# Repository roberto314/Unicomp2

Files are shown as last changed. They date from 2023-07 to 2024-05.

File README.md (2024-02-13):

# UNICOMP #

A modular 8-bit Computer able to recreate (nearly) every microcomputer of the mid 70s to early 80s 
in Hardware without FPGAs (although an FPGA can be added). Can also be used as a teaching tool for:

* VHDL or Verilog
* C
* RTOS (STM32F401 runs ChibiOS Link: https://www.chibios.org)
* Python
* bash and linux in general (Olimex board runs linux with fbterm and tmux)
* Harwaredesign
* Timing of CPUs
* maybe Assembler
* SPI and I2C Interfaces
* CPLDs and FPGAs

It is different from other designs because of these points:

* it uses a 3.3V only Bus,
* it uses fast RAM for chipselect with two byte resolution over the whole 1MB range,
* it uses one SRAM for RAM and ROM replacement (can be write writeprotected) with 512kB (1MB possible),
* it uses a clock generator chip (DS1085) - no more crystals to change,
* it is configureable via STM32 (RAM and ROM content, Clock frequency, chip select lines),
* it can program the CPLDs (only XC9572 and XC9536 tested) from the olimex board - no external programmer and no cables to connect,
* Board size is 100mm x 100mm - no backplane (like the PC/104 standard. Link: https://en.wikipedia.org/wiki/PC/104).
* and maybe most convenient: it can change RAM and ROM content on the fly without crashing the CPU. 
  For example starting the Apple I, going into Basic and uploading the program in about half a second is really nice.

Version 2.00

Unicomp plus Logic Analyzer:
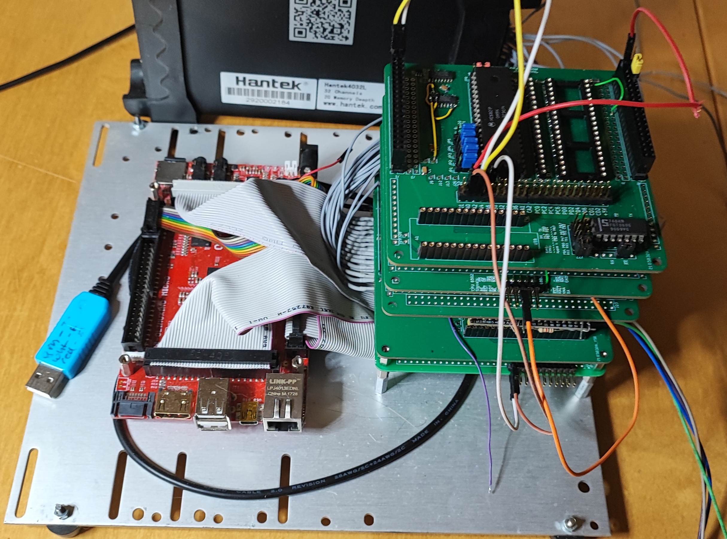
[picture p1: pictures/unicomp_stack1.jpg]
Unicomp plus Logic analyzer


### Unicomp modules ###

* Input board:
	- a simple board to connect the signals to a linux SBC like a Raspberry Pi or an Olimex A20
	- also generates the main clock with a DS1085 chip (in v2 this will be moved to the RAMROM board).
	- no CPLD

* CPU board:
	- can be any 8-bit CPU (6502, 6802, 6809, 68008, 6803, 8051,...)
	- a CPLD (XC9572) for clock generation and glue logic

6502 Board:
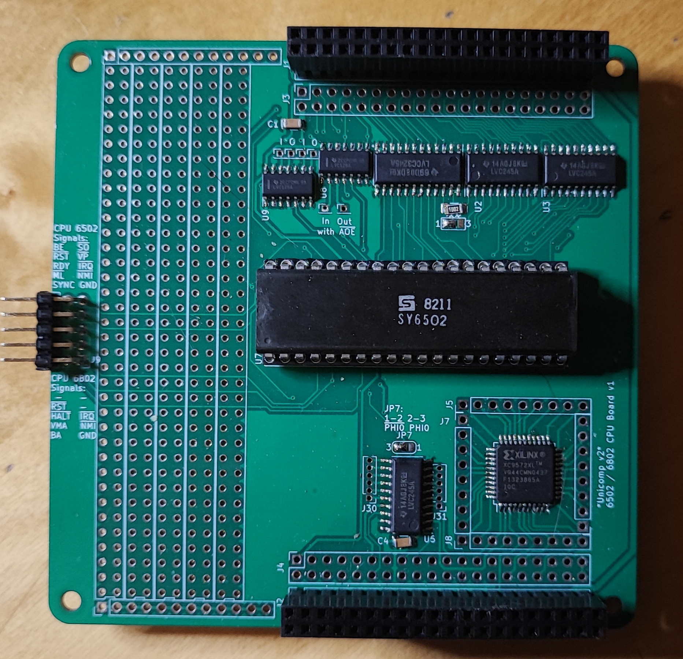
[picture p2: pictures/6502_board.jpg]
6502 Board


* Multi Serial boaŕd:
	- suggested chip select #0
	- two chip selects on board (second one not connected, but broken out)
	- can be used with the following serial interface chips: MC6850, MOS6551, MOS6552 or pin compatible
	- SRAM for address decoding

Multi Serial Board:
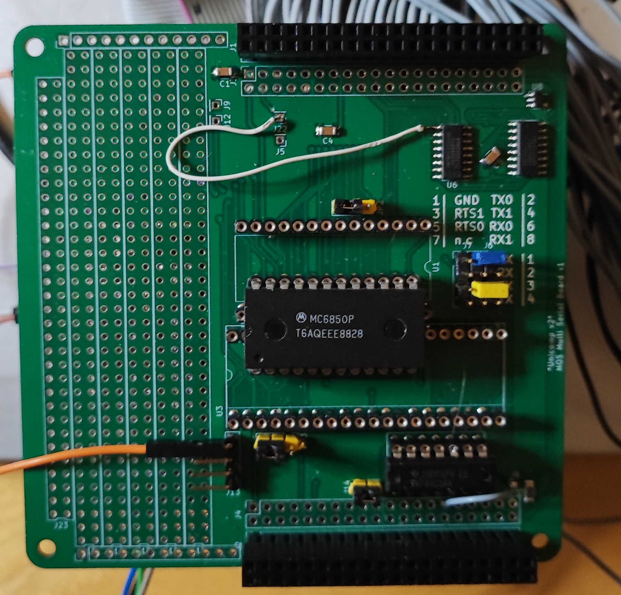
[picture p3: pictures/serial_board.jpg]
Multi Serial Board


* Multi Parallel boaŕd:
	- suggested chip select #1
	- two chip selects on board
	- can be used with the following parallel interface chips: MC6820, MC6821, MOS6520, MOS6521, MOS6522, MOS6526, MOS8520, MOS6532 in the first slot
    - the first slot can additionally mimic a MOS6530
	- the second slot can accommodate a MOS6522 or pin compatible
    - SRAM for address decoding

* RAMROM board:
	- chip select fixed at #14 (for chipselect RAM) and #15 (rom content)
	- 512k of SRAM plus an extra RAM for address decoding
	- a STM32F401 'blackpill' board to fill the SRAMs with data over USB port from the SBC
	- USB shell on the STM32 to change ROM content on the fly
	- also configures the Address Range of all peripheral modules

* Prototype board:
	- empty board for prototyping
	- no CPLD
    - SRAM for address decoding

* MAX-II (EPM240) board:
	- CPLD plus Buffers

* self made module:
	- chip select can be any non-used line in the Range from 0 to 13.
	- size is 100mm x 100mm
	- there is the prototype board in the repository for the position of the connectors and also the labels (pinout)

### Configuration RAM ###

The configuration is done with 128kx8 fast ram on the peripheral boards. These will be configured from the STM32F401.
One bit is for one Output (of which there are two) and for two addresses (resolution for chipselect is 2 bytes).
The cs = 15 is for writing the main RAM, cs = 14 is the chip select for the RAMROM board.
The rest is free. With two chip select lines per board these are 28 lines.
One byte in the mapping ram has the following format:

| 7 | 6 | 5 | 4 | 3 | 2 | 1 | 0 | Bits |
|---|---|---|---|---|---|---|---|---|
| 7,6  | 5,4  | 3,2  | 1,0  | 7,6  | 5,4  | 3,2  | 1,0  | Address |
| /CS0 | /CS0 | /CS0 | /CS0 | /CS1 | /CS1 | /CS1 | /CS1 | Peripheral |
| /CS  | /CS  | /CS  | /CS  | WP | WP | WP | WP | RAMROM |

So 128k are good for 128kx8 Bytes of Addressspace (=1MByte)
The data gets transferred to the STM32 in compact form. Only the Start address, the chipselect and the bitmask (which is Low-active) for every addresses where someting changes are transferred.
A 0xFE for a bitmask means Peripheral chipselect /CS1 is active for two addresses. If the board is the RAMROM board the low nibble is Writeprotect (Hi-active).

A simple configuration block looks líke this:

    (RAM: 0-9FFF, ACIA0: A000-A001, ACIA1: A010-A011, ROM: C000-FFFF)

    00 00 00 0E 00  :  RAM
    00 A0 00 00 EF  :  ACIA0
    00 A0 02 FF FF  :  HOLE
    00 A0 10 00 FE  :  ACIA1
    00 A0 12 FF FF  :  HOLE
    00 C0 00 0E 0F  :  ROM
    01 00 00 FF FF  :  END
    00 00 00        :  noting further

### Working Recreations of old computers ###

| Name | prim. IO | chips used | os | weblink |
|---|---|---|---|---|
| Grant Searle 6502 board  | serial | MOS6502, MC6850 | OSI Basic |Link: http://searle.x10host.com/6502/Simple6502.html |
| Daryl Rictor 6502 board  | serial | MOS6502, R6551 | SBC-2 (monitor only) |Link: https://sbc.rictor.org/info2.html |
| Daryl Rictor 6502 board  | serial | MOS6502, MC6850 | SBC-2 (monitor only) |Link: https://sbc.rictor.org/info2.html |
| SYM1 | serial | MOS6502, UM6532 | SYM1 ( +BASIC +RAE) |Link: http://retro.hansotten.nl/6502-sbc/synertek-sym-ktm/sym-1/ |
| KIM1 | serial | MOS6502, UM6532 | KIM1 |Link: http://retro.hansotten.nl/6502-sbc/kim-1-manuals-and-software/ |
| Apple I | serial | MOS6502, MĆ6821 (plus Arduino)| Wozmon + BASIC |Link: http://retro.hansotten.nl/6502-sbc/apple-1/ |
| Motorola MEK D2 | serial | MC6802, MĆ6850 | newbug, xswtbug, mondeb |Link: https://www.retrotechnology.com/restore/smithbug.html |
| Motorola MEK D1 | serial | MC6802, MĆ6821 (plus Arduino) | Mikbug |Link: https://www.retrotechnology.com/restore/smithbug.html |
| Heathkit ET3400 | serial | MC6802, MĆ6850 | MITS BASIC, TSC MicroBASIC,... |Link: https://github.com/jefftranter |
| SWTPC 6800 | serial | MC6802, MĆ6821 (plus Arduino) | Mikbug |Link: https://deramp.com/swtpc.com/ |
| SWTPC 6800 | serial | MC6802, MĆ6850 | SWTBUG, SWTBUGA, Mondeb, xSWTBUG |Link: https://deramp.com/swtpc.com/ |
| DREAM 6800 | BAS (Video) | MC6802, MAX-II | DREAM operating System (Chip8) |Link: http://www.mjbauer.biz/DREAM6800.htm |
| HD6303 Board (Eric Klaus)| serial | HD6303 | Monitor +BASIC |Link: https://sites.google.com/site/ericmklaus/projects-1/hd6303cpuboard |
| MC3 Computer | serial | HD6303 | Monitor |Link: https://www.waveguide.se/?article=mc3-a-diy-8-bit-computer |
| Psion Organizer I | LCD | HD6303 | Psion OS |Link: https://www.jaapsch.net/psion/index.htm |

### linux single board computer (SBC) ###

I uses an olimex A20 SBC (olinuxino A20) which has a lot of peripherals (4x UART, 2x SPI, 2x I2C, a lot of GPIOs, SATA, 2x SDCARD, VGA, HDMI, LAN,...)
and it is open hardware. The board is connected with three 40 pin cables (like old IDE cables) plus two 10 pin cables to the input board.

To access all the peripherals i use python with the pyA20 library here: https://pypi.org/project/pyA20/   
The debian image (bullseye minimal) can be found at: http://images.olimex.com/release/a20/   
To configure the image after downloading there are helper scripts in the unicomp folder under: olimex Board/config 
I use fbterm and tmux for a nice terminal output. Here are some pictures:   
tmux main window:
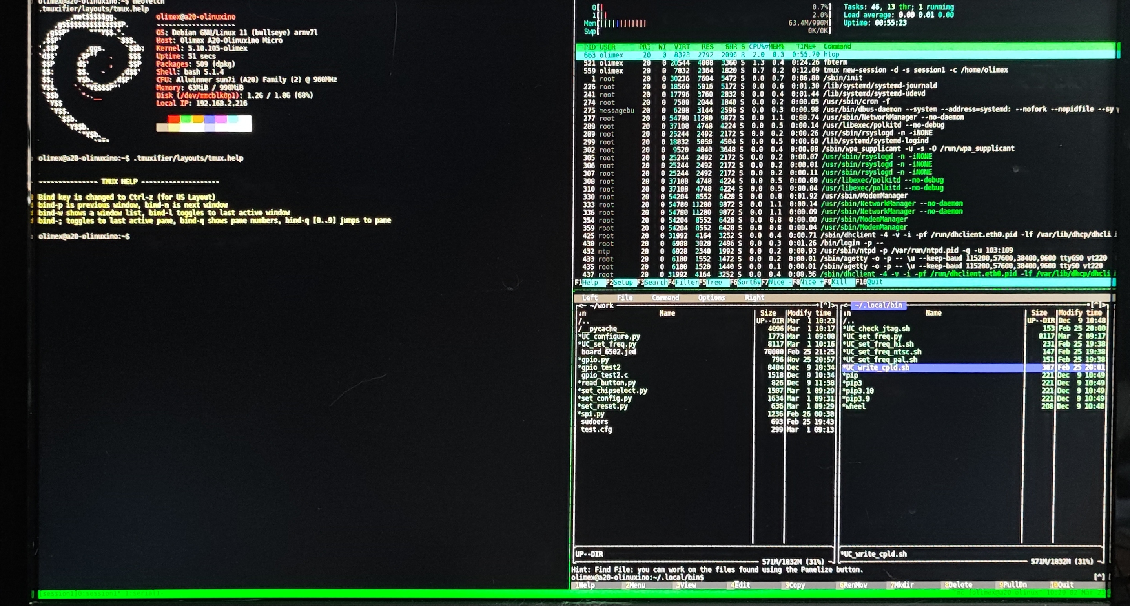
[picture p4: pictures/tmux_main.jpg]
tmux main window


tmux serial window:
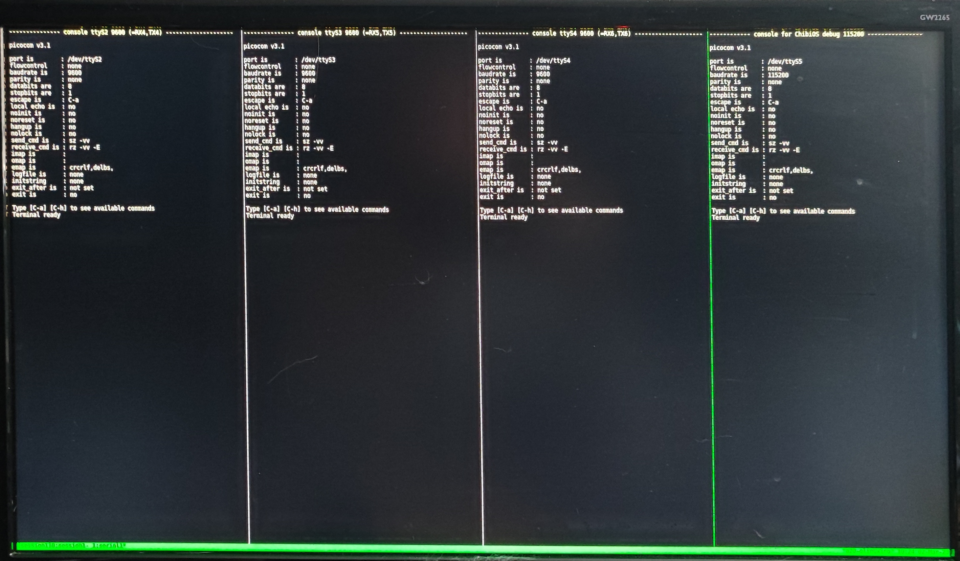
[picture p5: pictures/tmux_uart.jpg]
tmux uart window


### python helper scripts ###

-- all scripts have to be executed with sudo bacause of direct hardware access!

* set_reset.py [0,1,xx]
	- sets the reset line high or low (low = active)
	- if value is anything other than 0 or 1 then a reset of approx. 10mS will be performed.

* UC_check_jtag.sh
	- looks for devices (CPLDs) in the JTAG chain.

* UC_write_cpld.sh [0..?] [.jed file]
	- writes the .jed file to the selected devices
	- Example: sudo UC_write_cpld 0 filename.jed - writes .jed file to cpld zero

* Prepare new SD-Card:
    - copy image to sd-card:
    sudo dd if=A20-OLinuXino-bullseye-minimal-20230515-130040.img of=/dev/sdb bs=1k status=progress
    - start olimex and login with 'olimex/olimex'
    - change password with: 'sudo passwd olimex' to something shorter like 'olim'
    - alternatively: delete passwird: 'sudo passwd -d olimex'
    - make update: 'sudo apt update && sudo apt upgrade'
    - install minimal components: 'sudo apt install git mc'
    - clone github repository: 'git clone https://github.com/roberto314/Unicomp2.git'
    - open midnight commander: 'mc'
    - navigate into Unicomp2/olimex_board/config
    - Run script: 'install_software.sh'
    - Run script: 'copy_files.sh'
    - restart

### CPLD programming ###

* compiling the vhdl (or verilog) code must be done on a computer with the Xilinx ISE 14.7 toolchain installed.
 Link: https://www.xilinx.com/support/download/index.html/content/xilinx/en/downloadNav/vivado-design-tools/archive-ise.html

* compiling itself can be done inside ISE or with the supplied makefile (look inside the bord directory in cpld firmware)

* a simple **make** will compile the firmware and a **make transfer** will transfer the file to the sbc (if you changed the ip address to your address inside the makefile and the path inside project.cfg)

* on the sbc in the work folder one can find the .jed file. For programming type: **UC_write_cpld [JTAG-position] [filename.jed]**

### Used Software and OS ###

* Linux Mint (20.3 cinnamon) (Link: https://linuxmint.com/)
* Sublime Text 3 (Link: https://www.sublimetext.com/)
* 010 Editor (Hex Editor) (Link: https://www.sweetscape.com/010editor/)
* Chibi Studio 20 (IDE for ChibiOS) (Link: https://www.chibios.org/dokuwiki/doku.php?id=chibios:products:chibistudio:start)
* Wavedrom (2.9.1) (Link: https://wavedrom.com/)
* Pulseview (0.5.0-nightly Appimaage) (Part of sigrok) (Link: https://sigrok.org/wiki/PulseView)
* Logisim-Evolution (3.8.0) (Link: https://github.com/logisim-evolution/logisim-evolution)
* Quartus (13.0.1 Build232 Web Edition - 64 Bit) for MAX-II
* Xilinx ISE (14.7 - 64 Bit) for XC9572

### Used Hardware ###

* Oscilloscope: Rigol DS1054Z (4 channel)
* Logic Analyzer: Hantek 4032L (32 channel)

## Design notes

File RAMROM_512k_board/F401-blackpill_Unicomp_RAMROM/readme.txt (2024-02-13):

*****************************************************************************
** ChibiOS/RT port for ARM-Cortex-M4 STM32F407.                            **
*****************************************************************************

** TARGET **

The demo runs on an STM32F411 or STM32F401 blackpill board.
(25MHz Crystal)
Serial Port over USB (also Debug Interface).
Serial 115200 Bd

Build:
Build with eclipse or simply type "make" in the code folder.

-----------------   WORK in Progress

Functions:

Pinout:
PA0  - OFF/ON (write enable strobe)
PA1  - SEL4 (which chip gets the write enable)
PA2  - TX2 (Console + Debug)
PA3  - RX2 (Console + Debug)
PA4  - /CS_FLASH - free (/DATOE in prev. Version)
PA5  - SCK1
PA6  - MISO1
PA7  - MOSI1
PA8  - CNT (count up)
PA9  - /MWR (not used)
PA10 - /RAMCSOR (RAM CS override) - not used
PA11 - USD DM (Ostrich)
PA12 - USB DP (Ostrich)
PA13 - SWDIO
PA14 - SWCLK
PA15 - /MRD (not used)

PB0  - free
PB1  - free
PB2  - /DATOE
PB3  - free
PB4  - PWM Output (TIM3/1)
PB5  - free
PB6  - SCL
PB7  - SDA
PB8  - CTRL1 (CTRL1 for clock chip)
PB9  - /BUSFREE (signal if bus is free)
PB10 - TRST (Target Reset)

PB12 - /PLD (Parallel Load into shift register)
PB13 - /CNTOE (Counter Output on)
PB14 - CPR (Counter Latch)
PB15 - /MRC (Counter Reset)

PC13 - SEL0 (which chip gets the write enable)
PC14 - SEL1 (which chip gets the write enable)
PC15 - SEL2 (which chip gets the write enable)

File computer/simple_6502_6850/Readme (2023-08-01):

Source: https://sbc.rictor.org/sbcos.html
Daryl's Computer Hobby Page
Here is a list of my operating system's commands:

This is a cut-down version from this thread:
http://forum.6502.org/viewtopic.php?f=2&t=2566

65C02 Monitor V5.1 Ready
with Enhanced Basic Interpreter (c) Lee Davison
(Press ? for help)

Syntax = {} required, [] optional, HHHH hex address, DD hex data

[HHHH]{.HHHH}{Return} - Hex dump range of addresses (16 per line)
[HHHH]{:DD}[ DD]{Return} - Change data bytes
[HHHH]{G}{Return} - Execute a program (use RTS to return to monitor)
{HHHH.HHHH>HHHH{I}{Return} - move range at 2nd HHHH down to 1st to 3rd HHHH
{HHHH.HHHH>HHHH{M}{Return} - Move range at 1st HHHH thru 2nd to 3rd HHHH
[HHHH][ HHHH]{Q}{Return} - Text dump address(s)
[HHHH]{.HHHH}{Q}{Return} - Text dump range of addresses (16 per line)
{R}{Return} - Print register contents from memory locations
{V}{Return} - Monitor Version

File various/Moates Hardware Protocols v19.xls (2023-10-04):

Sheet: Overview
Control Commands for Moates.Net Hardware
Note: Commands should be sent via standard serial port communication 8-N-1. Don't use wait states, delays, or anything like that. Spew bytes/strings to the port, and poll the port mercilessly for responses. You shouldn't see lag any more than 10-20 mS at the most except when commands take time to execute (programming/erasing chips). Checksums (CS) are just 8-bit additive of the rest of the request, no carry. Values such as 'O' are alphanumeric. Lowercase letters are hex numeric. Other values are mostly hex. A response of '?' or other when expecting 'O' or other valid response indicates either a failed checksum, failed command execution, or other failure. Also, when uploading content for emulation, if you're uploading a 16k or 32k file, please keep in mind that it needs to go to the 'end' of the 64k emulation space. For instance, if you upload a 32k file, upload it from 8000-FFFF.

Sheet: Unicomp
Unicomp v2 Command Set | This is based on the Ostrich (v1) Protocol!
Description | Send | Receive | Notes
Request version. | 'V'+'V' | x+y+A (ex. 10+07+'O') | x is typically 15 for Unicomp or Nucleo NVRAM Prog., 10 for Ostrich, 5 for BURN1, and 2 for AutoProm. Y will vary with firmware revision. A will be an alphanumeric, and will be A for APU1, O for Ostrich, N for Nucleo NVRAM Programmer, U for Unicomp and B for BURN1 typically. | implemented in Python script | implemented in C code
Write to a memory area, non-disruptive to target device operation. | 'W'+n+MSB+LSB+B1+..+Bn+CS or 'W'+n+RB1+RB2+MSBc+LSBc+B1c+..+Bn+CS when crypted. | 'O' | In the case of the Ostrich, this writes to the bank area that is selected for R/W (think of as the MMSB). In all cases, it sends 'n' bytes B1…Bn starting at emulation address MSB:LSB. For 256 bytes, use n=0. | implemented in Python script | implemented in C code
Reads from an emulation memory area. Is usually disruptive to the emulation. | 'R'+n+MSB+LSB+CS or 'R'+n+RB1+RB2+MSBc+LSBc+CS with B1e+..+Bne+CS as response when crypted. | B1+..+Bn+CS | In the case of the Ostrich, this reads from the bank area that is selected for R/W (think of as the MMSB). In all cases, it returns 'n' bytes B1…Bn starting at emulation address MSB:LSB. For 256 bytes, use n=0. |  | implemented in C code
Bulk Write to memory, very fast. | 'Z'+'W'+n+MMSB+MSB+B1+..+B(n*256)+CS or 'Z'+'W'+n+RB1+RB2+MMSBc+MSBc+B1c+..+B(n*256)c+CS when crypted. | 'O' | Rapid write, sends n blocks of 256 bytes to memory starting at MSB:LSB. Great for initial uploads, typically 4k at a time (n=16). Theoretically can do a full 64k (n=256) all in one block, but speedups are only seen up to about 4k in terms of USB bus overhead elimination. The MMSB value will only be taken into account when the bank response of a 'B'+'R'+'R'+ CS = 8. |  | implemented in C code
Bulk Read from memory, very fast. | 'Z'+'R'+n+MMSB+MSB+CS or 'Z'+'R'+n+RB1+RB2+MMSBc+MSBc+CS with B1c+..+B(n*256)c+CS as response when crypted. | B1+..+B(n*256)+CS | Rapid read, retrieves n blocks of 256 bytes from memory starting at MSB:LSB. Great for reading back full binary. Same guidelines apply as for the 'Z' bulk write command. The MMSB value will only be taken into account when the bank response of a 'B'+'R'+'R'+ CS = 8. | implemented in Python script | implemented in C code
Write Configuration Data | 'C’+n+B1+..+Bn+CS | 'O’ | Send Configuration Data (max. 256 Bytes) | implemented in Python script | implemented in C code
Write Clock Data | 'DW’+11+B1+..+Bn+CS | 'O’ | Receive Clock Data (11 Bytes) | implemented in Python script | implemented in C code
Read Clock Data | 'DR’+CS | 'O’ | Send Clock Data (11 Bytes) | implemented in Python script | implemented in C code
Write digital Pins | 'P’+1+B1+CS | 'O’ | Send Pin Data (one Byte) | implemented in Python script | implemented in C code
Select which emulation bank to read/write to/from. | 'B'+'R'+n+CS | 'O' | Valid values for n are 0-8. This setting will be persistent until power cycle, at which time it will reset to default of n=0.And you can send an '8' which will enable/present the entire 4 mbit of memory to the target device. And make the MMSB effective during bulk read/write cycles. | implemented in Python script | implemented in C code
Select which bank to emulate from and make it persistent upon power cycle. | 'B'+'S'+n+CS | 'O' | Valid values are from 0-8, and you can send an '8' which will enable/present the entire 4 mbit of memory to the target device. This is useful for multi-bank Ford applications in particular (EEC-V). Don't over-use this, since other applications might not use multibank and you want to return the emulator to a known state. Also, overuse will wear out the internal EEPROM where this info is stored. | implemented in Python script | implemented in C code
Read back which emulation bank is selected for read/write operations. | 'B'+'R'+'R'+CS | n | Values for n are 0-7. This is to check to see where your read 'R' and write 'W' commands will take effect. | implemented in Python script | implemented in C code
Select which bank to emulate from, ie. which one to present to car's computer (volatile selection, lost on power cycle). | 'B'+'E'+n+CS | 'O' | Valid values are from 0-7, and you can send an '8' which will enable/present the entire 4 mbit of memory to the target device. This is useful for multi-bank Ford applications in particular (EEC-V). | implemented in Python script | implemented in C code
Read back which bank is selected for emulation in the volatile sense. | 'B'+'E'+'R'+CS or 'B'+'E'+'E'+CS | n | Valid n values from 0-8. This is good for 'seeing where you're at' in terms of bank selection. This is the volatile value that is lost on startup. | implemented in Python script | implemented in C code
Read back which bank is selected for emulation in the persistent non-volatile sense. | 'B'+'E'+'S'+CS | n | Valid n values from 0-8. This is good for 'seeing where you're at' in terms of bank selection. This is the stored/startup value. | implemented in Python script | implemented in C code
Query serial number | ‘N’+’S’+CS | B0+B1+..+B8+CS | B0 is vendor ID byte, B1..B8 is serial number | implemented in Python script | implemented in C code
Change vendor ID byte | ‘N’+x+B1+..+B8+CS | 'O' | x is new vendor ID byte, B1..B8 is current serial number (must match)
Change serial number | ‘N’+’n’+C1+..+C8+CS | 'O' | C1..C8 is new serial number
Legacy Commands
Change baud rate. | 'S'+n+CS | 'O' | Valid values for n are 0 (920k) and 7 (115k=default, resets on powercycle). Initial response will be at the 'old' baud rate, and subsequent communication will be expected and occur at the 'new' baud rate. It is good practice to scan (using 'V'+'V') at both baud rates when looking for the device. For revision 10.12.O firmware, value is locked at 0, 921.6k. Return from attempt will be 'O', but divisor of 0 will stick. To use default of 115.2k and allow changes, use firmware 10.10.O or older. | implemented in Python script | implemented in C code
Write to a memory area, non-disruptive to target device operation. | 'w'+n+MSB+LSB+B1+..+Bn+CS | 'O' | Sends 'n' bytes B1…Bn starting at emulation address MSB:LSB. For 256 bytes, use n=0.
Write to a memory area, non-disruptive to target device operation. Use legacy 'block' mode. | 'X'+n+MSB+LSB+B1+..+Bn+CS | CSmsb+CSlsb | Sends 'n' bytes B1…Bn starting at emulation address MSB:LSB. For 256 bytes, use n=0. Return is the two-byte carry checksum of the actual B1..Bn data packet (not including header etc).
Reads from an emulation memory area. Is usually disruptive to the emulation. | 'r'+n+MSB+LSB+CS | B1+..+Bn+CS | Returns 'n' bytes B1…Bn starting at emulation address MSB:LSB. For 256 bytes, use n=0.

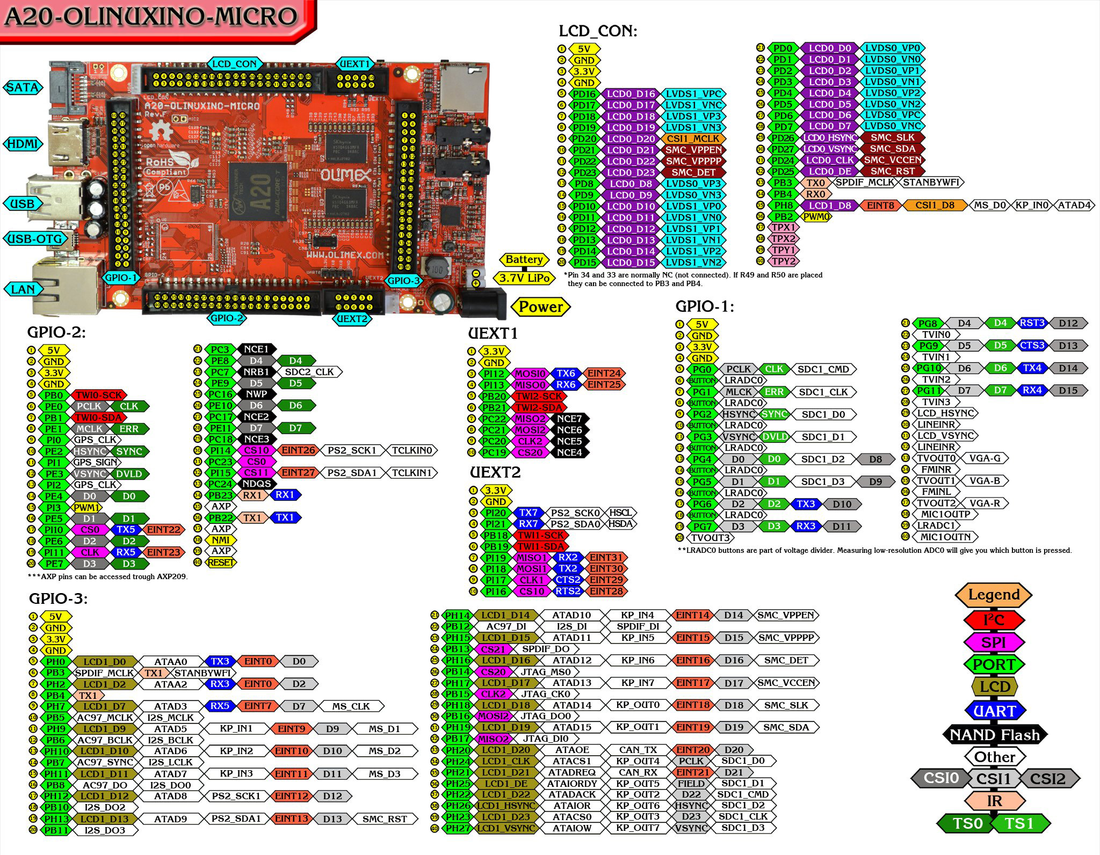
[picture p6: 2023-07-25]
olimex_board/schematic/pinout.jpg

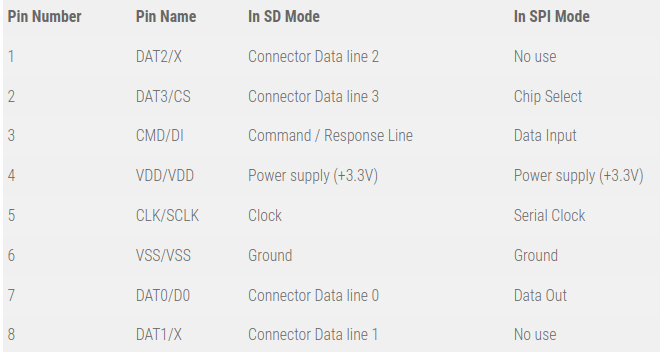
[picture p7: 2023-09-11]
CPLD_board/SD_Pinout.png

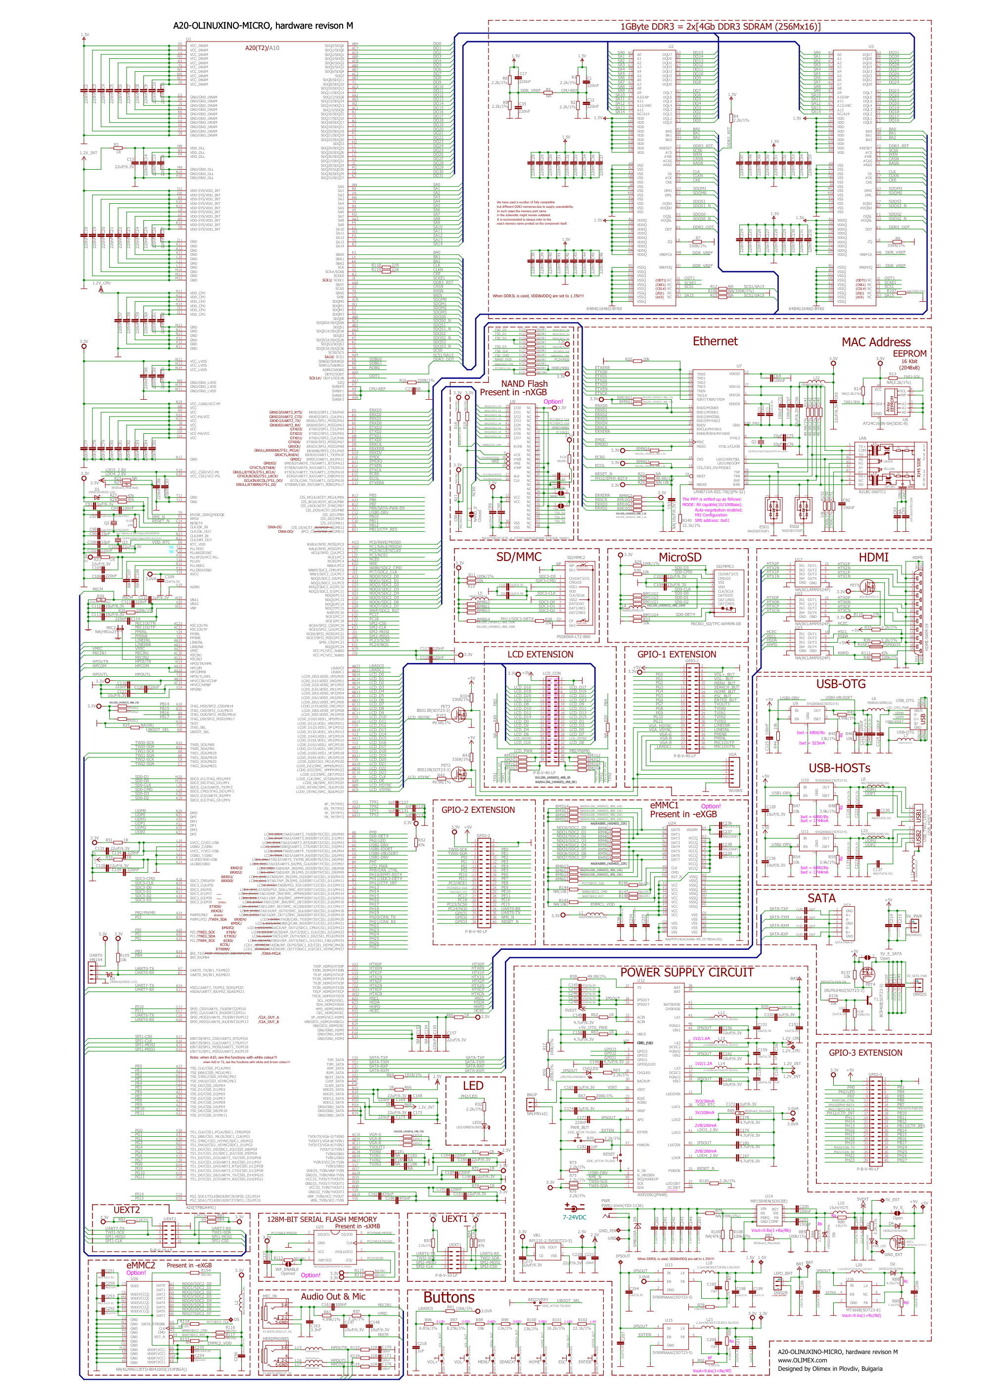
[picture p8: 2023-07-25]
olimex_board/schematic/canvas.png

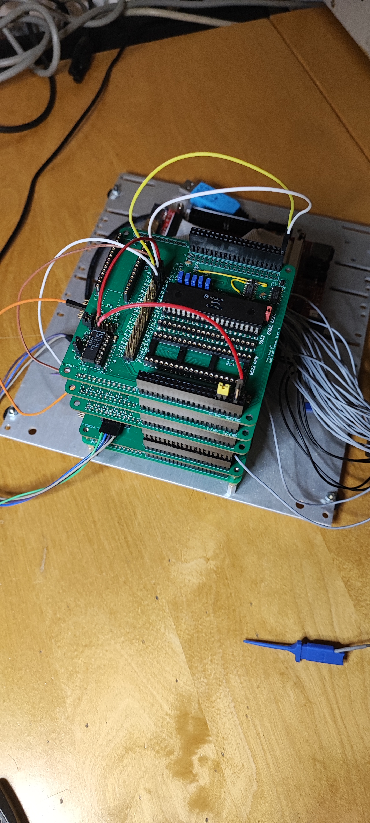
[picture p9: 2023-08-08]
pictures/unicomp_stack_side.jpg

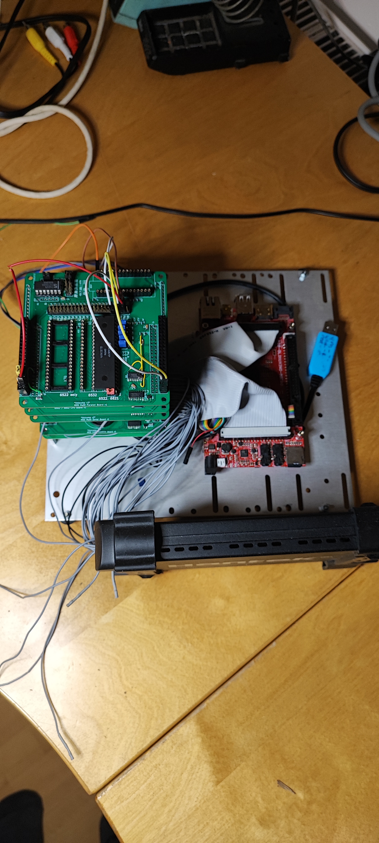
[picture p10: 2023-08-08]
pictures/unicomp_stack_top.jpg

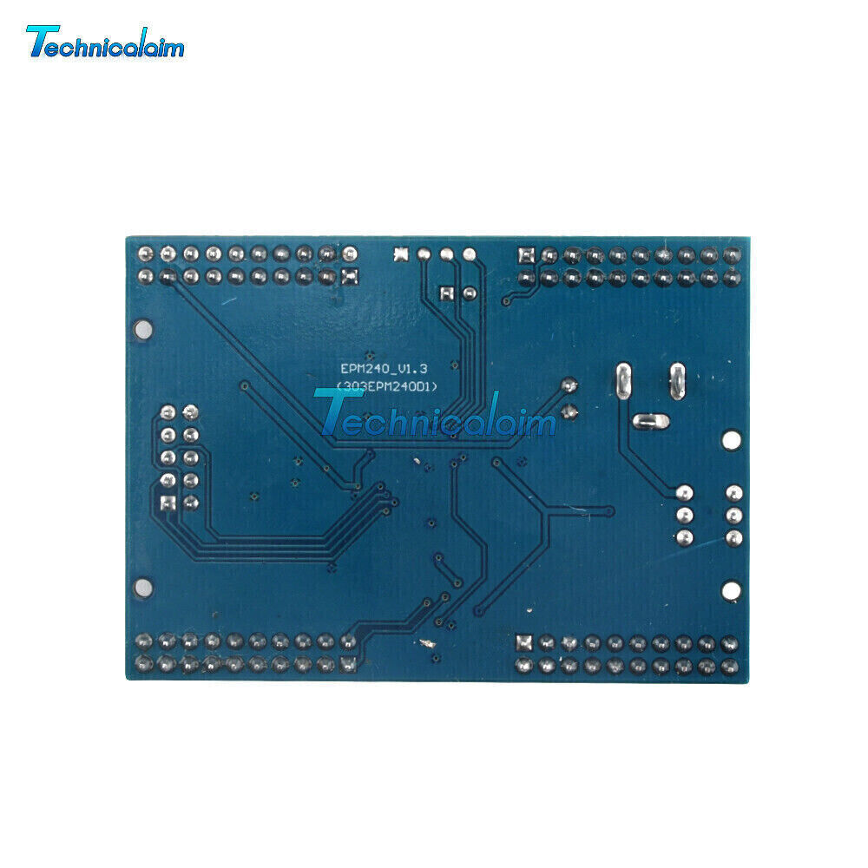
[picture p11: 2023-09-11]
CPLD_board/ebay-board-EPM240_back.jpg

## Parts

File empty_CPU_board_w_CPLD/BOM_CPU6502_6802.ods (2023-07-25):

Id | Designator | Footprint | Quantity | Designation | Supplier and ref
 |  | ICs
3 | U2,U3,U6,U4 | SO-20_5.3x12.6mm_P1.27mm | 4 | SN74ABT245BNSR
16 | U9,U8 | SOIC-14_3.9x8.7mm_P1.27mm | 2 | SN74ACT125DG
19 | U1 | TQFP-44_10x10mm_P0.8mm | 1 | XC9572VQ44
 |  | Sockets and Headers
2 | J8,J5 | PinHeader_1x09_P2.54mm_Vertical | 2 | Conn_01x09
6 | J1,J4,J2,J3 | PinSocket_2x20_P2.54mm_Vertical | 4 | BUS
7 | J31,J30 | PinHeader_1x06_P1.27mm_Vertical | 2 | Conn_01x06
10 | JP9 | PinHeader_1x02_P2.54mm_Vertical | 1 | DOE_En
11 | U7 | DIP-40_W15.24mm_Socket_LongPads | 1 | W65C02SxP
13 | J20,J21 | PinHeader_1x12_P2.54mm_Vertical | 2 | Conn_01x12
14 | J9 | PinHeader_2x05_P2.54mm_Horizontal | 1 | Conn_02x05_Odd_Even
15 | J6,J7 | PinHeader_1x08_P2.54mm_Vertical | 2 | Conn_01x08
17 | JP8 | PinHeader_1x02_P2.54mm_Vertical | 1 | AOE_En
 |  | R and C
1 | C5,C4,C1,C2,C7,C8,C3,C6 | C_1206_3216Metric | 8 | 100n
8 | R3 | R_1206_3216Metric_Pad1.30x1.75mm_HandSolder | 1 | 1k
9 | R4,R7,R5,R6,R2,R8,R1 | R_1206_3216Metric_Pad1.30x1.75mm_HandSolder | 7 | 10k

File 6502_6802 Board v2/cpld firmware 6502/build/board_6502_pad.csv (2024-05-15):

Release 8.1i - Fit P.20131013
Copyright(c) 1995-2003 Xilinx Inc. All rights reserved
5-15-2024 9:11PM
NOTE: This file is designed to be imported into a spreadsheet program
such as Microsoft Excel for viewing | printing and sorting. The comma ' | '
character is used as the data field separator.
This file is also designed to support parsing.
Input file: board_6502.ngd
output file: board_6502_pad.csv
Part type: xc9572xl
Speed grade: -10
Package: vq44
Pinout by Pin Number:
----- | ----- | ----- | ----- | ----- | ----- | ----- | ----- | ----- | -----
Pin Number | Signal Name | Pin Usage | Pin Name | Direction | IO Standard | IO Bank Number | {blank} | Slew Rate | Termination | {blank} | Voltage | Constraint
P1 | PH0 | O | I/O/GCK3 | OUTPUT
P2 | nPH0 | O | I/O | OUTPUT
P3 | CLKF | I | I/O | INPUT
P4 | GND |  | GND
P5 | TIE |  | I/O
P6 | TIE |  | I/O
P7 | TIE |  | I/O
P8 | TIE |  | I/O
P9 | TDI |  | TDI
P10 | TMS |  | TMS
P11 | TCK |  | TCK
P12 | TIE |  | I/O
P13 | TIE |  | I/O
P14 | TIE |  | I/O
P15 | VCC |  | VCCINT
P16 | TIE |  | I/O
P17 | GND |  | GND
P18 | TIE |  | I/O
P19 | TIE |  | I/O
P20 | TIE |  | I/O
P21 | TIE |  | I/O
P22 | TIE |  | I/O
P23 | TIE |  | I/O
P24 | TDO |  | TDO
P25 | GND |  | GND
P26 | VCC |  | VCCIO
P27 | TIE |  | I/O
P28 | TIE |  | I/O
P29 | TIE |  | I/O
P30 | TIE |  | I/O
P31 | nDOE | O | I/O | OUTPUT
P32 | nAOE | O | I/O | OUTPUT
P33 | nMWR | O | I/O/GSR | OUTPUT
P34 | nMRD | O | I/O/GTS2 | OUTPUT
P35 | VCC |  | VCCINT
P36 | RnW | I | I/O/GTS1 | INPUT
P37 | PHI2CPU | I | I/O | INPUT
P38 | TIE |  | I/O
P39 | TIE |  | I/O
P40 | TIE |  | I/O
P41 | TIE |  | I/O
P42 | TIE |  | I/O
P43 | nBUSFREE | O | I/O/GCK1 | OUTPUT
P44 | nRST | I | I/O/GCK2 | INPUT
To preserve the pinout above for future design iterations in
Project Navigator simply execute the (Lock Pins) process
located under the (Implement Design) process in a toolbox named
(Optional Implementation Tools) or invoke PIN2UCF from the
command line. The location constraints will be written into your
specified UCF file

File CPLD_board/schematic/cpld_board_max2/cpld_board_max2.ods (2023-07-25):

Id | Designator | Footprint | Quantity | Designation | Supplier and ref
5 | U1,U2,U4 | DIP-20_W7.62mm_Socket_LongPads | 3 | 74HCT245
 |  | Sockets and Headers
1 | J3,J1 | PinSocket_2x20_P2.54mm_Vertical | 2 | BUS-Master
2 | J6,J4 | PinHeader_2x20_P2.54mm_Horizontal | 2 | BUS-Angled
3 | J9,J2 | PinHeader_1x21_P2.54mm_Vertical | 2 | Conn_01x21
6 | J7,J8 | PinSocket_2x20_P2.54mm_Vertical | 2 | BUS-Master-BO
7 | J11,J12 | PinHeader_1x03_P2.54mm_Vertical | 2 | Conn_01x03
8 | J10 | PinHeader_2x03_P2.54mm_Vertical | 1 | GND
9 | J5 | PinHeader_2x03_P2.54mm_Vertical | 1 | VCC
 |  | R and C
10 | C3,C2,C1 | C_1206_3216Metric_Pad1.33x1.80mm_HandSolder | 3 | 100n

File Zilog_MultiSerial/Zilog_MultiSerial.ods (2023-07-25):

Id | Designator | Footprint | Quantity | Designation | Supplier and ref
21 | U1 | TQFP-44_10x10mm_P0.8mm | 1 | XC9572VQ44
23 | U2 | DIP-14_W7.62mm_Socket | 1 | 74HC14
 |  | Sockets and Headers
1 | J14,J13,J16,J28,J30,J29,J15 | PinHeader_1x01_P2.00mm_Vertical | 7 | .
2 | U4 | DIP-40_W15.24mm_Socket_LongPads | 1 | W65C22NxP
3 | J8,J5 | PinHeader_1x09_P2.54mm_Vertical | 2 | Conn_01x09
4 | J18,J19 | PinHeader_1x32_P2.54mm_Vertical | 2 | Conn_01x32
5 | J1,J4,J2,J3 | PinSocket_2x20_P2.54mm_Vertical | 4 | BUS
6 | J27 | PinHeader_2x05_P2.54mm_Vertical | 1 | .
8 | J12,J9 | PinHeader_1x01_P2.00mm_Vertical | 2 | Conn_01x01
9 | J26 | PinHeader_1x01_P2.00mm_Vertical | 1 | .Conn_01x01
10 | JP3,JP4,JP5,JP6,JP2,JP1 | PinHeader_1x03_P2.54mm_Vertical | 6 | .
13 | J17 | PinHeader_2x11_P2.54mm_Vertical | 1 | Conn_02x11_Odd_Even
14 | J10,J11 | PinHeader_1x06_P2.54mm_Vertical | 2 | .
15 | J20,J21 | PinHeader_1x12_P2.54mm_Vertical | 2 | Conn_01x12
16 | J6,J7 | PinHeader_1x08_P2.54mm_Vertical | 2 | Conn_01x08
20 | U3 | DIP-40_W15.24mm_Socket_LongPads | 1 | 6532
22 | A1 | Arduino_Nano | 1 | Arduino_Nano_v3.x
 |  | R and C
17 | C3,C1,C2,C7,C8,C6 | C_1206_3216Metric | 6 | 100n
19 | C4 | C_1206_3216Metric | 1 | 10n
7 | R1 | R_1206_3216Metric_Pad1.30x1.75mm_HandSolder | 1 | 1k

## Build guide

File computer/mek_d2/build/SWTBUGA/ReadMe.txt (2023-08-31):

SWTBUGA - Augmented SWTBUG

SWTBUGA adds the following enhancements to SWTBUG 1.0
    
  - Similar to the "O"ptional port prefix for the L, P,
    and E commands, a digit prefix (0-7) can be used to
    specify any port for an MP-S board to use for the L,
    P, and E commands (e.g., "2L" to load from port 2).

  - Following a load command, the I/O port address used
    is saved at $A046 which will load into register X if
    a "G" command is used to enter the loaded program.
    This is useful for a two-stage loader.

  - The "D"isk boot command has been fixed by adding a 
    delay for the motor to spin up and a check to see if
    the boot sector was read without errors. The boot
    operation is tried up to ten times. If a DC-x cont-
    roller is not detected, or boot from the DC-x fails,
    the a boot from a Percom controller is attempted
    if it's presence is detected at $C000. If that boot
    option is not present or fails, then control returns
    to SWTBUG.

  - The new "T"est memory command (SUMTEST) is followed
    by the low address and max address+1 of the memory
    range to be tested. The test runs until reset is
    pressed.

SWTBUGA maintains all of the entry points of the 
original SWTBUG. Since SWTBUGA is larger than 1K,
it must be located in an EPROM board on the bus and
the CPU board modified to allow off-board access to
$E000 through at least $E500 or so.

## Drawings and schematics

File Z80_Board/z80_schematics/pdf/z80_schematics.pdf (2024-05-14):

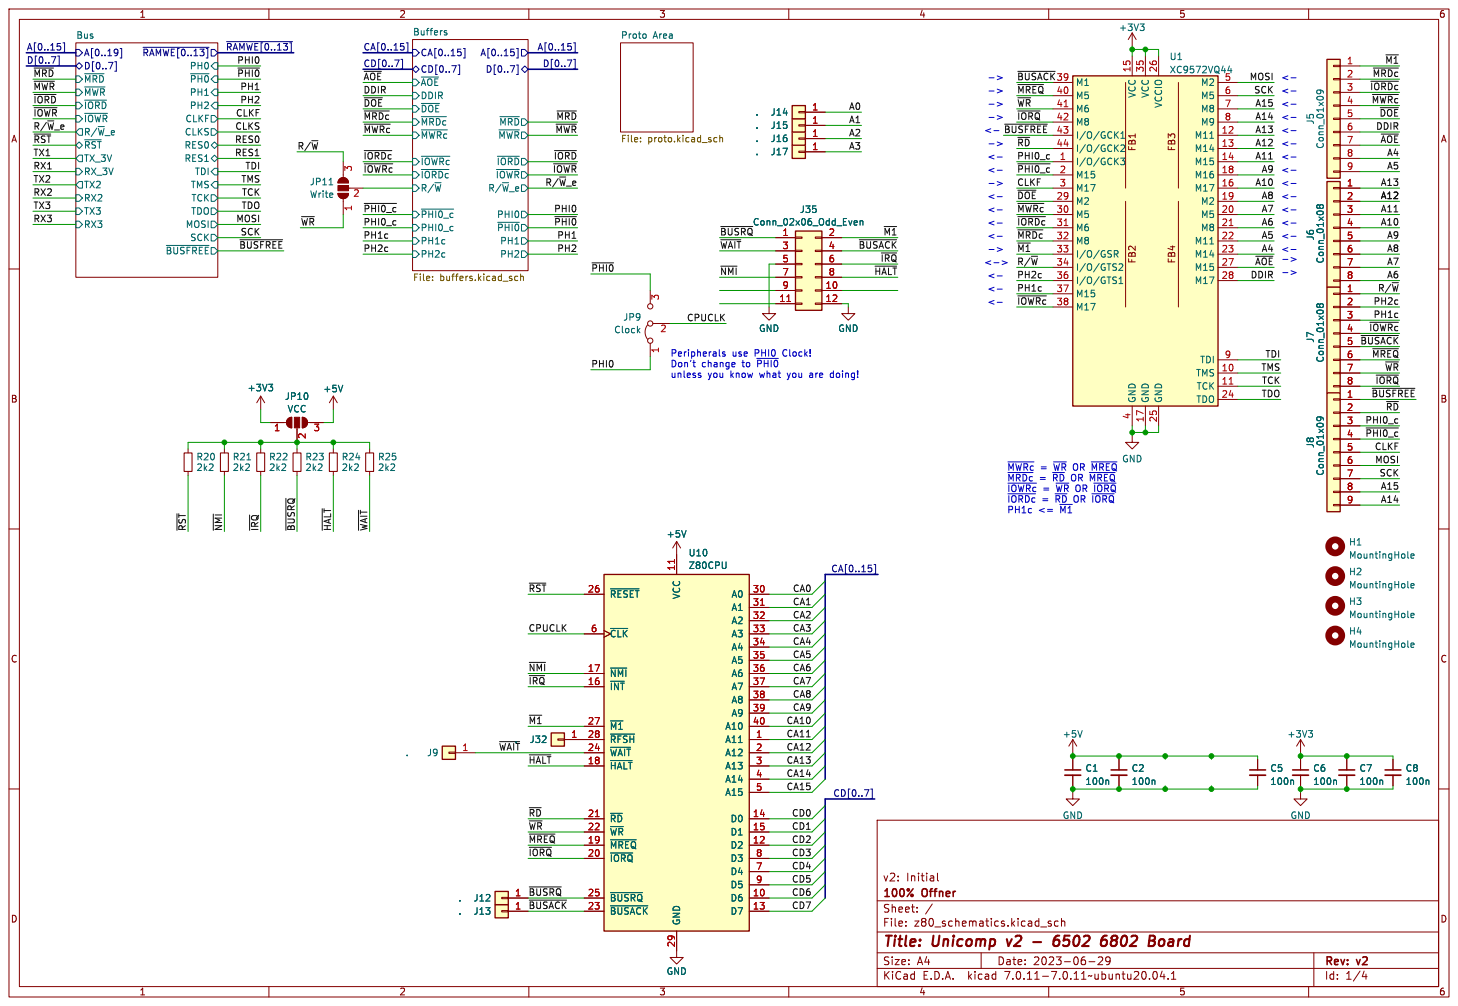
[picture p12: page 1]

~{MRDc}= ~{RD}OR ~{MREQ}
~{IOWRc}= ~{WR}OR ~{IORQ}

~{IORDc}= ~{RD}OR ~{IORQ} PH1c <= ~{M1} GND

Id: 1/4 Title: Unicomp v2 - 6502 6802 Board

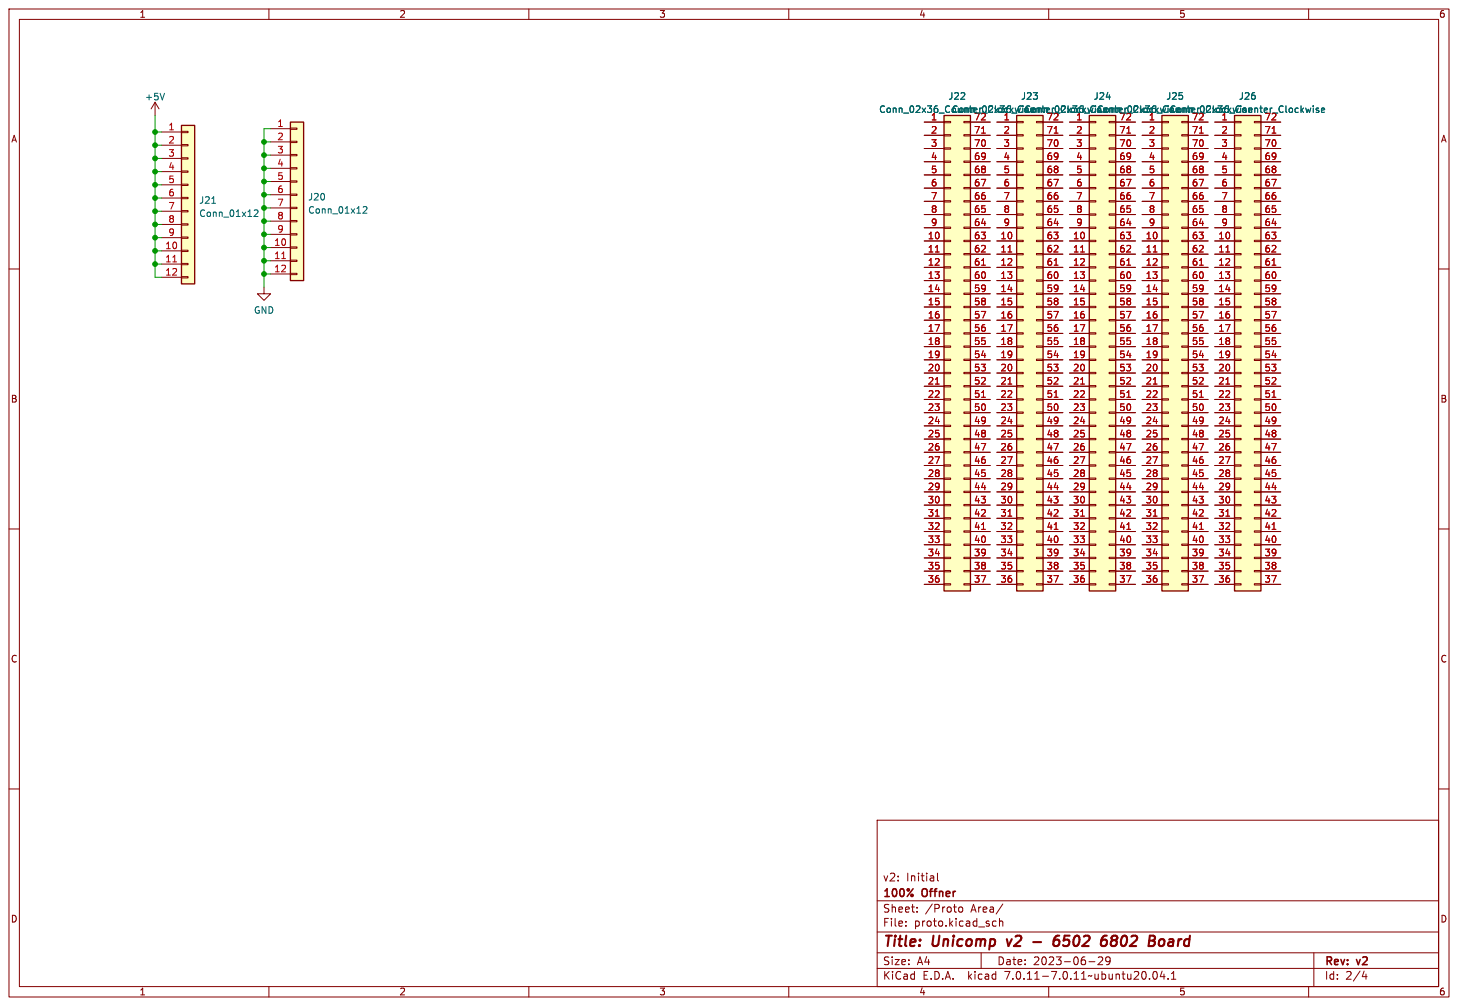
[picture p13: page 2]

Id: 2/4 Title: Unicomp v2 - 6502 6802 Board

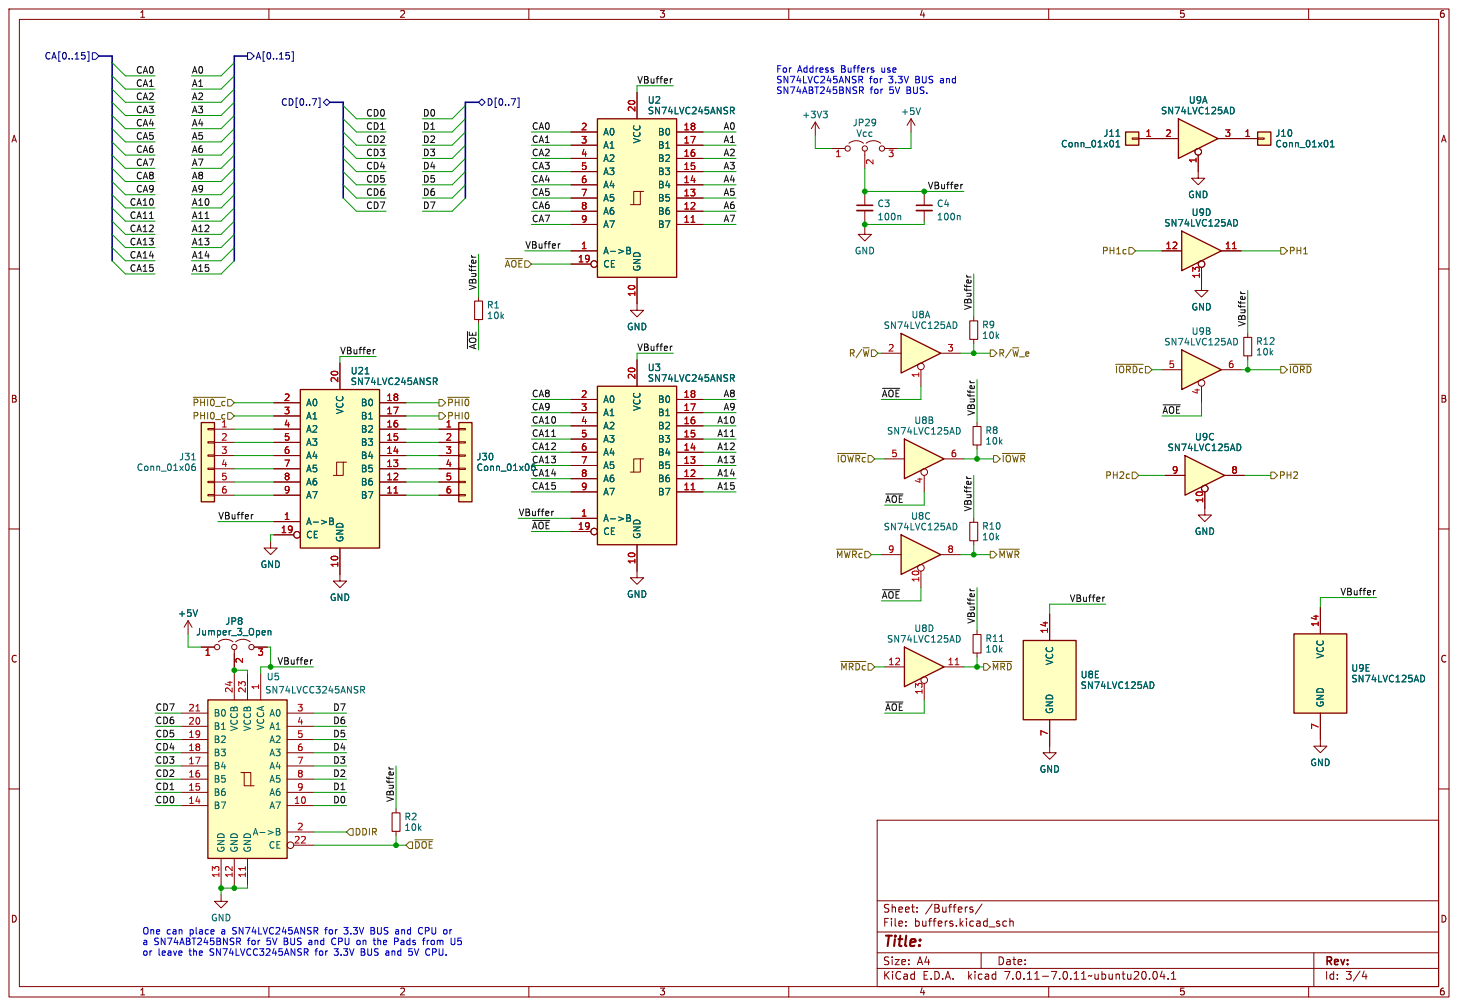
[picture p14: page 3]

For Address Buffers use SN74LVC245ANSR for 3.3V BUS and SN74ABT245BNSR for 5V BUS.
JP29 Vcc ~{MWRc}

7 GND GND GND GND

1 A7 10 GND 11 GND 12 GND 13 B7 14 B6 15 B5 16 B4 17 B3 18 B2 19 A->B 2 B1 20 B0 21 CE 22 VCCB 23 VCCB 24 A0 3 A1 4 A2 5 A3 6 A4 7 A5 8 A6 9 U5 SN74LVCC3245ANSR GND

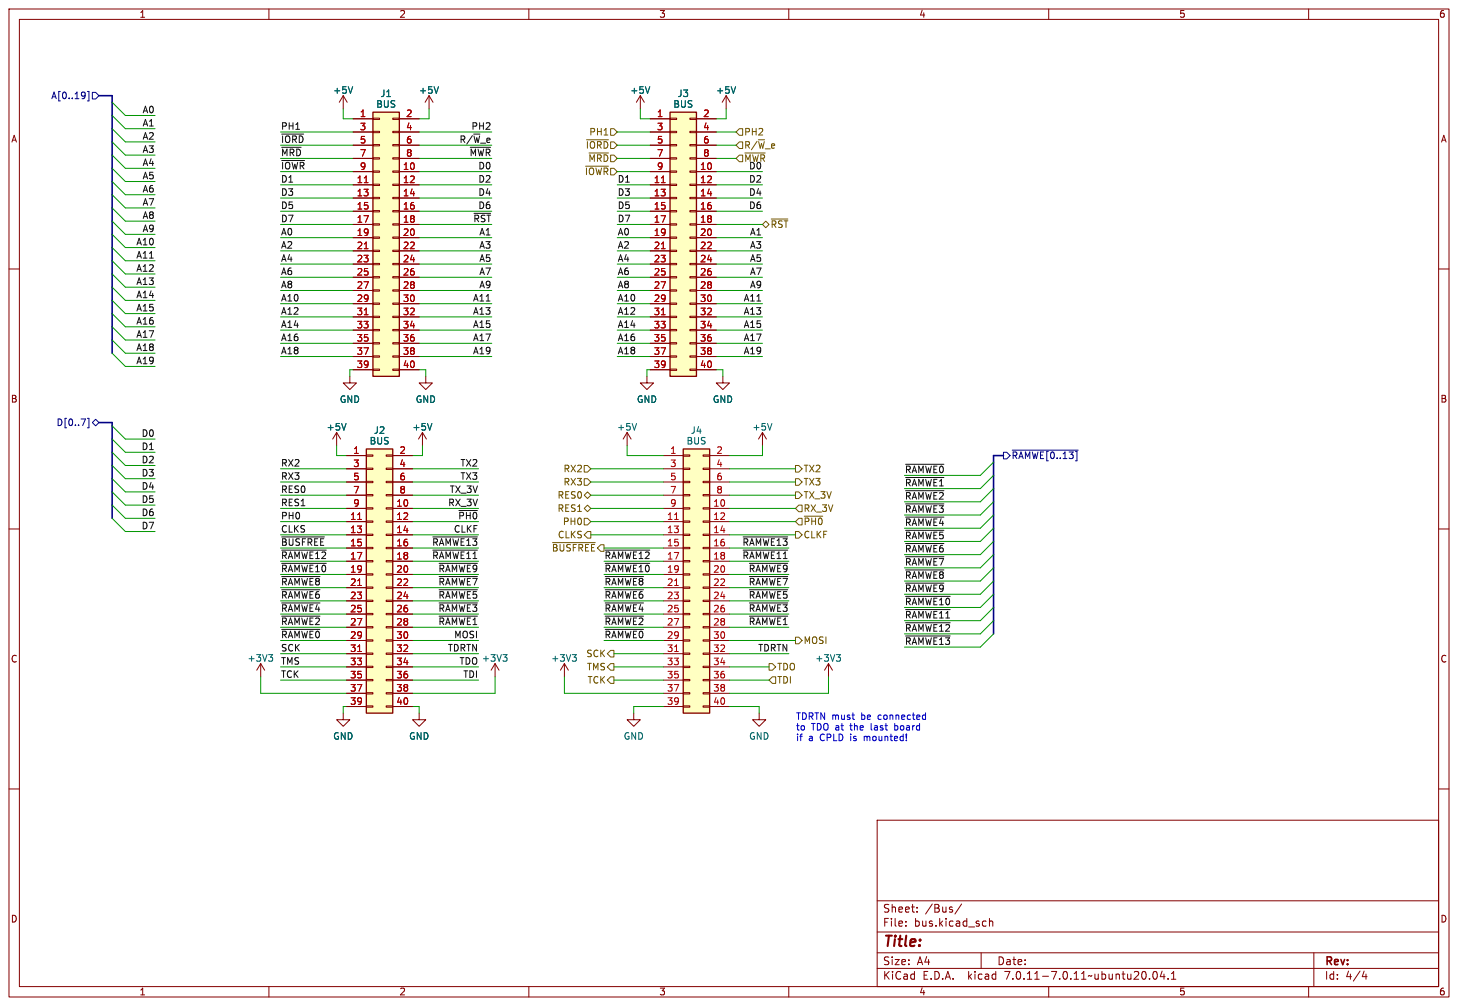
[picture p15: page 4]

to TDO at the last board
if a CPLD is mounted!

Id: 4/4 Title: File: bus.kicad_sch Sheet: /Bus/

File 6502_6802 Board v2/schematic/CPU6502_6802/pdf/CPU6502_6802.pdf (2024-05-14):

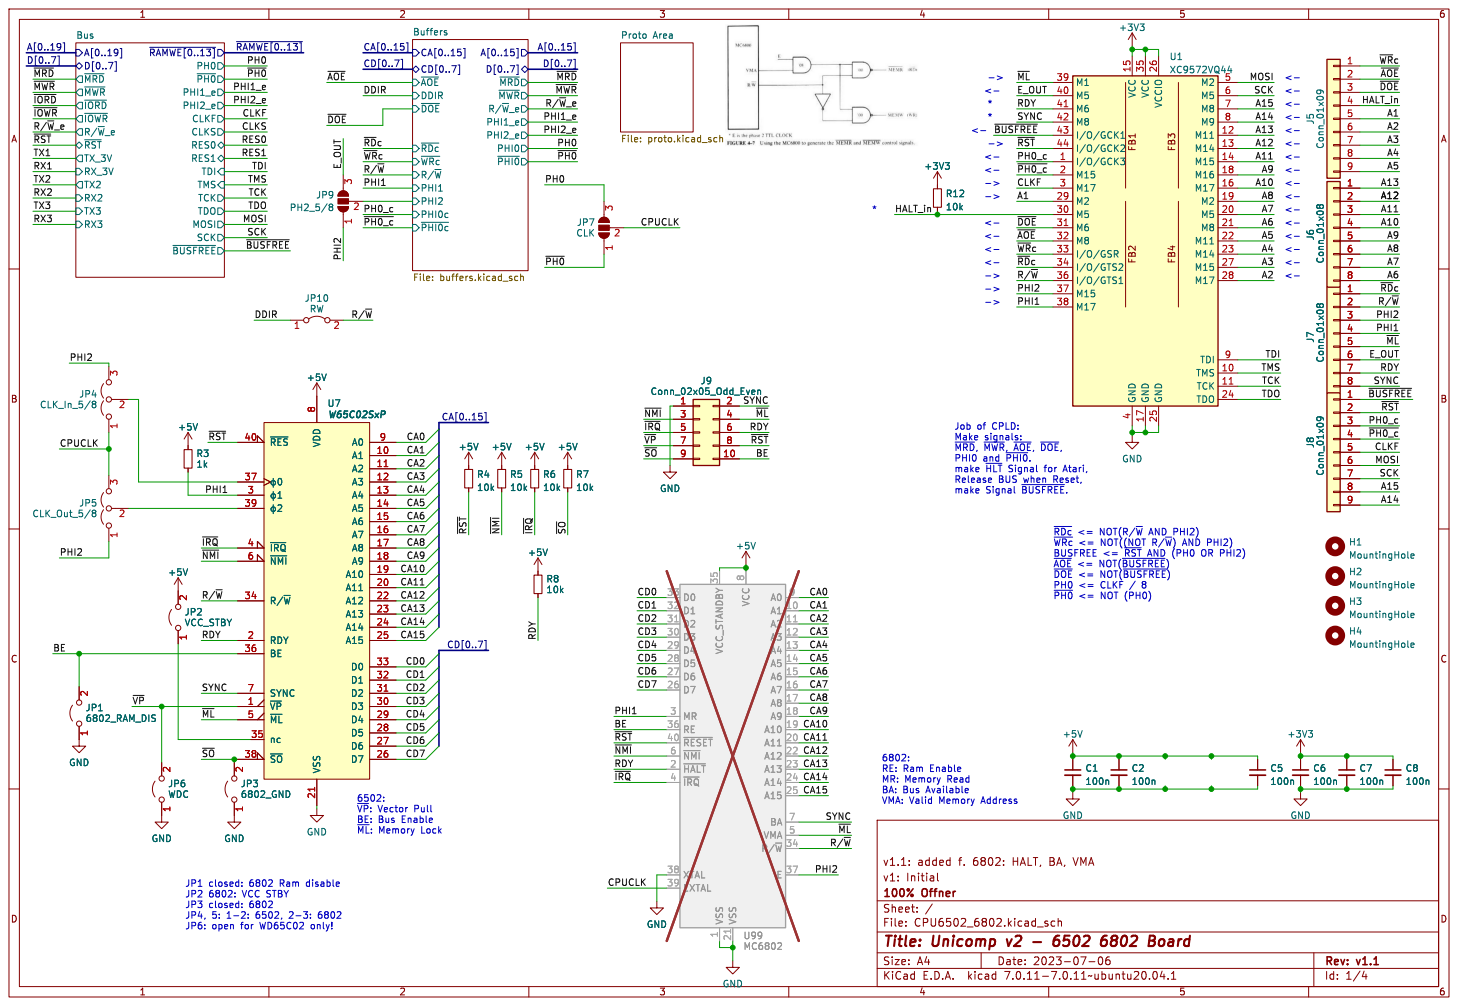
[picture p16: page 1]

I/O/GCK1 43
<- Job of CPLD: Make signals:

~{MRD},~{MWR},~{AOE},~{DOE}, PHI0 and ~{PHI0}. make ~{HLT}Signal for Atari, Release BUS when Reset, make Signal ~{BUSFREE}. ->

~{WRc}<= NOT((NOT R/~{W})AND PHI2) BUSFREE <= ~{RST}AND (PH0 OR PHI2)

~{AOE}<= NOT(~{BUSFREE})
~{DOE}<= NOT(~{BUSFREE}) PH0 <= CLKF / 8 ~{PH0}<= NOT (PH0)

1 A1 10 A2 11 A3 12 A4 13 A5 14 A6 15 A7 16 A8 17 A9 18 A10 19 ~{HALT} 2 A11 20 VSS 21 A12 22 A13 23 A14 24 A15 25 D7 26 D6 27 D5 28 D4 29 MR 3 D3 30 D2 31 D1 32 D0 33 R/~{W}34 VCC_STANDBY 35 RE 36 E

6502: ~{VP}:Vector Pull BE: Bus Enable ~{ML}:Memory Lock

Id: 1/4 Title: Unicomp v2 - 6502 6802 Board

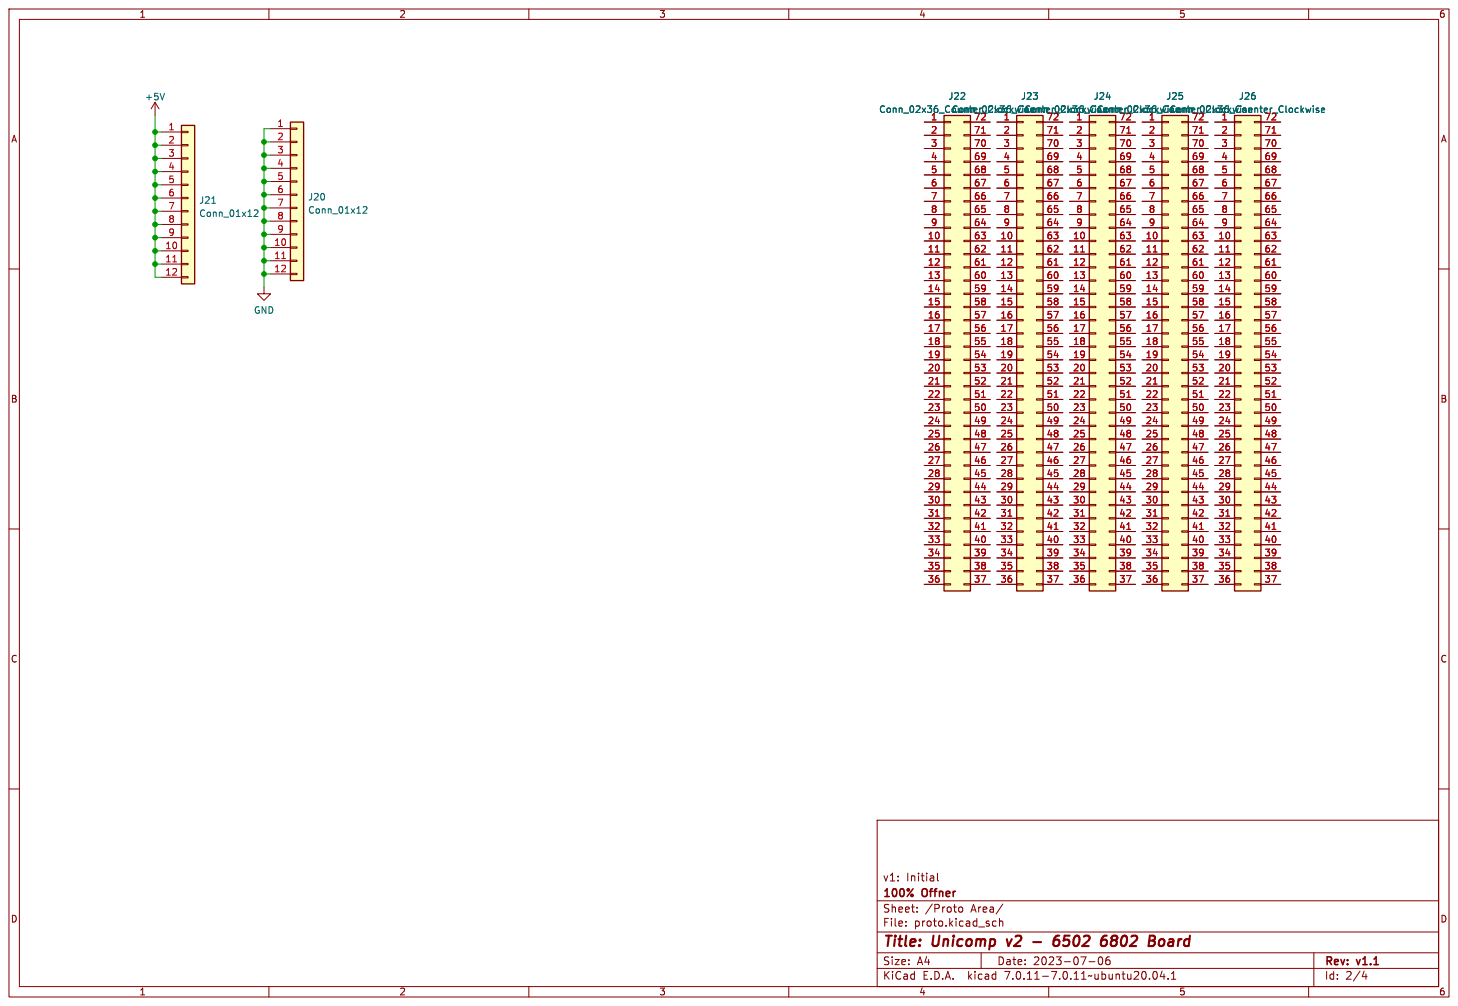
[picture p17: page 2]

Id: 2/4 Title: Unicomp v2 - 6502 6802 Board

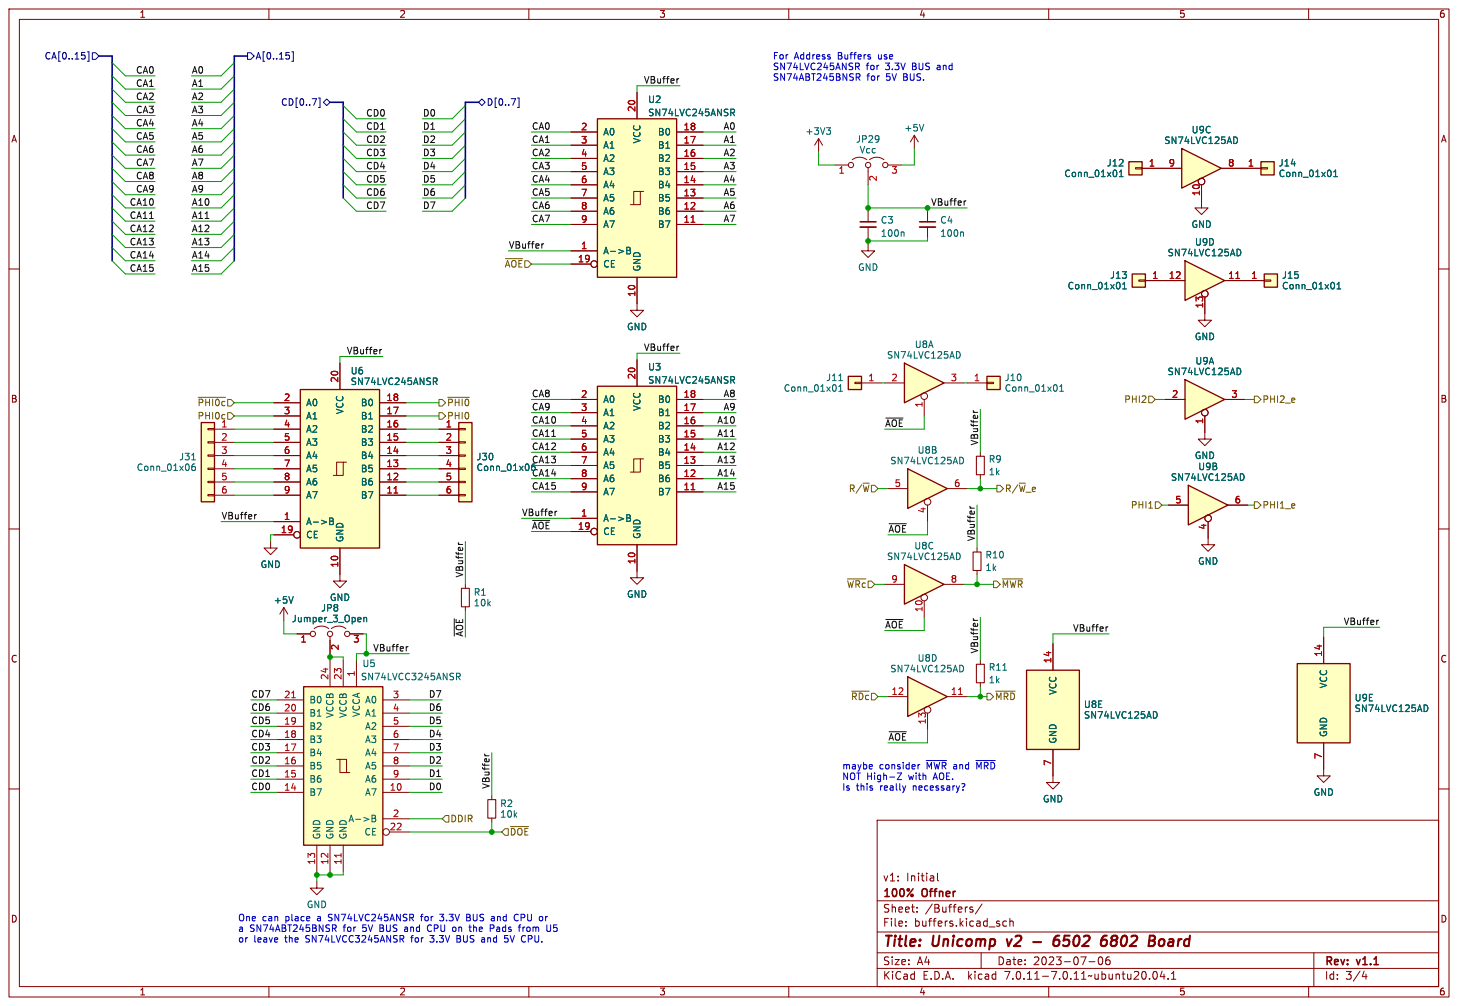
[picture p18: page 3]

1 A7 10 GND 11 GND 12 GND 13 B7 14 B6 15 B5 16 B4 17 B3 18 B2 19 A->B 2 B1 20 B0 21 CE 22 VCCB 23 VCCB 24 A0 3 A1 4 A2 5 A3 6 A4 7 A5 8 A6 9 U5 SN74LVCC3245ANSR GND

Is this really necessary?

One can place a SN74LVC245ANSR for 3.3V BUS and CPU or a SN74ABT245BNSR for 5V BUS and CPU on the Pads from U5

Id: 3/4 Title: Unicomp v2 - 6502 6802 Board

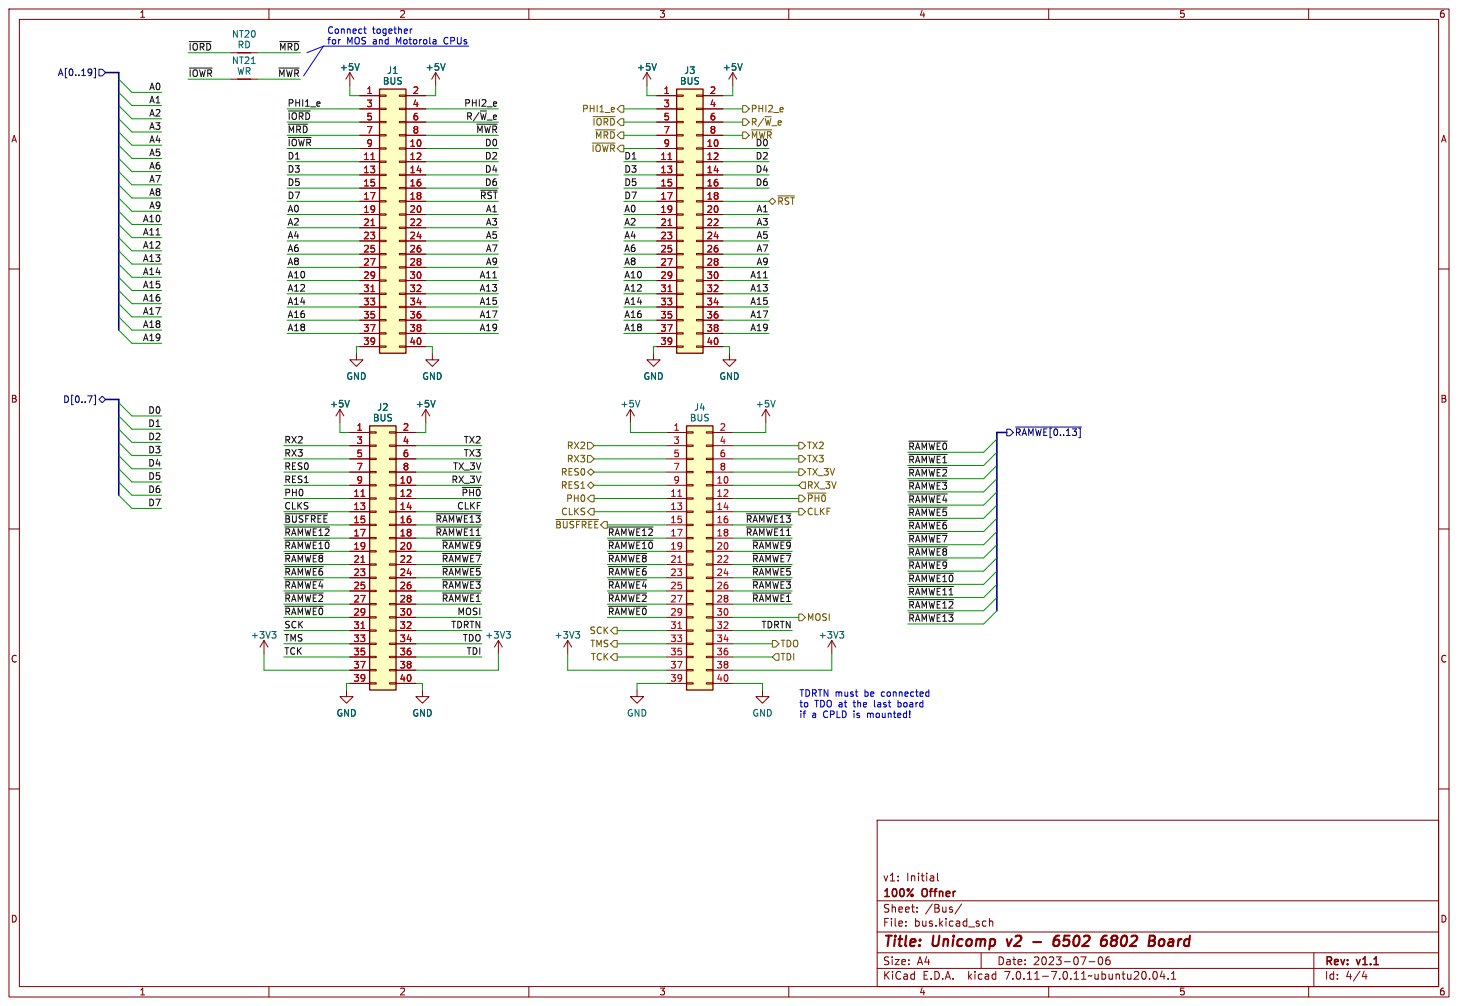
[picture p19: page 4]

to TDO at the last board
if a CPLD is mounted!

Id: 4/4 Title: Unicomp v2 - 6502 6802 Board

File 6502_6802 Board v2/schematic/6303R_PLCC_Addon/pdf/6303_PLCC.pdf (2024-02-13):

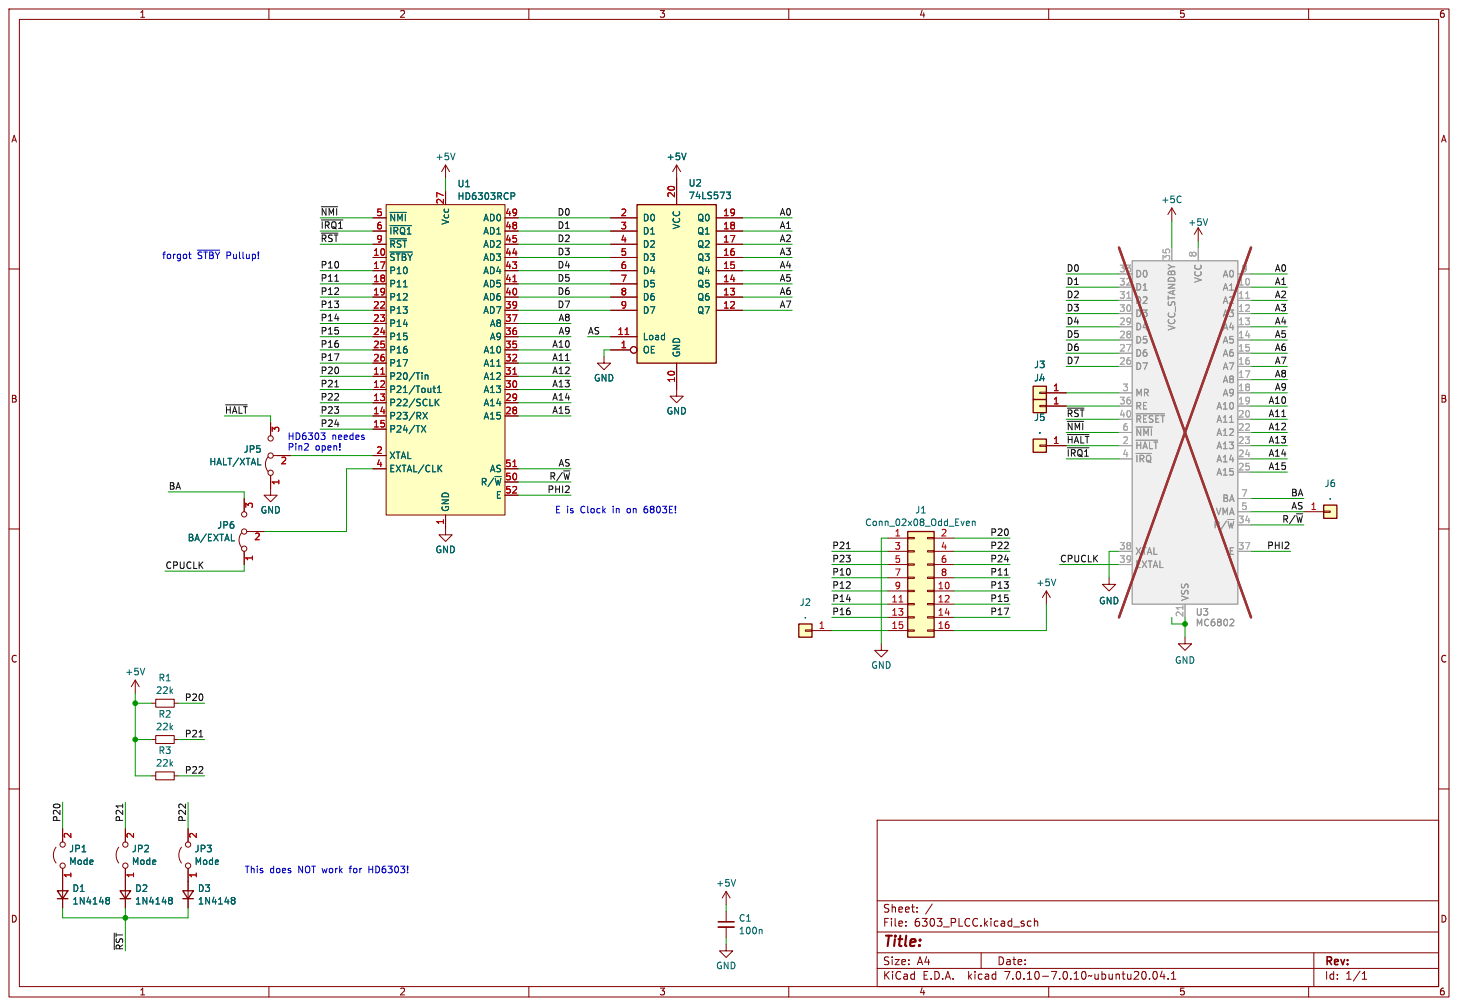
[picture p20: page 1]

1 ~{STBY} 10 P20/Tin 11 P21/Tout1 12 P22/SCLK 13 P23/RX 14 P24/TX 15 P10 17 P11 18 P12 19 XTAL 2 P13 22 P14 23 P15 24 P16 25 P17 26 Vcc 27 A15 28 A14 29 A13 30 A12 31 A11 32 A10 35 A9 36 A8 37 AD7 39 EXTAL/CLK 4 AD6 40 AD5 41 AD4 43 AD3 44 AD2 45 AD1 48 AD0 49 ~{NMI} 5 R/~{W}50 AS 51 E

8 A0 9 U3 MC6802 GND GND OE 1 GND 10

Id: 1/1 Title: File: 6303_PLCC.kicad_sch Sheet: /

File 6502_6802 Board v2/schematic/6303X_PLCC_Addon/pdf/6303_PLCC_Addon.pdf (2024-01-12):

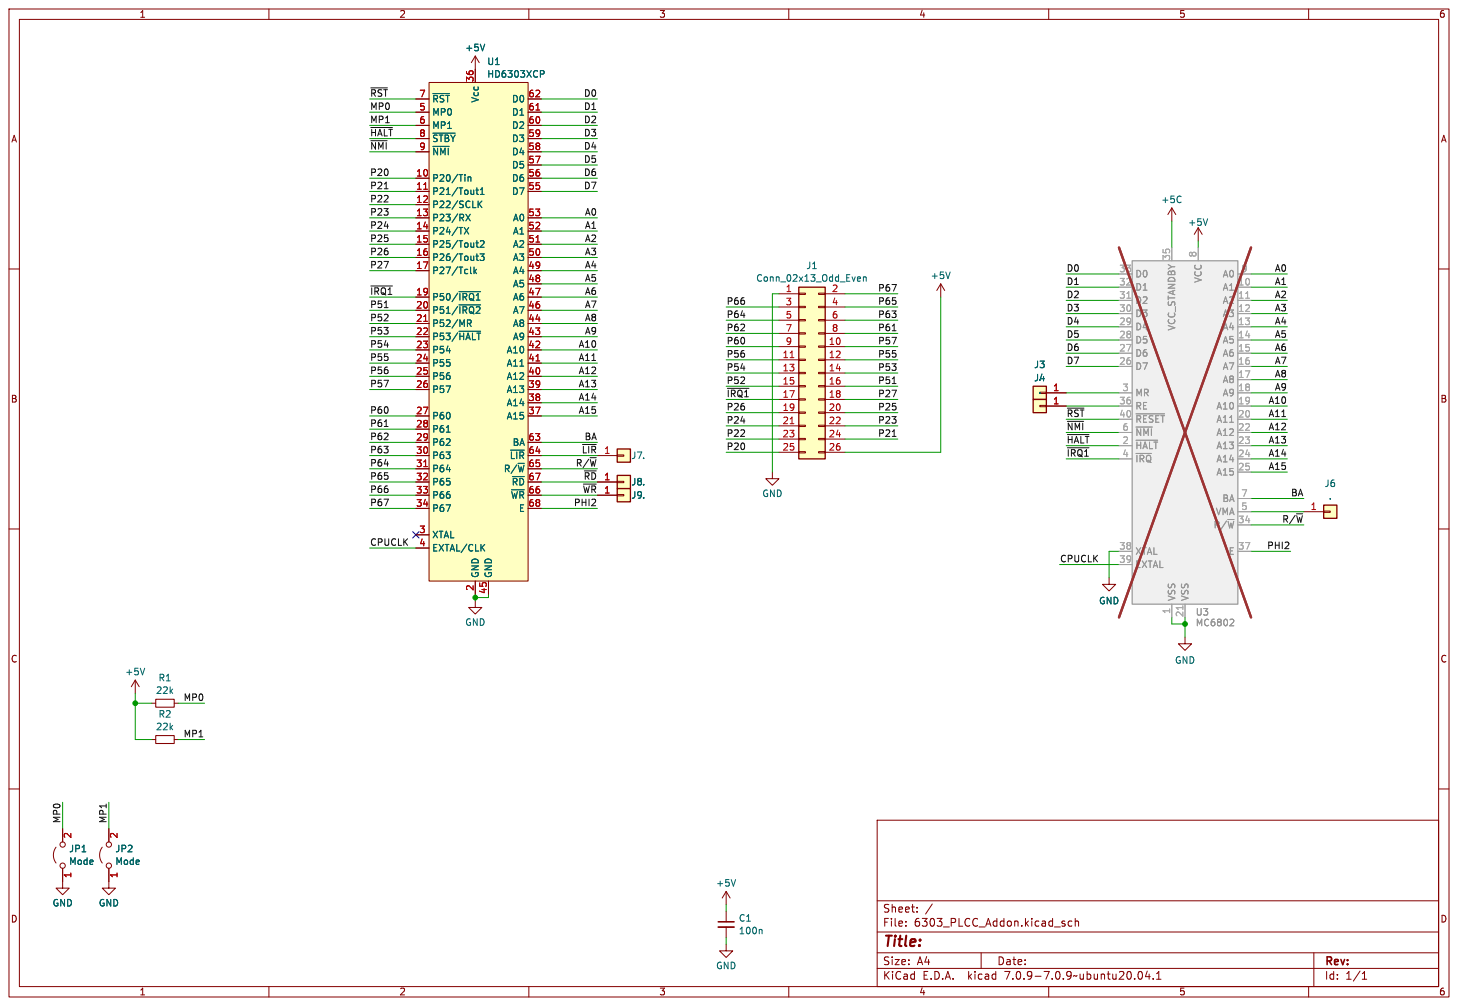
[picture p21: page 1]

Id: 1/1 Title: File: 6303_PLCC_Addon.kicad_sch Sheet: /

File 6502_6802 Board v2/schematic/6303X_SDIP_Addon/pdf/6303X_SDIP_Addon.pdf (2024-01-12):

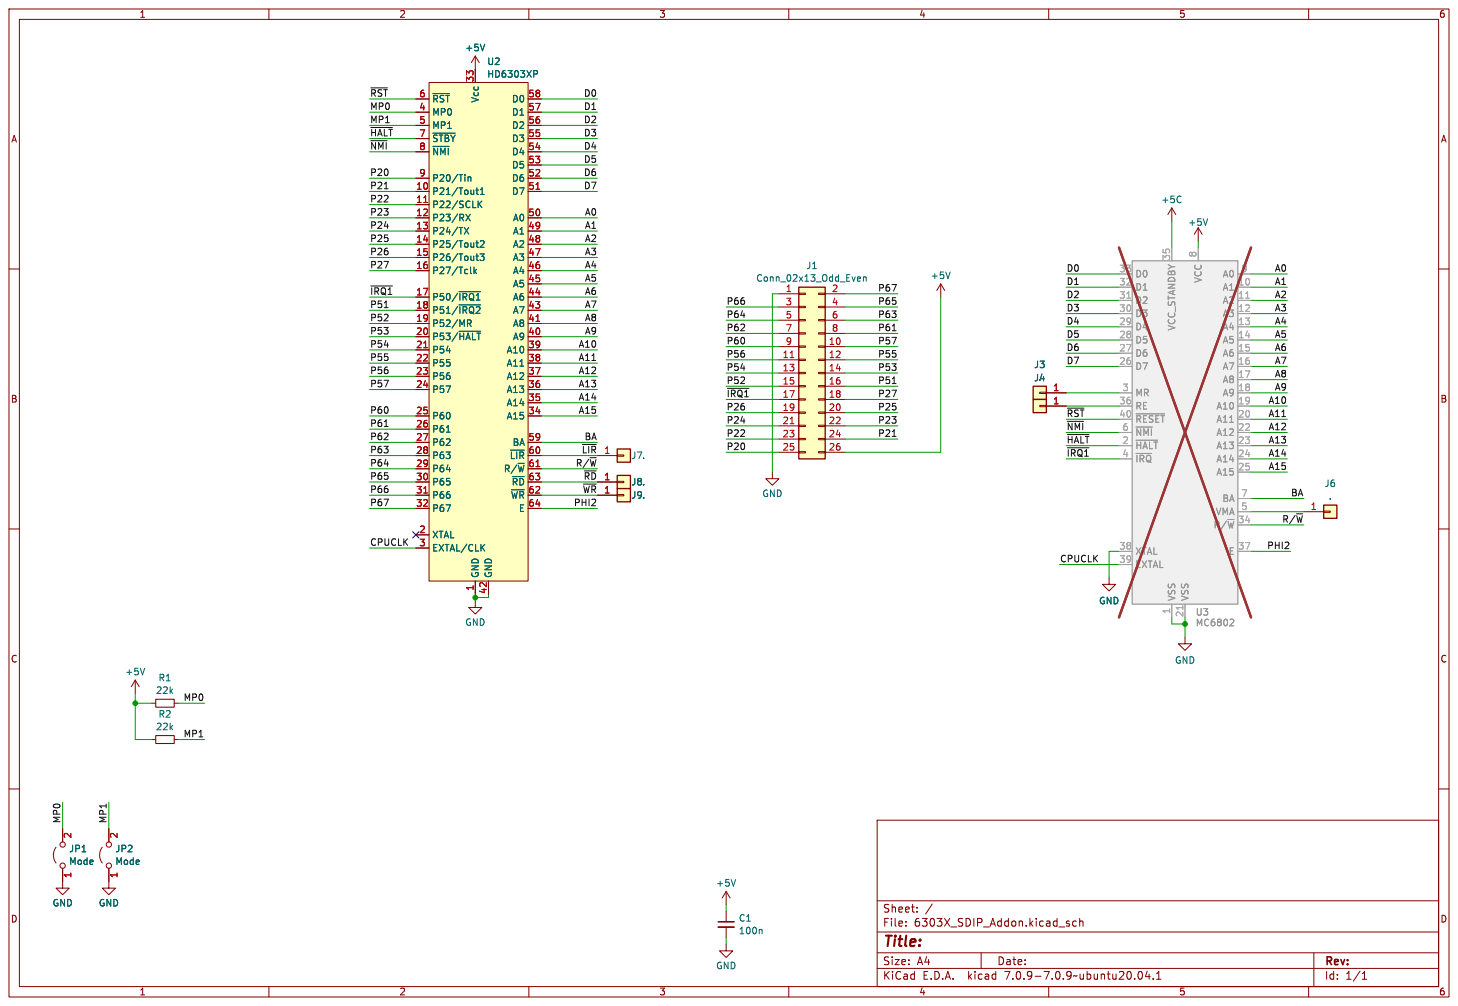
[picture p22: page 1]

Id: 1/1 Title: File: 6303X_SDIP_Addon.kicad_sch Sheet: /

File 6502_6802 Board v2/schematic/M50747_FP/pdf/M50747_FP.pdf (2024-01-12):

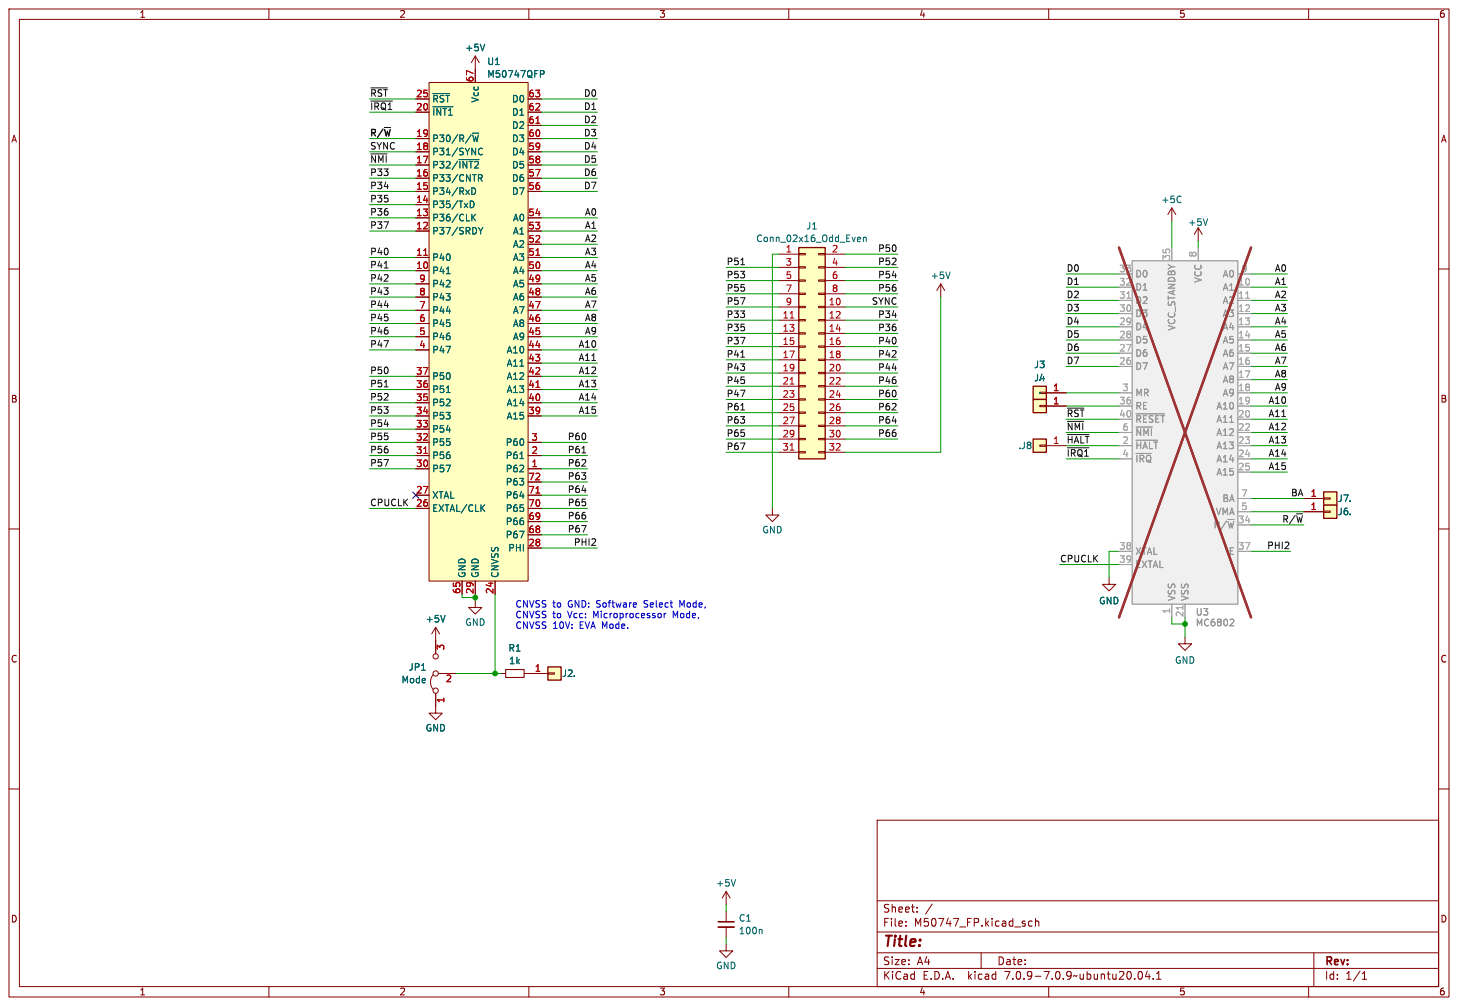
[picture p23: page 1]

Id: 1/1 Title: File: M50747_FP.kicad_sch Sheet: / C1

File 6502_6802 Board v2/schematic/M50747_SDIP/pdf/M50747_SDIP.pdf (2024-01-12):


Id: 1/1 Title: File: M50747_SDIP.kicad_sch Sheet: / C1

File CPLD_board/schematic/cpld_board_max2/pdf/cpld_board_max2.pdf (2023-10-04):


ebay MAX II board

. J23 H7 MountinSREDole H8 MountinSREDole H5 MountinSREDole H6 MountinSREDole H4 MountinSREDole H3 MountinSREDole

Id: 1/1 Title: Unicomp v2 - CPLD Board

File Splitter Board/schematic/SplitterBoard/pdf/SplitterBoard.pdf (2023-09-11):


Id: 1/1 Title: Unicomp v2 - Splitter Board


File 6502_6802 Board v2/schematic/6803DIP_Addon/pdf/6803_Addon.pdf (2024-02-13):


1 P22/SCLK 10 P23/RX 11 P24/TX 12 P10/TIN2 13 P11/TOUT2 14 P12/TOUT3 15 P13 16 P14 17 P15 18 P16 19 XTAL 2 P17 20 VCC_STBY 21 P47/A15 22 P46/A14 23 P45/A13 24 P44/A12 25 P43/A11 26 P42/A10 27 P41/A9 28 P40/A8 29 EXTAL 3 P37/AD7 30 P36/AD6 31 P35/AD5 32 P34/AD4 33 P33/AD3 34 P32/AD2 35 P31/AD1 36 P30/AD0 37 SC2/R/~{W}38 SC1/AS 39 ~{NMI} 4 E

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

Id: 1/1 Title: File: 6803_Addon.kicad_sch Sheet: /


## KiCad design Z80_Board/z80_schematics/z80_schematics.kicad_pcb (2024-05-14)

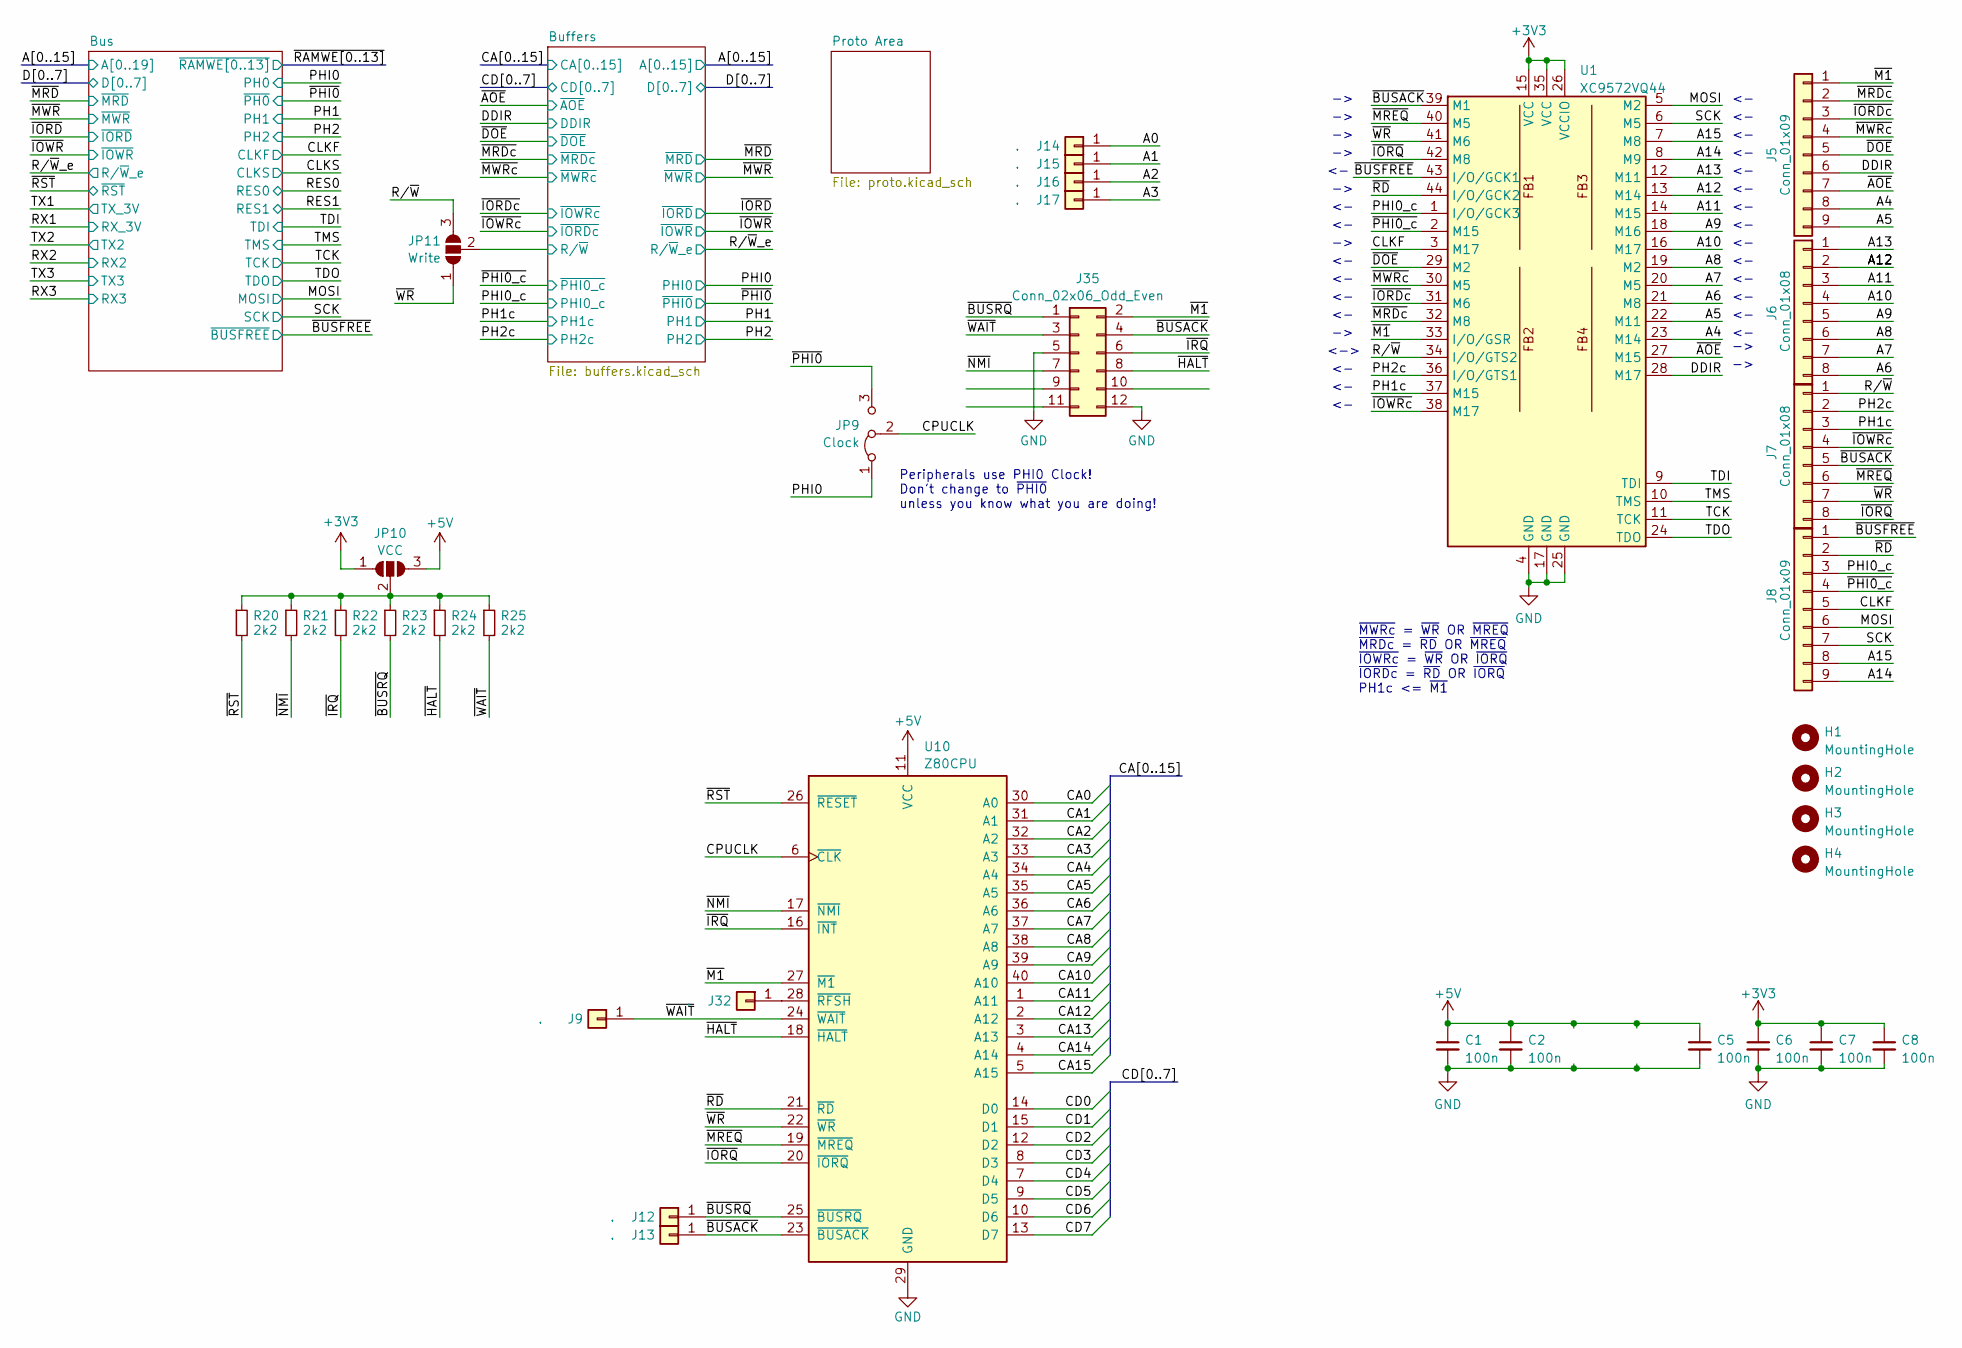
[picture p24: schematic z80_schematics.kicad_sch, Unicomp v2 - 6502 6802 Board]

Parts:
C1, C2, C5, C6, C7, C8: 100n; C_1206_3216Metric
H1, H2, H3, H4: MountingHole; MountingHole_3.2mm_M3
J5, J8: Conn_01x09; PinHeader_1x09_P2.54mm_Vertical
J6, J7: Conn_01x08; PinHeader_1x08_P2.54mm_Vertical
J9, J12, J13, J14, J15, J16, J17, J32: .; PinHeader_1x01_P2.00mm_Vertical
J35: Conn_02x06_Odd_Even; PinHeader_2x06_P2.54mm_Horizontal
JP9: Clock; SolderJumper-3_P1.3mm_Bridged12_RoundedPad1.0x1.5mm
JP10: VCC; SolderJumper-3_P1.3mm_Open_RoundedPad1.0x1.5mm_NumberLabels
JP11: Write; SolderJumper-3_P1.3mm_Open_RoundedPad1.0x1.5mm_NumberLabels
R20, R21, R22, R23, R24, R25: 2k2; R_1206_3216Metric_Pad1.30x1.75mm_HandSolder
U1: XC9572VQ44; TQFP-44_10x10mm_P0.8mm
U10: Z80CPU; DIP-40_W15.24mm_Socket_LongPads

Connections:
+3V3: C6.1, C7.1, C8.1, JP10.1 (A), U1.15 (VCC), U1.26 (VCCIO), U1.35 (VCC); also elsewhere on the board
+5V: C1.1, C2.1, C5.1, JP10.3 (B), U10.11 (VCC); also elsewhere on the board
/A0: J14.1; also elsewhere on the board
/A1: J15.1; also elsewhere on the board
/A2: J16.1; also elsewhere on the board
/A3: J17.1; also elsewhere on the board
/A4: J5.8, U1.23 (M14); also elsewhere on the board
/A5: J5.9, U1.22 (M11); also elsewhere on the board
/A6: J6.8, U1.21 (M8); also elsewhere on the board
/A7: J6.7, U1.20 (M5); also elsewhere on the board
/A8: J6.6, U1.19 (M2); also elsewhere on the board
/A9: J6.5, U1.18 (M16); also elsewhere on the board
/A10: J6.4, U1.16 (M17); also elsewhere on the board
/A11: J6.3, U1.14 (M15); also elsewhere on the board
/A12: J6.2, U1.13 (M14); also elsewhere on the board
/A13: J6.1, U1.12 (M11); also elsewhere on the board
/A14: J8.9, U1.8 (M9); also elsewhere on the board
/A15: J8.8, U1.7 (M8); also elsewhere on the board
/Buffers/R/~W: JP11.2 (C); also elsewhere on the board
/CA0: U10.30 (A0); also elsewhere on the board
/CA1: U10.31 (A1); also elsewhere on the board
/CA2: U10.32 (A2); also elsewhere on the board
/CA3: U10.33 (A3); also elsewhere on the board
/CA4: U10.34 (A4); also elsewhere on the board
/CA5: U10.35 (A5); also elsewhere on the board
/CA6: U10.36 (A6); also elsewhere on the board
/CA7: U10.37 (A7); also elsewhere on the board
/CA8: U10.38 (A8); also elsewhere on the board
/CA9: U10.39 (A9); also elsewhere on the board
/CA10: U10.40 (A10); also elsewhere on the board
/CA11: U10.1 (A11); also elsewhere on the board
/CA12: U10.2 (A12); also elsewhere on the board
/CA13: U10.3 (A13); also elsewhere on the board
/CA14: U10.4 (A14); also elsewhere on the board
/CA15: U10.5 (A15); also elsewhere on the board
/CD0: U10.14 (D0); also elsewhere on the board
/CD1: U10.15 (D1); also elsewhere on the board
/CD2: U10.12 (D2); also elsewhere on the board
/CD3: U10.8 (D3); also elsewhere on the board
/CD4: U10.7 (D4); also elsewhere on the board
/CD5: U10.9 (D5); also elsewhere on the board
/CD6: U10.10 (D6); also elsewhere on the board
/CD7: U10.13 (D7); also elsewhere on the board
/CLKF: J8.5, U1.3 (M17); also elsewhere on the board
/CPUCLK: JP9.2 (C), U10.6 (~CLK)
/DDIR: J5.6, U1.28 (M17); also elsewhere on the board
/MOSI: J8.6, U1.5 (M2); also elsewhere on the board
/PH1c: J7.3, U1.37 (M15); also elsewhere on the board
/PH2c: J7.2, U1.36 (I/O/GTS1); also elsewhere on the board
/PHI0: JP9.1 (A); also elsewhere on the board
/PHI0_c: J8.3, U1.1 (I/O/GCK3); also elsewhere on the board
/R/~W: J7.1, JP11.3 (B), U1.34 (I/O/GTS2)
/SCK: J8.7, U1.6 (M5); also elsewhere on the board
/TCK: U1.11 (TCK); also elsewhere on the board
/TDI: U1.9 (TDI); also elsewhere on the board
/TDO: U1.24 (TDO); also elsewhere on the board
/TMS: U1.10 (TMS); also elsewhere on the board
/~AOE: J5.7, U1.27 (M15); also elsewhere on the board
/~BUSACK: J7.5, J13.1, J35.4, U1.39 (M1), U10.23 (~BUSACK)
/~BUSFREE: J8.1, U1.43 (I/O/GCK1); also elsewhere on the board
/~BUSRQ: J12.1, J35.1, R23.2, U10.25 (~BUSRQ)
/~DOE: J5.5, U1.29 (M2); also elsewhere on the board
/~HALT: J35.8, R24.2, U10.18 (~HALT)
/~IORDc: J5.3, U1.31 (M6); also elsewhere on the board
/~IORQ: J7.8, U1.42 (M8), U10.20 (~IORQ)
/~IOWRc: J7.4, U1.38 (M17); also elsewhere on the board
/~IRQ: J35.6, R22.2, U10.16 (~INT)
/~M1: J5.1, J35.2, U1.33 (I/O/GSR), U10.27 (~M1)
/~MRDc: J5.2, U1.32 (M8); also elsewhere on the board
/~MREQ: J7.6, U1.40 (M5), U10.19 (~MREQ)
/~MWRc: J5.4, U1.30 (M5); also elsewhere on the board
/~NMI: J35.7, R21.2, U10.17 (~NMI)
/~PHI0_c: J8.4, U1.2 (M15); also elsewhere on the board
/~PHI0: JP9.3 (B); also elsewhere on the board
/~RD: J8.2, U1.44 (I/O/GCK2), U10.21 (~RD)
/~RST: R20.2, U10.26 (~RESET); also elsewhere on the board
/~WAIT: J9.1, J35.3, R25.2, U10.24 (~WAIT)
/~WR: J7.7, JP11.1 (A), U1.41 (M6), U10.22 (~WR)
GND: C1.2, C2.2, C5.2, C6.2, C7.2, C8.2, J35.5, J35.12, U1.4 (GND), U1.17 (GND), U1.25 (GND), U10.29 (GND); also elsewhere on the board
unnamed: J32.1, U10.28 (~RFSH)
unnamed: JP10.2 (C), R20.1, R21.1, R22.1, R23.1, R24.1, R25.1

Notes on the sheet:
<->
~{MWRc} = ~{WR} OR ~{MREQ} ~{MRDc} = ~{RD} OR ~{MREQ} ~{IOWRc} = ~{WR} OR ~{IORQ} ~{IORDc} = ~{RD} OR ~{IORQ} PH1c <= ~{M1}
Peripherals use PHI0 Clock! Don't change to ~{PHI0} unless you know what you are doing!

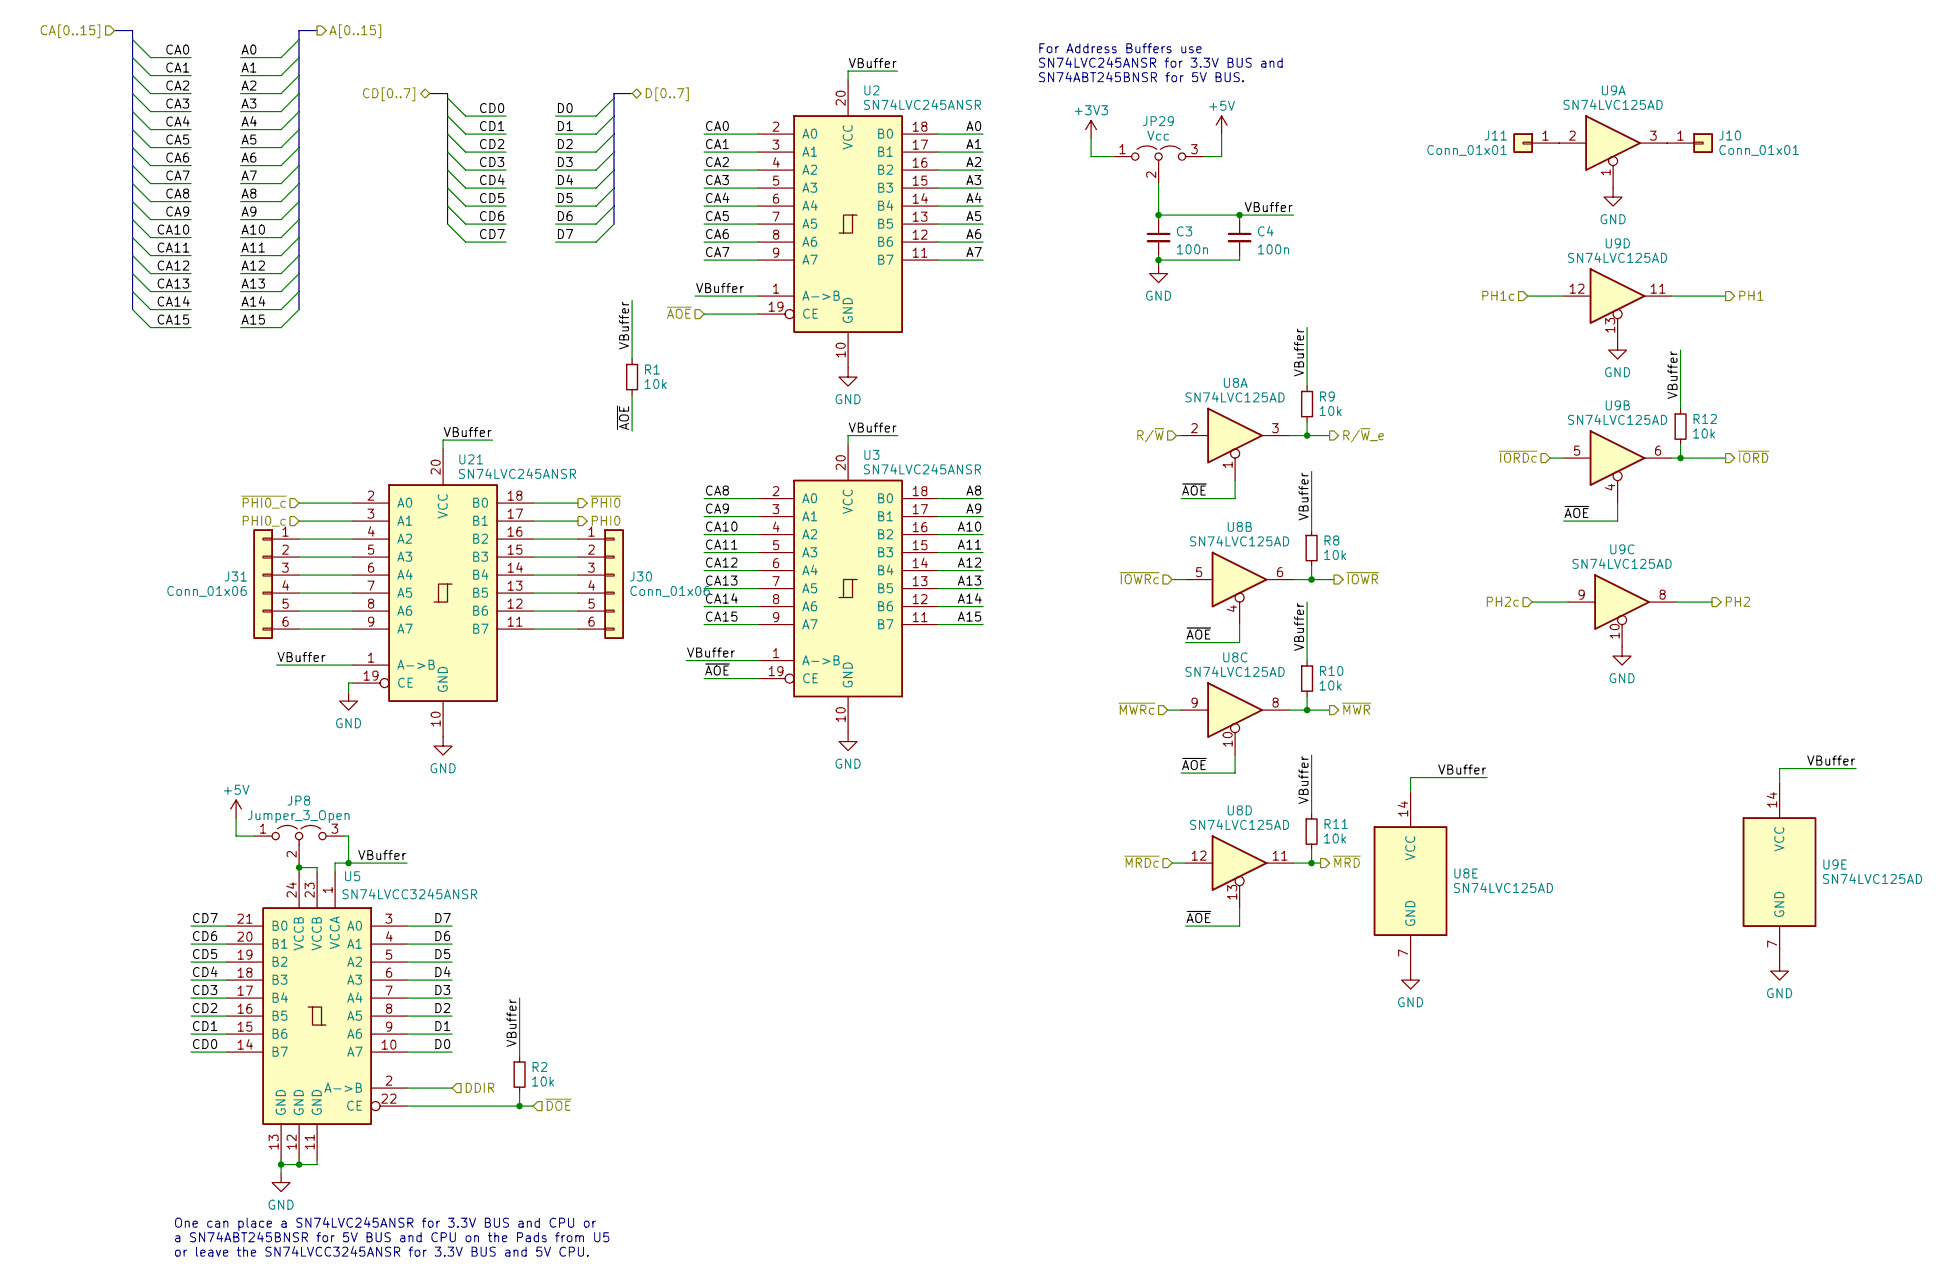
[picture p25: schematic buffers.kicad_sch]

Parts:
C3, C4: 100n; C_1206_3216Metric
J10, J11: Conn_01x01; PinHeader_1x01_P1.27mm_Vertical
J30, J31: Conn_01x06; PinHeader_1x06_P1.27mm_Vertical
JP8: Jumper_3_Open; SolderJumper-3_P1.3mm_Open_Pad1.0x1.5mm_NumberLabels
JP29: Vcc; SolderJumper-3_P1.3mm_Open_RoundedPad1.0x1.5mm_NumberLabels
R1, R2, R8, R9, R10, R11, R12: 10k; R_1206_3216Metric_Pad1.30x1.75mm_HandSolder
U2, U3, U21: SN74LVC245ANSR; SO-20_5.3x12.6mm_P1.27mm
U5: SN74LVCC3245ANSR; SO-24_5.3x15mm_P1.27mm
U8, U9: SN74LVC125AD; SOIC-14_3.9x8.7mm_P1.27mm

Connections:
+3V3: JP29.1 (A); also elsewhere on the board
+5V: JP8.1 (A), JP29.3 (B); also elsewhere on the board
/A0: U2.18 (B0); also elsewhere on the board
/A1: U2.17 (B1); also elsewhere on the board
/A2: U2.16 (B2); also elsewhere on the board
/A3: U2.15 (B3); also elsewhere on the board
/A4: U2.14 (B4); also elsewhere on the board
/A5: U2.13 (B5); also elsewhere on the board
/A6: U2.12 (B6); also elsewhere on the board
/A7: U2.11 (B7); also elsewhere on the board
/A8: U3.18 (B0); also elsewhere on the board
/A9: U3.17 (B1); also elsewhere on the board
/A10: U3.16 (B2); also elsewhere on the board
/A11: U3.15 (B3); also elsewhere on the board
/A12: U3.14 (B4); also elsewhere on the board
/A13: U3.13 (B5); also elsewhere on the board
/A14: U3.12 (B6); also elsewhere on the board
/A15: U3.11 (B7); also elsewhere on the board
/Buffers/R/~W: U8.2; also elsewhere on the board
/Buffers/VBuffer: C3.1, C4.1, JP8.3 (B), JP29.2 (C), R1.1, R2.1, R8.1, R9.1, R10.1, R11.1, R12.1, U2.1 (A->B), U2.20 (VCC), U3.1 (A->B), U3.20 (VCC), U5.1 (VCCA), U8.14 (VCC), U9.14 (VCC), U21.1 (A->B), U21.20 (VCC)
/CA0: U2.2 (A0); also elsewhere on the board
/CA1: U2.3 (A1); also elsewhere on the board
/CA2: U2.4 (A2); also elsewhere on the board
/CA3: U2.5 (A3); also elsewhere on the board
/CA4: U2.6 (A4); also elsewhere on the board
/CA5: U2.7 (A5); also elsewhere on the board
/CA6: U2.8 (A6); also elsewhere on the board
/CA7: U2.9 (A7); also elsewhere on the board
/CA8: U3.2 (A0); also elsewhere on the board
/CA9: U3.3 (A1); also elsewhere on the board
/CA10: U3.4 (A2); also elsewhere on the board
/CA11: U3.5 (A3); also elsewhere on the board
/CA12: U3.6 (A4); also elsewhere on the board
/CA13: U3.7 (A5); also elsewhere on the board
/CA14: U3.8 (A6); also elsewhere on the board
/CA15: U3.9 (A7); also elsewhere on the board
/CD0: U5.14 (B7); also elsewhere on the board
/CD1: U5.15 (B6); also elsewhere on the board
/CD2: U5.16 (B5); also elsewhere on the board
/CD3: U5.17 (B4); also elsewhere on the board
/CD4: U5.18 (B3); also elsewhere on the board
/CD5: U5.19 (B2); also elsewhere on the board
/CD6: U5.20 (B1); also elsewhere on the board
/CD7: U5.21 (B0); also elsewhere on the board
/D0: U5.10 (A7); also elsewhere on the board
/D1: U5.9 (A6); also elsewhere on the board
/D2: U5.8 (A5); also elsewhere on the board
/D3: U5.7 (A4); also elsewhere on the board
/D4: U5.6 (A3); also elsewhere on the board
/D5: U5.5 (A2); also elsewhere on the board
/D6: U5.4 (A1); also elsewhere on the board
/D7: U5.3 (A0); also elsewhere on the board
/DDIR: U5.2 (A->B); also elsewhere on the board
/PH1: U9.11; also elsewhere on the board
/PH1c: U9.12; also elsewhere on the board
/PH2: U9.8; also elsewhere on the board
/PH2c: U9.9; also elsewhere on the board
/PHI0: U21.17 (B1); also elsewhere on the board
/PHI0_c: U21.3 (A1); also elsewhere on the board
/R/~W_e: R9.2, U8.3; also elsewhere on the board
/~AOE: R1.2, U2.19 (CE), U3.19 (CE), U8.1, U8.4, U8.10, U8.13, U9.4; also elsewhere on the board
/~DOE: R2.2, U5.22 (CE); also elsewhere on the board
/~IORDc: U8.5; also elsewhere on the board
/~IORD: R12.2, U9.6; also elsewhere on the board
/~IOWRc: U9.5; also elsewhere on the board
/~IOWR: R8.2, U8.6; also elsewhere on the board
/~MRDc: U8.12; also elsewhere on the board
/~MRD: R11.2, U8.11; also elsewhere on the board
/~MWRc: U8.9; also elsewhere on the board
/~MWR: R10.2, U8.8; also elsewhere on the board
/~PHI0_c: U21.2 (A0); also elsewhere on the board
/~PHI0: U21.18 (B0); also elsewhere on the board
GND: C3.2, C4.2, U2.10 (GND), U3.10 (GND), U5.11 (GND), U5.12 (GND), U5.13 (GND), U8.7 (GND), U9.1, U9.7 (GND), U9.10, U9.13, U21.10 (GND), U21.19 (CE); also elsewhere on the board
unnamed: J10.1, U9.3
unnamed: J11.1, U9.2
unnamed: J30.1, U21.16 (B2)
unnamed: J30.2, U21.15 (B3)
unnamed: J30.3, U21.14 (B4)
unnamed: J30.4, U21.13 (B5)
unnamed: J30.5, U21.12 (B6)
unnamed: J30.6, U21.11 (B7)
unnamed: J31.1, U21.4 (A2)
unnamed: J31.2, U21.5 (A3)
unnamed: J31.3, U21.6 (A4)
unnamed: J31.4, U21.7 (A5)
unnamed: J31.5, U21.8 (A6)
unnamed: J31.6, U21.9 (A7)
unnamed: JP8.2 (C), U5.23 (VCCB), U5.24 (VCCB)

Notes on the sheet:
One can place a SN74LVC245ANSR for 3.3V BUS and CPU or a SN74ABT245BNSR for 5V BUS and CPU on the Pads from U5 or leave the SN74LVCC3245ANSR for 3.3V BUS and 5V CPU.
For Address Buffers use SN74LVC245ANSR for 3.3V BUS and SN74ABT245BNSR for 5V BUS.

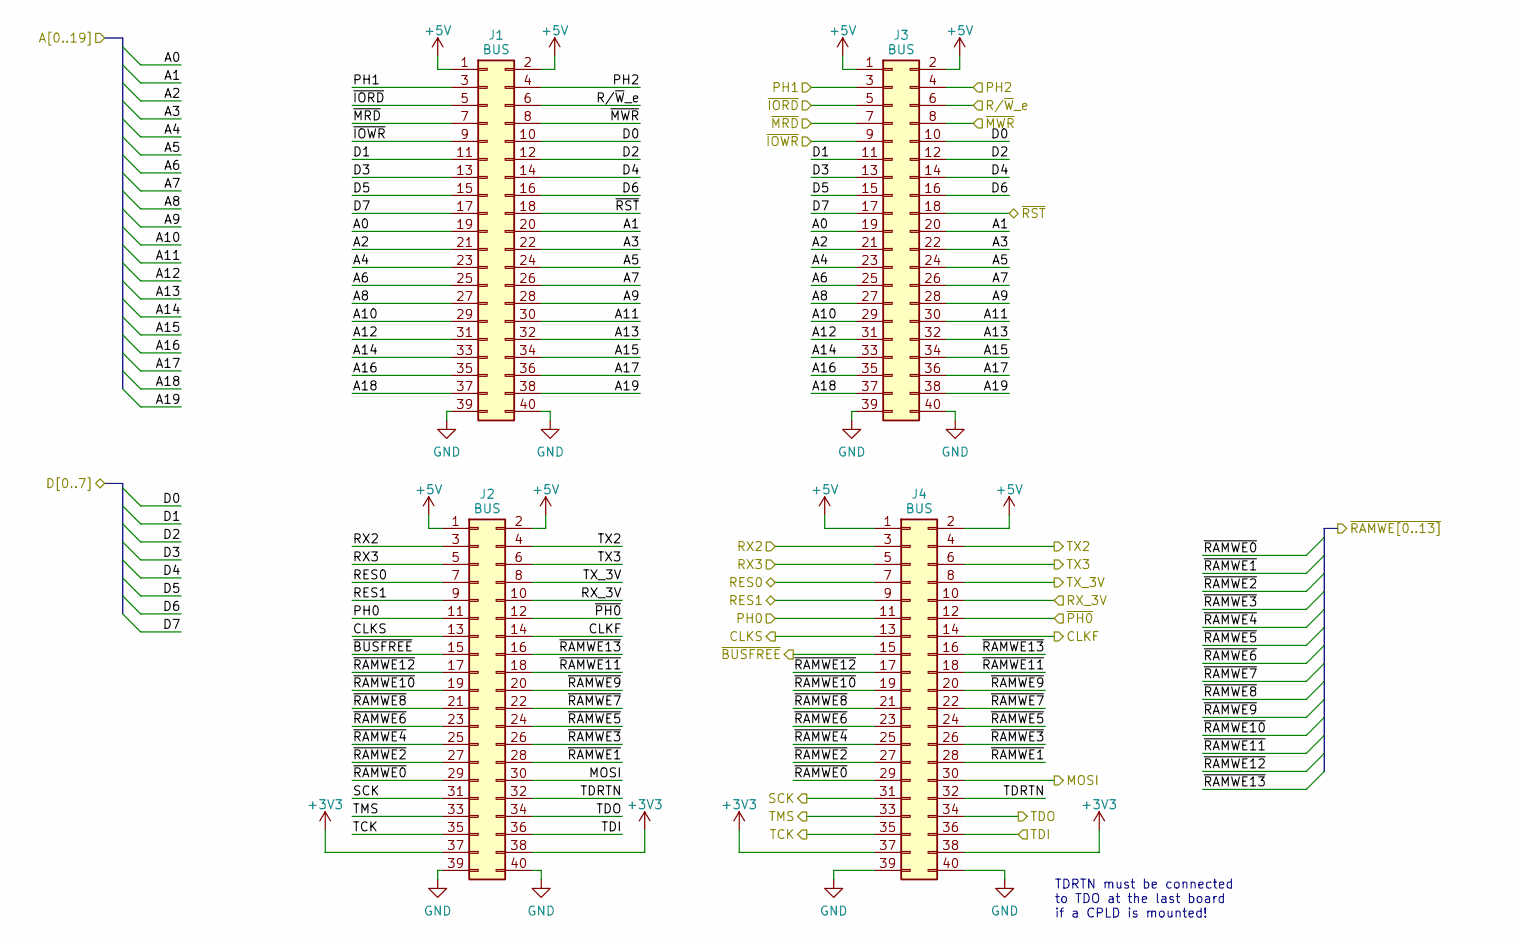
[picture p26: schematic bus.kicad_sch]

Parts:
J1, J2, J3, J4: BUS; PinSocket_2x20_P2.54mm_Vertical

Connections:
+3V3: J2.37, J2.38, J4.37, J4.38; also elsewhere on the board
+5V: J1.1, J1.2, J2.1, J2.2, J3.1, J3.2, J4.1, J4.2; also elsewhere on the board
/A0: J1.19, J3.19; also elsewhere on the board
/A1: J1.20, J3.20; also elsewhere on the board
/A2: J1.21, J3.21; also elsewhere on the board
/A3: J1.22, J3.22; also elsewhere on the board
/A4: J1.23, J3.23; also elsewhere on the board
/A5: J1.24, J3.24; also elsewhere on the board
/A6: J1.25, J3.25; also elsewhere on the board
/A7: J1.26, J3.26; also elsewhere on the board
/A8: J1.27, J3.27; also elsewhere on the board
/A9: J1.28, J3.28; also elsewhere on the board
/A10: J1.29, J3.29; also elsewhere on the board
/A11: J1.30, J3.30; also elsewhere on the board
/A12: J1.31, J3.31; also elsewhere on the board
/A13: J1.32, J3.32; also elsewhere on the board
/A14: J1.33, J3.33; also elsewhere on the board
/A15: J1.34, J3.34; also elsewhere on the board
/Bus/A16: J1.35, J3.35
/Bus/A17: J1.36, J3.36
/Bus/A18: J1.37, J3.37
/Bus/A19: J1.38, J3.38
/Bus/TDRTN: J2.32, J4.32
/CLKF: J2.14, J4.14; also elsewhere on the board
/CLKS: J2.13, J4.13
/D0: J1.10, J3.10; also elsewhere on the board
/D1: J1.11, J3.11; also elsewhere on the board
/D2: J1.12, J3.12; also elsewhere on the board
/D3: J1.13, J3.13; also elsewhere on the board
/D4: J1.14, J3.14; also elsewhere on the board
/D5: J1.15, J3.15; also elsewhere on the board
/D6: J1.16, J3.16; also elsewhere on the board
/D7: J1.17, J3.17; also elsewhere on the board
/MOSI: J2.30, J4.30; also elsewhere on the board
/PH1: J1.3, J3.3; also elsewhere on the board
/PH2: J1.4, J3.4; also elsewhere on the board
/PHI0: J2.11, J4.11; also elsewhere on the board
/RES0: J2.7, J4.7
/RES1: J2.9, J4.9
/RX1: J2.10, J4.10
/RX2: J2.3, J4.3
/RX3: J2.5, J4.5
/R/~W_e: J1.6, J3.6; also elsewhere on the board
/SCK: J2.31, J4.31; also elsewhere on the board
/TCK: J2.35, J4.35; also elsewhere on the board
/TDI: J2.36, J4.36; also elsewhere on the board
/TDO: J2.34, J4.34; also elsewhere on the board
/TMS: J2.33, J4.33; also elsewhere on the board
/TX1: J2.8, J4.8
/TX2: J2.4, J4.4
/TX3: J2.6, J4.6
/~BUSFREE: J2.15, J4.15; also elsewhere on the board
/~IORD: J1.5, J3.5; also elsewhere on the board
/~IOWR: J1.9, J3.9; also elsewhere on the board
/~MRD: J1.7, J3.7; also elsewhere on the board
/~MWR: J1.8, J3.8; also elsewhere on the board
/~PHI0: J2.12, J4.12; also elsewhere on the board
/~RAMWE0: J2.29, J4.29
/~RAMWE1: J2.28, J4.28
/~RAMWE2: J2.27, J4.27
/~RAMWE3: J2.26, J4.26
/~RAMWE4: J2.25, J4.25
/~RAMWE5: J2.24, J4.24
/~RAMWE6: J2.23, J4.23
/~RAMWE7: J2.22, J4.22
/~RAMWE8: J2.21, J4.21
/~RAMWE9: J2.20, J4.20
/~RAMWE10: J2.19, J4.19
/~RAMWE11: J2.18, J4.18
/~RAMWE12: J2.17, J4.17
/~RAMWE13: J2.16, J4.16
/~RST: J1.18, J3.18; also elsewhere on the board
GND: J1.39, J1.40, J2.39, J2.40, J3.39, J3.40, J4.39, J4.40; also elsewhere on the board

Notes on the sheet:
TDRTN must be connected to TDO at the last board if a CPLD is mounted!

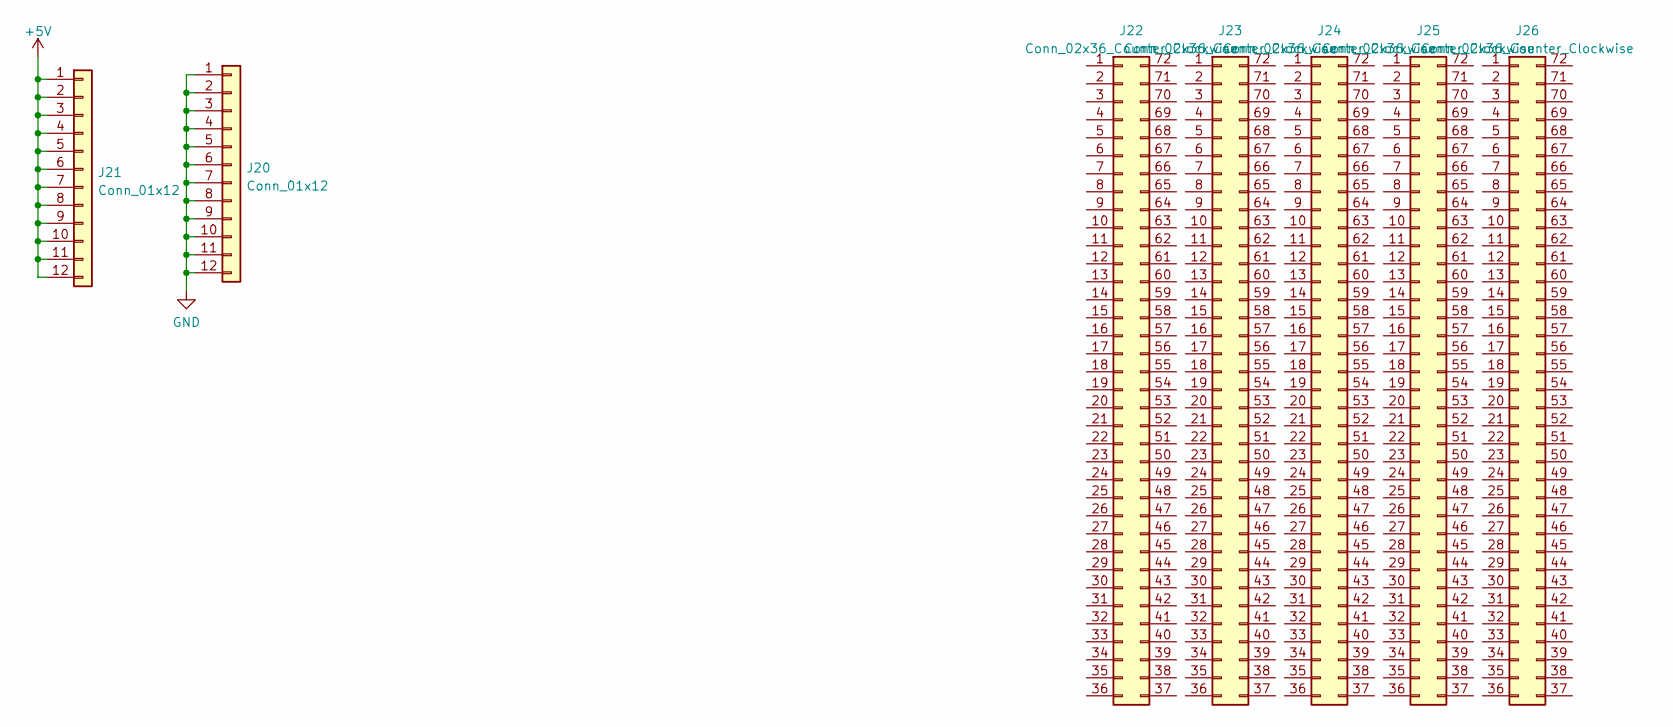
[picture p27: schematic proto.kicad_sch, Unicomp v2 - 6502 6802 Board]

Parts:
J20, J21: Conn_01x12; PinHeader_1x12_P2.54mm_Vertical
J22, J23, J24, J25, J26: Conn_02x36_Counter_Clockwise; Proto_2x36

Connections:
+5V: J21.1, J21.2, J21.3, J21.4, J21.5, J21.6, J21.7, J21.8, J21.9, J21.10, J21.11, J21.12; also elsewhere on the board
GND: J20.1, J20.2, J20.3, J20.4, J20.5, J20.6, J20.7, J20.8, J20.9, J20.10, J20.11, J20.12; also elsewhere on the board

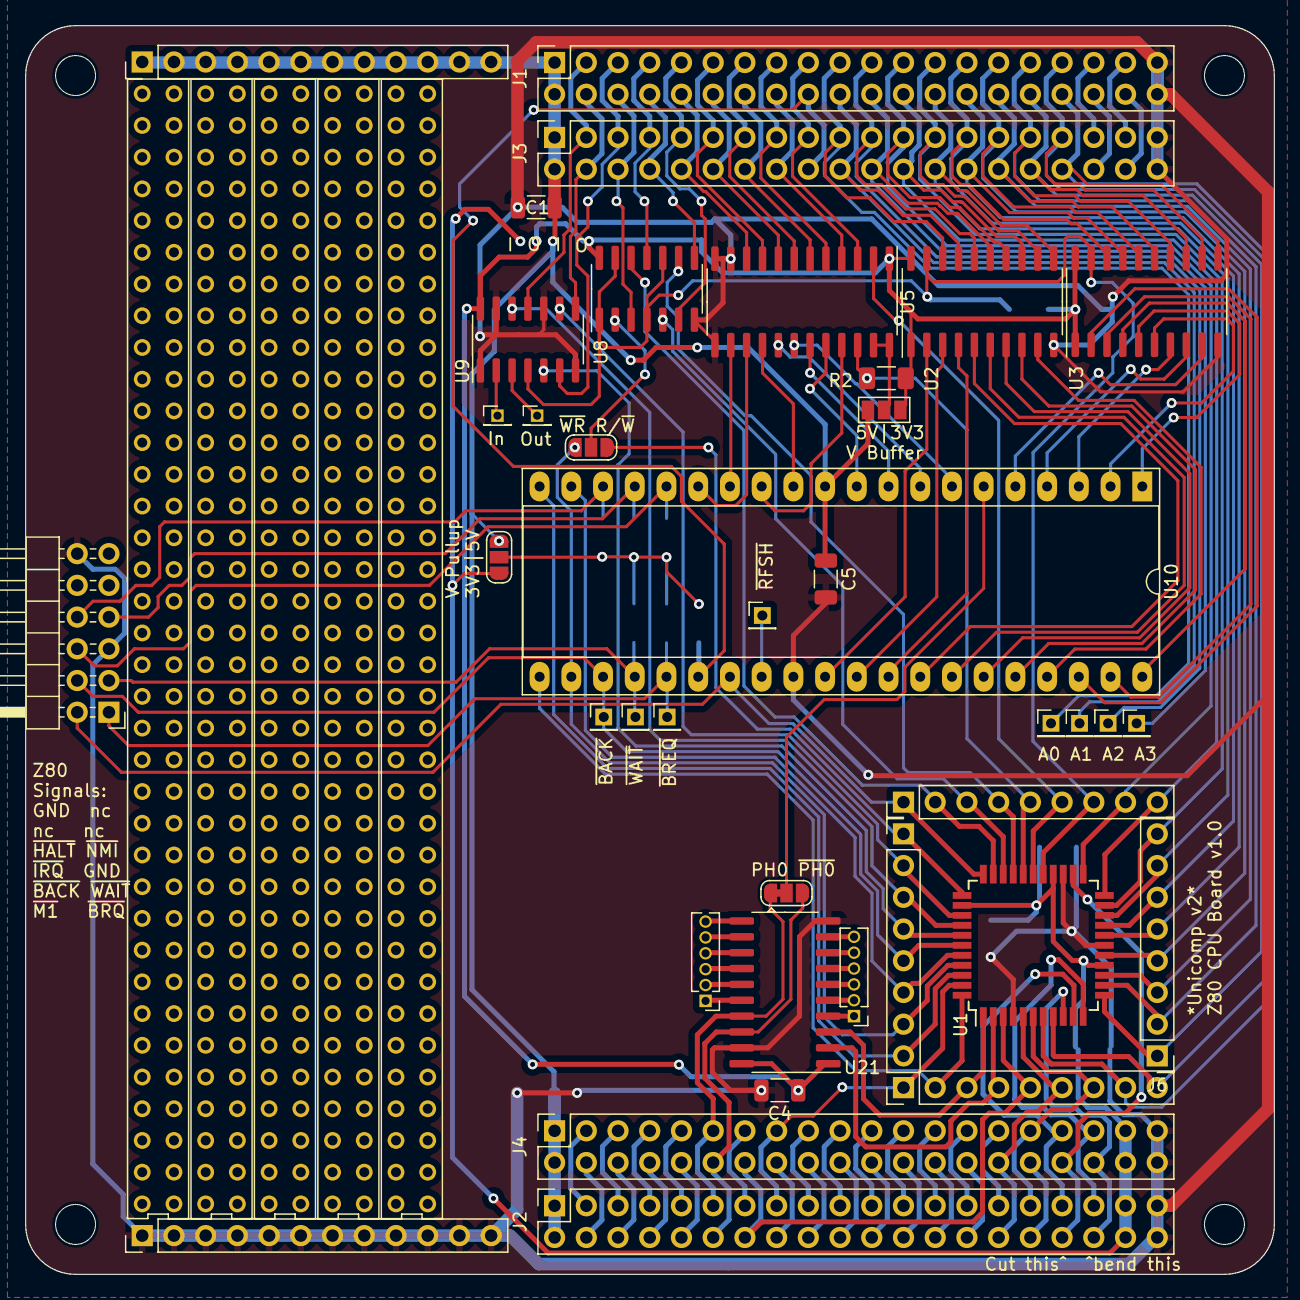
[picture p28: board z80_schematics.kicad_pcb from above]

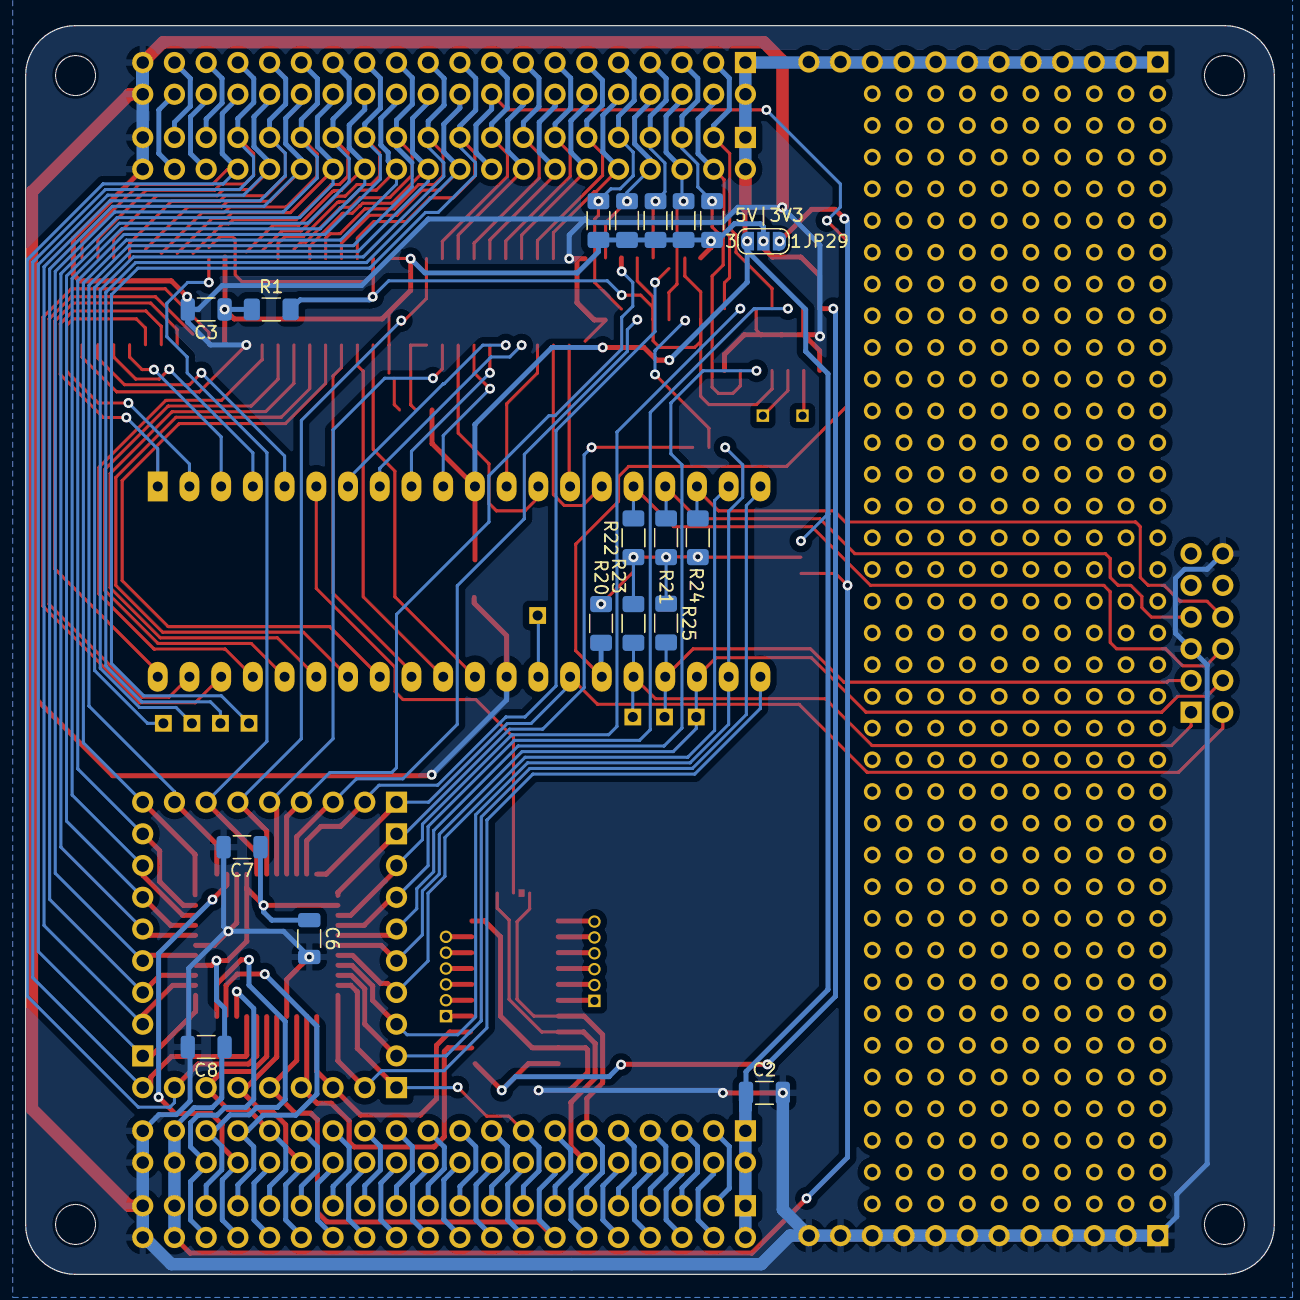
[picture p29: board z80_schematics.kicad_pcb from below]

Board: 2 copper layers, 100.0 x 100.0 mm, 66 parts (18 on the bottom side), 140 nets.

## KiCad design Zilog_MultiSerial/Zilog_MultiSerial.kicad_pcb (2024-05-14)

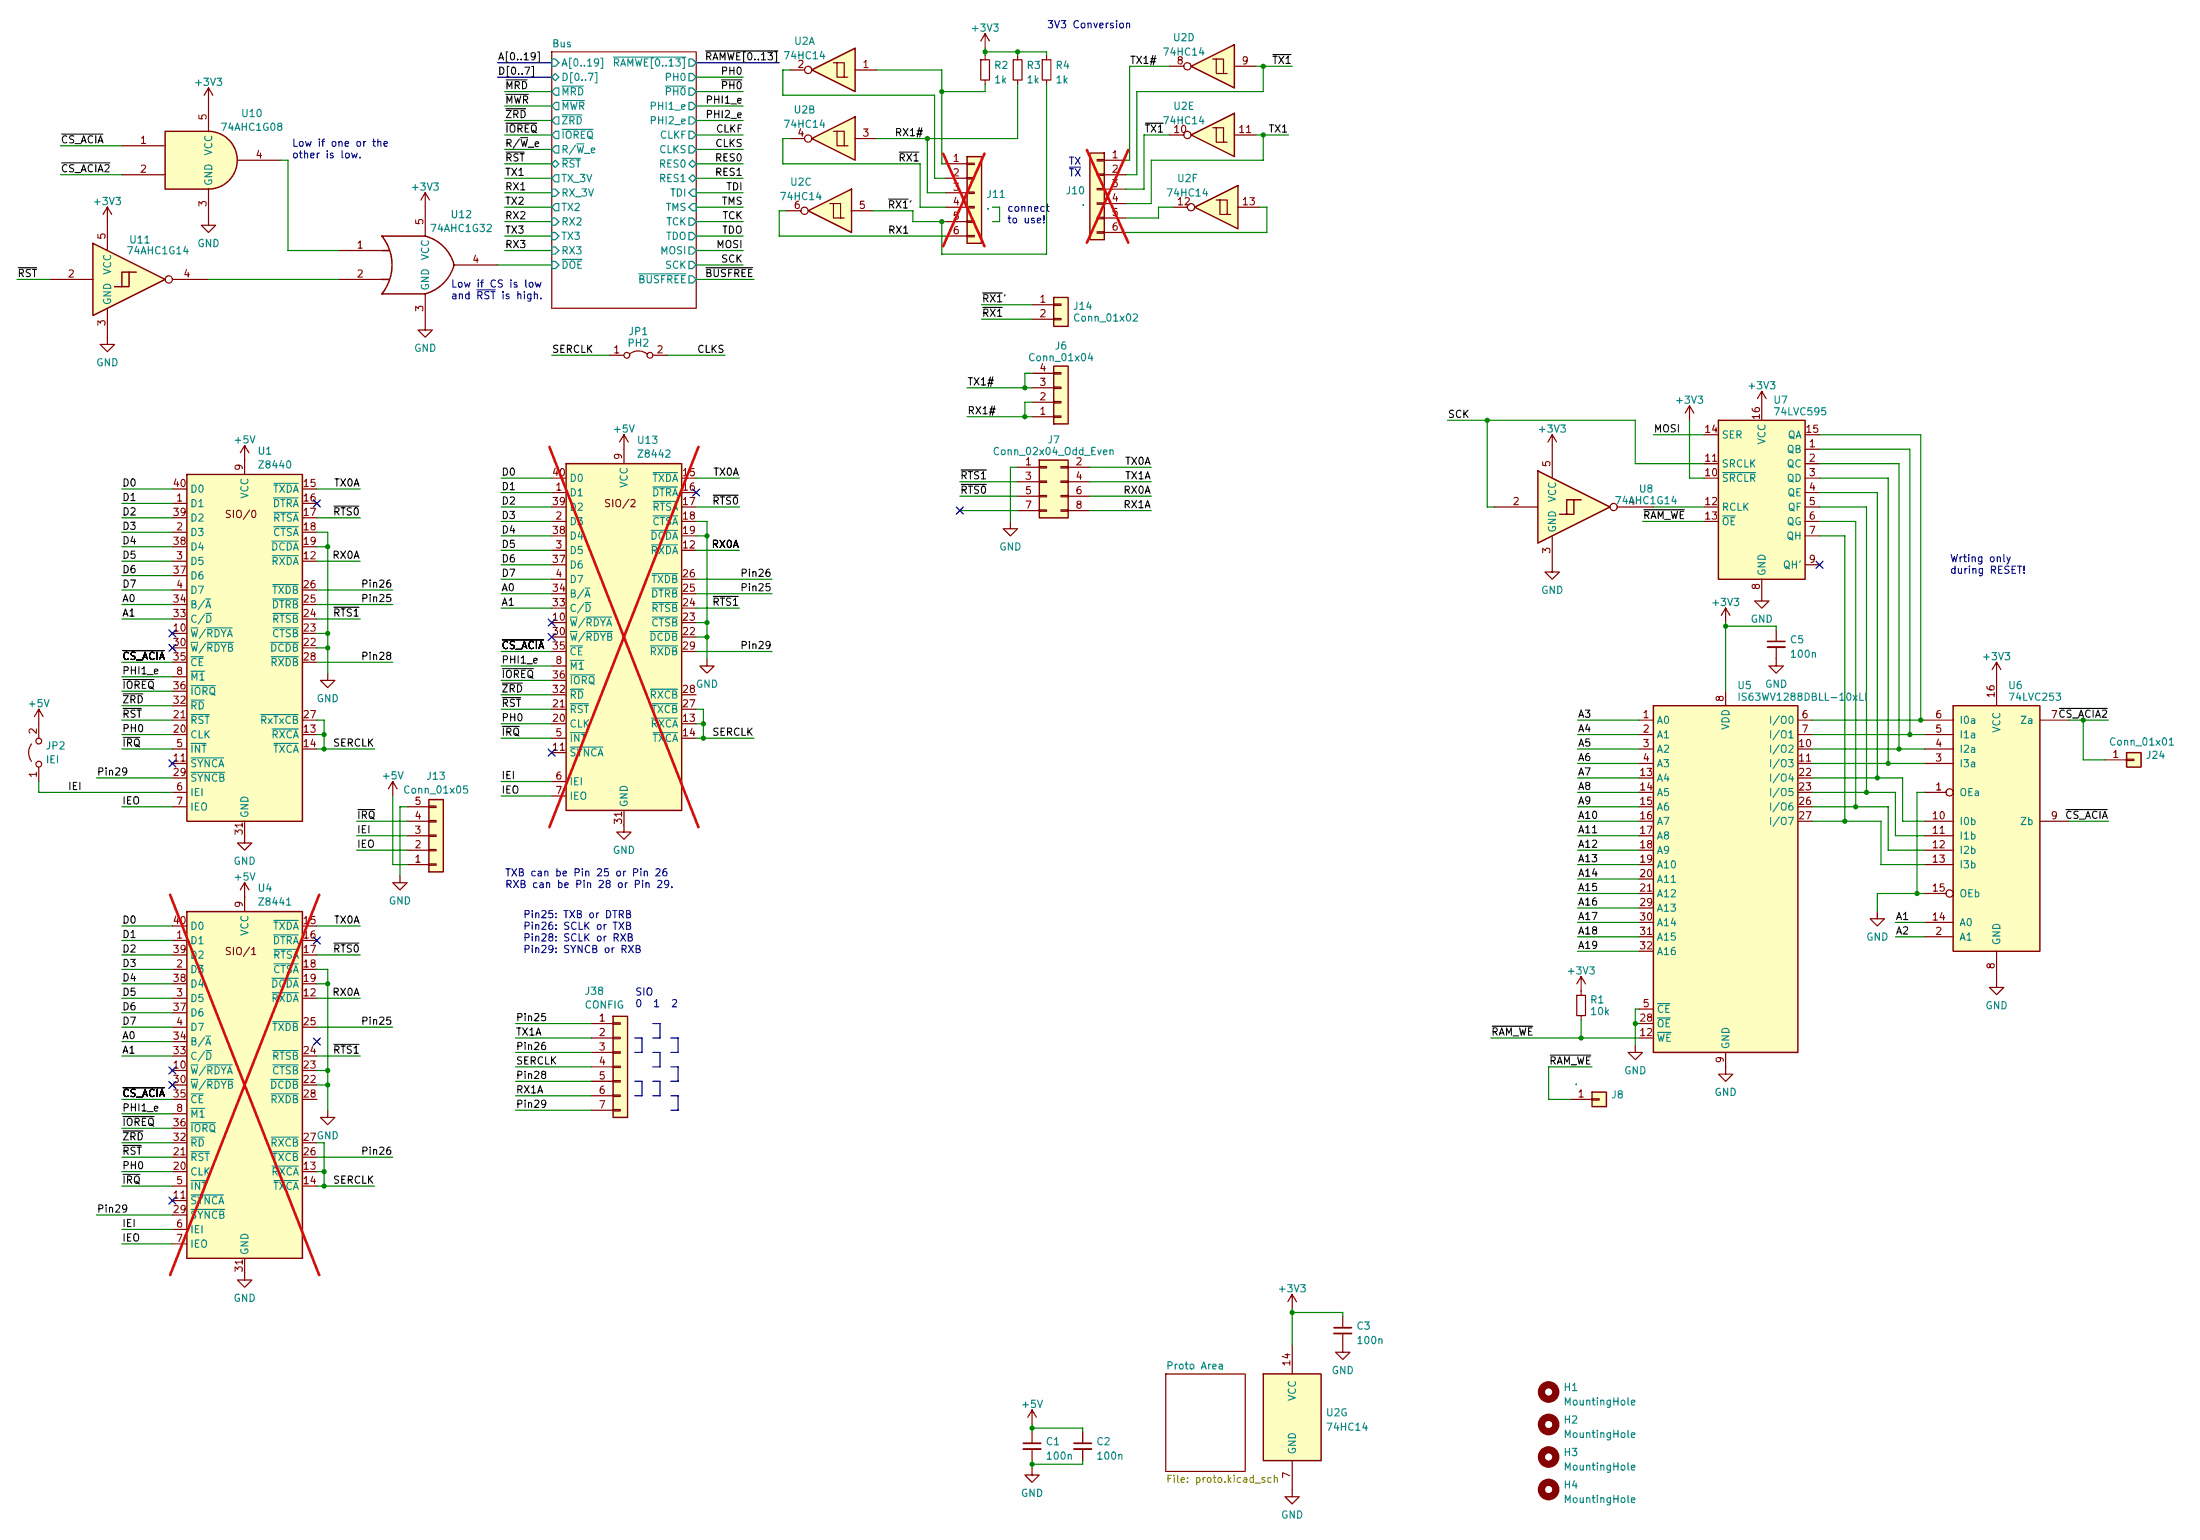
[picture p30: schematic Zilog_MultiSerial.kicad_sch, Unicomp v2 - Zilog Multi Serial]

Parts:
C1, C2, C3, C5: 100n; C_1206_3216Metric
H1, H2, H3, H4: MountingHole; MountingHole_3.2mm_M3
J6: Conn_01x04; PinHeader_1x04_P2.54mm_Vertical
J7: Conn_02x04_Odd_Even; PinHeader_2x04_P2.54mm_Vertical
J8: .; PinHeader_1x01_P2.00mm_Vertical
J10, J11: .; PinHeader_1x06_P2.54mm_Vertical; not fitted
J13: Conn_01x05; PinHeader_1x05_P2.54mm_Vertical
J14: Conn_01x02; PinHeader_1x02_P2.54mm_Vertical
J24: Conn_01x01; PinHeader_1x01_P2.00mm_Vertical
J38: CONFIG; PinHeader_1x07_P2.54mm_Vertical
JP1: PH2; SolderJumper-2_P1.3mm_Bridged_RoundedPad1.0x1.5mm
JP2: IEI; PinHeader_1x02_P2.54mm_Vertical
R1: 10k; R_1206_3216Metric_Pad1.30x1.75mm_HandSolder
R2, R3, R4: 1k; R_1206_3216Metric_Pad1.30x1.75mm_HandSolder
U1: Z8440; DIP-40_W15.24mm
U2: 74HC14; DIP-14_W7.62mm_Socket
U4: Z8441; DIP-40_W15.24mm; not fitted
U5: IS63WV1288DBLL-10xLI; TSOP-II-32_21.0x10.2mm_P1.27mm
U6: 74LVC253; SO-16_3.9x9.9mm_P1.27mm
U7: 74LVC595; SO-16_3.9x9.9mm_P1.27mm
U8: 74AHC1G14; SOT-23-5
U10: 74AHC1G08; SOT-23-5_HandSoldering
U11: 74AHC1G14; SOT-23-5_HandSoldering
U12: 74AHC1G32; SOT-23-5_HandSoldering
U13: Z8442; DIP-40_W15.24mm; not fitted

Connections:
+3V3: C3.1, C5.1, R1.1, R2.1, R3.1, R4.1, U2.14 (VCC), U5.8 (VDD), U5.24 (VDD), U6.16 (VCC), U7.10 (~SRCLR), U7.16 (VCC), U8.5 (VCC), U10.5 (VCC), U11.5 (VCC), U12.5 (VCC); also elsewhere on the board
+5V: C1.1, C2.1, J13.1, JP2.2 (B), U1.9 (VCC), U4.9 (VCC), U13.9 (VCC); also elsewhere on the board
/A0: U1.34 (B/~A), U4.34 (B/~A), U13.34 (B/~A); also elsewhere on the board
/A1: U1.33 (C/~D), U4.33 (C/~D), U6.14 (A0), U13.33 (C/~D); also elsewhere on the board
/A2: U6.2 (A1); also elsewhere on the board
/A3: U5.1 (A0); also elsewhere on the board
/A4: U5.2 (A1); also elsewhere on the board
/A5: U5.3 (A2); also elsewhere on the board
/A6: U5.4 (A3); also elsewhere on the board
/A7: U5.13 (A4); also elsewhere on the board
/A8: U5.14 (A5); also elsewhere on the board
/A9: U5.15 (A6); also elsewhere on the board
/A10: U5.16 (A7); also elsewhere on the board
/A11: U5.17 (A8); also elsewhere on the board
/A12: U5.18 (A9); also elsewhere on the board
/A13: U5.19 (A10); also elsewhere on the board
/A14: U5.20 (A11); also elsewhere on the board
/A15: U5.21 (A12); also elsewhere on the board
/A16: U5.29 (A13); also elsewhere on the board
/A17: U5.30 (A14); also elsewhere on the board
/A18: U5.31 (A15); also elsewhere on the board
/A19: U5.32 (A16); also elsewhere on the board
/Bus/~DOE: U12.4; also elsewhere on the board
/CLKS: JP1.2 (B); also elsewhere on the board
/D0: U1.40 (D0), U4.40 (D0), U13.40 (D0); also elsewhere on the board
/D1: U1.1 (D1), U4.1 (D1), U13.1 (D1); also elsewhere on the board
/D2: U1.39 (D2), U4.39 (D2), U13.39 (D2); also elsewhere on the board
/D3: U1.2 (D3), U4.2 (D3), U13.2 (D3); also elsewhere on the board
/D4: U1.38 (D4), U4.38 (D4), U13.38 (D4); also elsewhere on the board
/D5: U1.3 (D5), U4.3 (D5), U13.3 (D5); also elsewhere on the board
/D6: U1.37 (D6), U4.37 (D6), U13.37 (D6); also elsewhere on the board
/D7: U1.4 (D7), U4.4 (D7), U13.4 (D7); also elsewhere on the board
/IEI: J13.3, JP2.1 (A), U1.6 (IEI), U4.6 (IEI), U13.6 (IEI)
/IEO: J13.2, U1.7 (IEO), U4.7 (IEO), U13.7 (IEO)
/MOSI: U7.14 (SER); also elsewhere on the board
/PH0: U1.20 (CLK), U4.20 (CLK), U13.20 (CLK); also elsewhere on the board
/PHI1_e: U1.8 (~M1), U4.8 (~M1), U13.8 (~M1); also elsewhere on the board
/Pin25: J38.1, U1.25 (~DTRB), U4.25 (~TXDB), U13.25 (~DTRB)
/Pin26: J38.3, U1.26 (~TXDB), U4.26 (~TXCB), U13.26 (~TXDB)
/Pin28: J38.5, U1.28 (~RXDB)
/Pin29: J38.7, U1.29 (~SYNCB), U4.29 (~SYNCB), U13.29 (~RXDB)
/RX0A: J7.6, U1.12 (~RXDA), U4.12 (~RXDA), U13.12 (~RXDA)
/RX1: J11.6, U2.6; also elsewhere on the board
/RX1#: J6.1, J6.2, J11.3, R3.2, U2.3
/RX1A: J7.8, J38.6
/SCK: U7.11 (SRCLK), U8.2; also elsewhere on the board
/SERCLK: J38.4, JP1.1 (A), U1.13 (~RXCA), U1.14 (~TXCA), U1.27 (~RxTxCB), U4.13 (~RXCA), U4.14 (~TXCA), U4.27 (~RXCB), U13.13 (~RXCA), U13.14 (~TXCA), U13.27 (~TXCB)
/TX0A: J7.2, U1.15 (~TXDA), U4.15 (~TXDA), U13.15 (~TXDA)
/TX1: J10.4, U2.11; also elsewhere on the board
/TX1#: J6.3, J6.4, J10.1, U2.8
/TX1A: J7.4, J38.2
/~CS_ACIA2: J24.1, U6.7 (Za), U10.2
/~CS_ACIA: U1.35 (~CE), U4.35 (~CE), U6.9 (Zb), U10.1, U13.35 (~CE)
/~IOREQ: U1.36 (~IORQ), U4.36 (~IORQ), U13.36 (~IORQ); also elsewhere on the board
/~IRQ: J13.4, U1.5 (~INT), U4.5 (~INT), U13.5 (~INT)
/~RAM_WE: J8.1, R1.2, U5.12 (~WE), U7.13 (~OE)
/~RST: U1.21 (~RST), U4.21 (~RST), U11.2, U13.21 (~RST); also elsewhere on the board
/~RTS0: J7.5, U1.17 (~RTSA), U4.17 (~RTSA), U13.17 (~RTSA)
/~RTS1: J7.3, U1.24 (~RTSB), U4.24 (~RTSB), U13.24 (~RTSB)
/~RX1: J11.4, J14.2, U2.4
/~RX1': J11.5, J14.1, R4.2, U2.5
/~TX1: J10.2, J10.3, U2.9, U2.10
/~ZRD: U1.32 (~RD), U4.32 (~RD), U13.32 (~RD); also elsewhere on the board
GND: C1.2, C2.2, C3.2, C5.2, J7.1, J13.5, U1.18 (~CTSA), U1.19 (~DCDA), U1.22 (~DCDB), U1.23 (~CTSB), U1.31 (GND), U2.7 (GND), U4.18 (~CTSA), U4.19 (~DCDA), U4.22 (~DCDB), U4.23 (~CTSB), U4.31 (GND), U5.5 (~CE), U5.9 (GND), U5.25 (GND), U5.28 (~OE), U6.1 (OEa), U6.8 (GND), U6.15 (OEb), U7.8 (GND), U8.3 (GND), U10.3 (GND), U11.3 (GND), U12.3 (GND), U13.18 (~CTSA), U13.19 (~DCDA), U13.22 (~DCDB), U13.23 (~CTSB), U13.31 (GND); also elsewhere on the board
unnamed: J11.1, R2.2, U2.1
unnamed: J11.2, U2.2
unnamed: J10.5, U2.12
unnamed: J10.6, U2.13
unnamed: U5.6 (I/O0), U6.6 (I0a), U7.15 (QA)
unnamed: U5.7 (I/O1), U6.5 (I1a), U7.1 (QB)
unnamed: U5.10 (I/O2), U6.4 (I2a), U7.2 (QC)
unnamed: U5.11 (I/O3), U6.3 (I3a), U7.3 (QD)
unnamed: U5.22 (I/O4), U6.10 (I0b), U7.4 (QE)
unnamed: U5.23 (I/O5), U6.11 (I1b), U7.5 (QF)
unnamed: U5.26 (I/O6), U6.12 (I2b), U7.6 (QG)
unnamed: U5.27 (I/O7), U6.13 (I3b), U7.7 (QH)
unnamed: U7.12 (RCLK), U8.4
unnamed: U10.4, U12.1
unnamed: U11.4, U12.2

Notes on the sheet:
TXB can be Pin 25 or Pin 26 RXB can be Pin 28 or Pin 29.
SIO 0 1 2
Wrting only during RESET!
connect to use!
Pin25: TXB or DTRB Pin26: SCLK or TXB Pin28: SCLK or RXB Pin29: SYNCB or RXB
3V3 Conversion
Low if CS is low and ~{RST} is high.
Low if one or the other is low.
TX ~{TX}

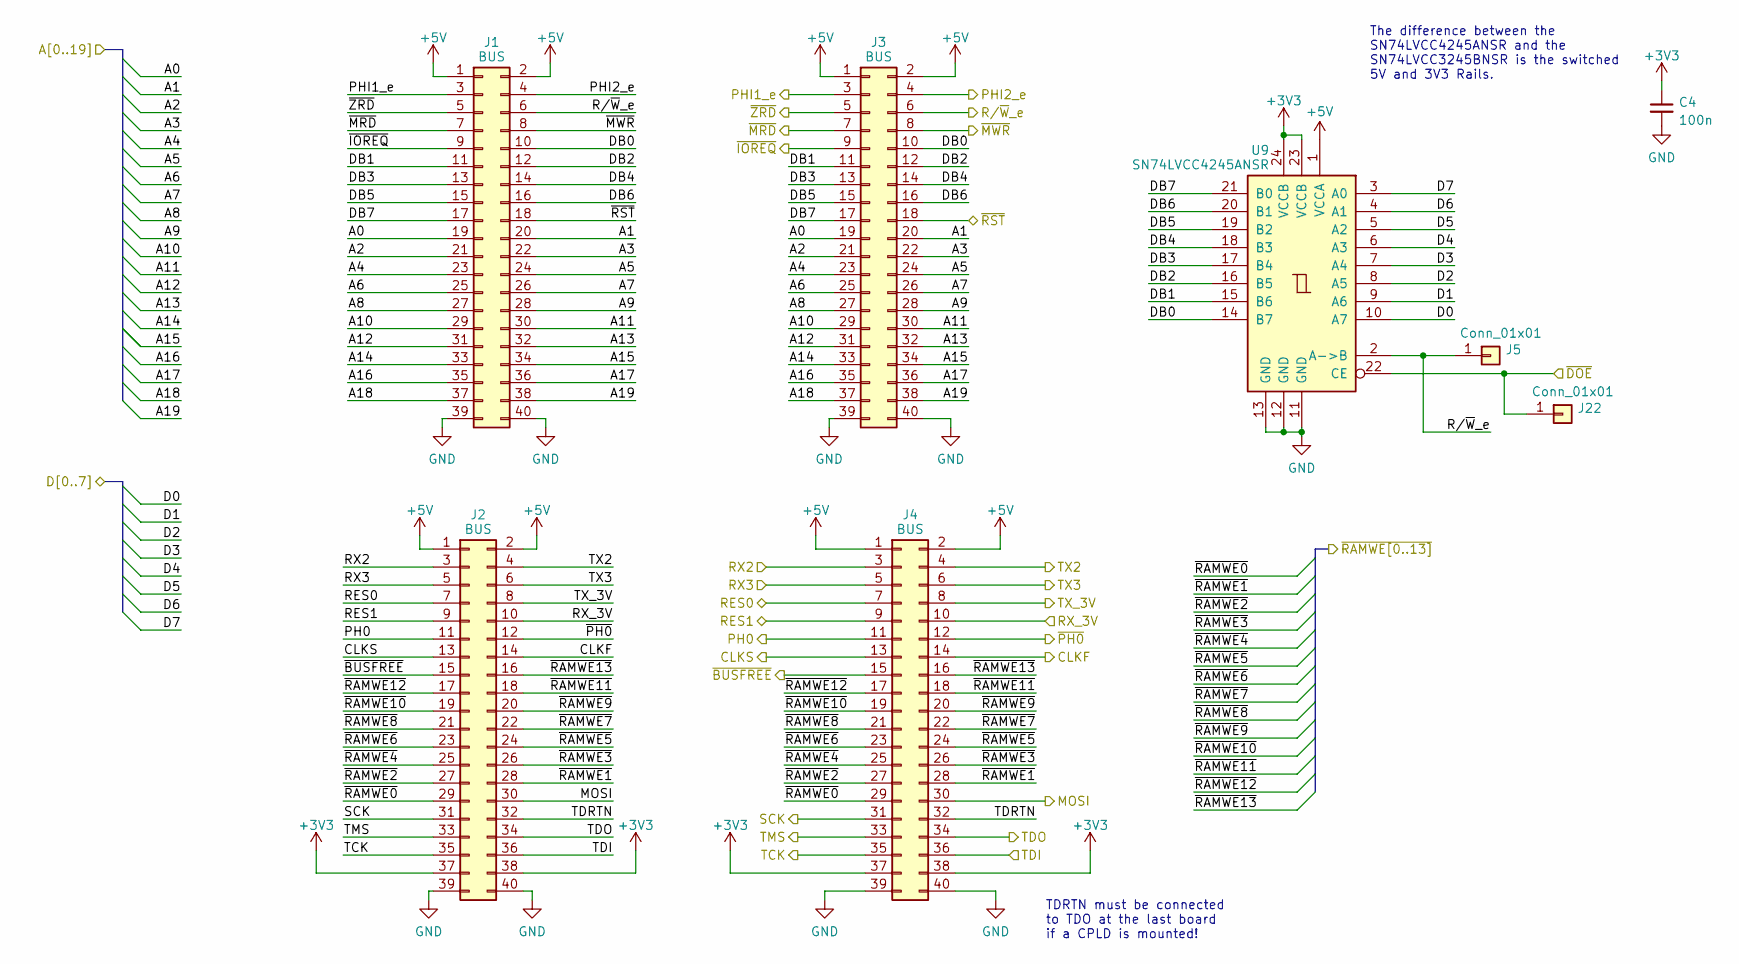
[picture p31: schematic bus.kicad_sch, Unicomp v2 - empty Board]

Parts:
C4: 100n; C_1206_3216Metric
J1, J2, J3, J4: BUS; PinSocket_2x20_P2.54mm_Vertical
J5, J22: Conn_01x01; PinHeader_1x01_P2.00mm_Vertical
U9: SN74LVCC4245ANSR; SO-24_5.3x15mm_P1.27mm

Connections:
+3V3: C4.1, J2.37, J2.38, J4.37, J4.38, U9.23 (VCCB), U9.24 (VCCB); also elsewhere on the board
+5V: J1.1, J1.2, J2.1, J2.2, J3.1, J3.2, J4.1, J4.2, U9.1 (VCCA); also elsewhere on the board
/A0: J1.19, J3.19; also elsewhere on the board
/A1: J1.20, J3.20; also elsewhere on the board
/A2: J1.21, J3.21; also elsewhere on the board
/A3: J1.22, J3.22; also elsewhere on the board
/A4: J1.23, J3.23; also elsewhere on the board
/A5: J1.24, J3.24; also elsewhere on the board
/A6: J1.25, J3.25; also elsewhere on the board
/A7: J1.26, J3.26; also elsewhere on the board
/A8: J1.27, J3.27; also elsewhere on the board
/A9: J1.28, J3.28; also elsewhere on the board
/A10: J1.29, J3.29; also elsewhere on the board
/A11: J1.30, J3.30; also elsewhere on the board
/A12: J1.31, J3.31; also elsewhere on the board
/A13: J1.32, J3.32; also elsewhere on the board
/A14: J1.33, J3.33; also elsewhere on the board
/A15: J1.34, J3.34; also elsewhere on the board
/A16: J1.35, J3.35; also elsewhere on the board
/A17: J1.36, J3.36; also elsewhere on the board
/A18: J1.37, J3.37; also elsewhere on the board
/A19: J1.38, J3.38; also elsewhere on the board
/Bus/DB0: J1.10, J3.10, U9.14 (B7)
/Bus/DB1: J1.11, J3.11, U9.15 (B6)
/Bus/DB2: J1.12, J3.12, U9.16 (B5)
/Bus/DB3: J1.13, J3.13, U9.17 (B4)
/Bus/DB4: J1.14, J3.14, U9.18 (B3)
/Bus/DB5: J1.15, J3.15, U9.19 (B2)
/Bus/DB6: J1.16, J3.16, U9.20 (B1)
/Bus/DB7: J1.17, J3.17, U9.21 (B0)
/Bus/TDRTN: J2.32, J4.32
/Bus/~DOE: J22.1, U9.22 (CE); also elsewhere on the board
/CLKF: J2.14, J4.14
/CLKS: J2.13, J4.13; also elsewhere on the board
/D0: U9.10 (A7); also elsewhere on the board
/D1: U9.9 (A6); also elsewhere on the board
/D2: U9.8 (A5); also elsewhere on the board
/D3: U9.7 (A4); also elsewhere on the board
/D4: U9.6 (A3); also elsewhere on the board
/D5: U9.5 (A2); also elsewhere on the board
/D6: U9.4 (A1); also elsewhere on the board
/D7: U9.3 (A0); also elsewhere on the board
/MOSI: J2.30, J4.30; also elsewhere on the board
/PH0: J2.11, J4.11; also elsewhere on the board
/PHI1_e: J1.3, J3.3; also elsewhere on the board
/PHI2_e: J1.4, J3.4
/RES0: J2.7, J4.7
/RES1: J2.9, J4.9
/RX1: J2.10, J4.10; also elsewhere on the board
/RX2: J2.3, J4.3
/RX3: J2.5, J4.5
/R/~W_e: J1.6, J3.6, J5.1, U9.2 (A->B)
/SCK: J2.31, J4.31; also elsewhere on the board
/TCK: J2.35, J4.35
/TDI: J2.36, J4.36
/TDO: J2.34, J4.34
/TMS: J2.33, J4.33
/TX1: J2.8, J4.8; also elsewhere on the board
/TX2: J2.4, J4.4
/TX3: J2.6, J4.6
/~BUSFREE: J2.15, J4.15
/~IOREQ: J1.9, J3.9; also elsewhere on the board
/~MRD: J1.7, J3.7
/~MWR: J1.8, J3.8
/~PH0: J2.12, J4.12
/~RAMWE0: J2.29, J4.29
/~RAMWE1: J2.28, J4.28
/~RAMWE2: J2.27, J4.27
/~RAMWE3: J2.26, J4.26
/~RAMWE4: J2.25, J4.25
/~RAMWE5: J2.24, J4.24
/~RAMWE6: J2.23, J4.23
/~RAMWE7: J2.22, J4.22
/~RAMWE8: J2.21, J4.21
/~RAMWE9: J2.20, J4.20
/~RAMWE10: J2.19, J4.19
/~RAMWE11: J2.18, J4.18
/~RAMWE12: J2.17, J4.17
/~RAMWE13: J2.16, J4.16
/~RST: J1.18, J3.18; also elsewhere on the board
/~ZRD: J1.5, J3.5; also elsewhere on the board
GND: C4.2, J1.39, J1.40, J2.39, J2.40, J3.39, J3.40, J4.39, J4.40, U9.11 (GND), U9.12 (GND), U9.13 (GND); also elsewhere on the board

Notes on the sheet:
TDRTN must be connected to TDO at the last board if a CPLD is mounted!
The difference between the SN74LVCC4245ANSR and the SN74LVCC3245BNSR is the switched 5V and 3V3 Rails.

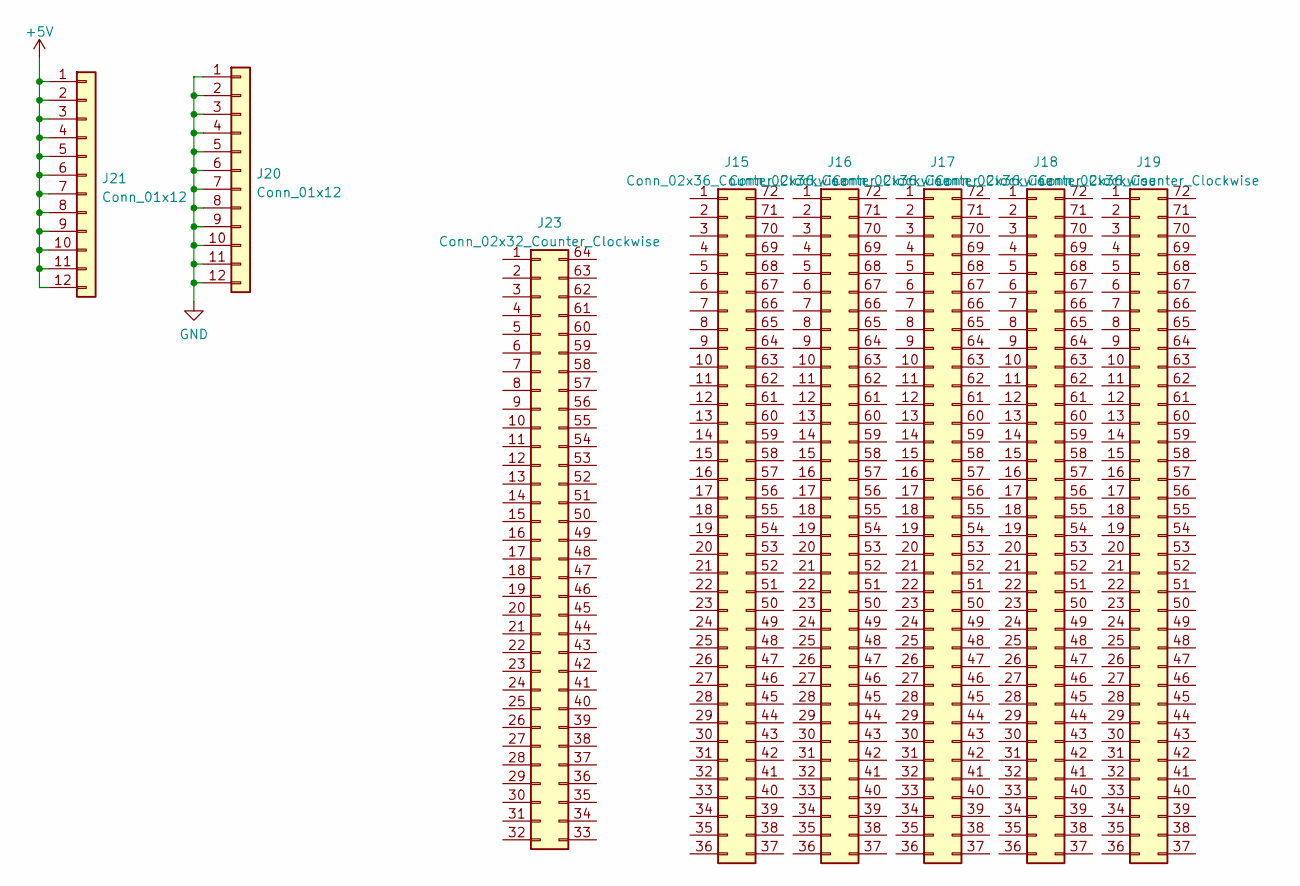
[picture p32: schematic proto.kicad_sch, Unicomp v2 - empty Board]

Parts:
J15, J16, J17, J18, J19: Conn_02x36_Counter_Clockwise; Proto_2x36
J20, J21: Conn_01x12; PinHeader_1x12_P2.54mm_Vertical
J23: Conn_02x32_Counter_Clockwise; Proto_2x32

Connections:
+5V: J21.1, J21.2, J21.3, J21.4, J21.5, J21.6, J21.7, J21.8, J21.9, J21.10, J21.11, J21.12; also elsewhere on the board
GND: J20.1, J20.2, J20.3, J20.4, J20.5, J20.6, J20.7, J20.8, J20.9, J20.10, J20.11, J20.12; also elsewhere on the board

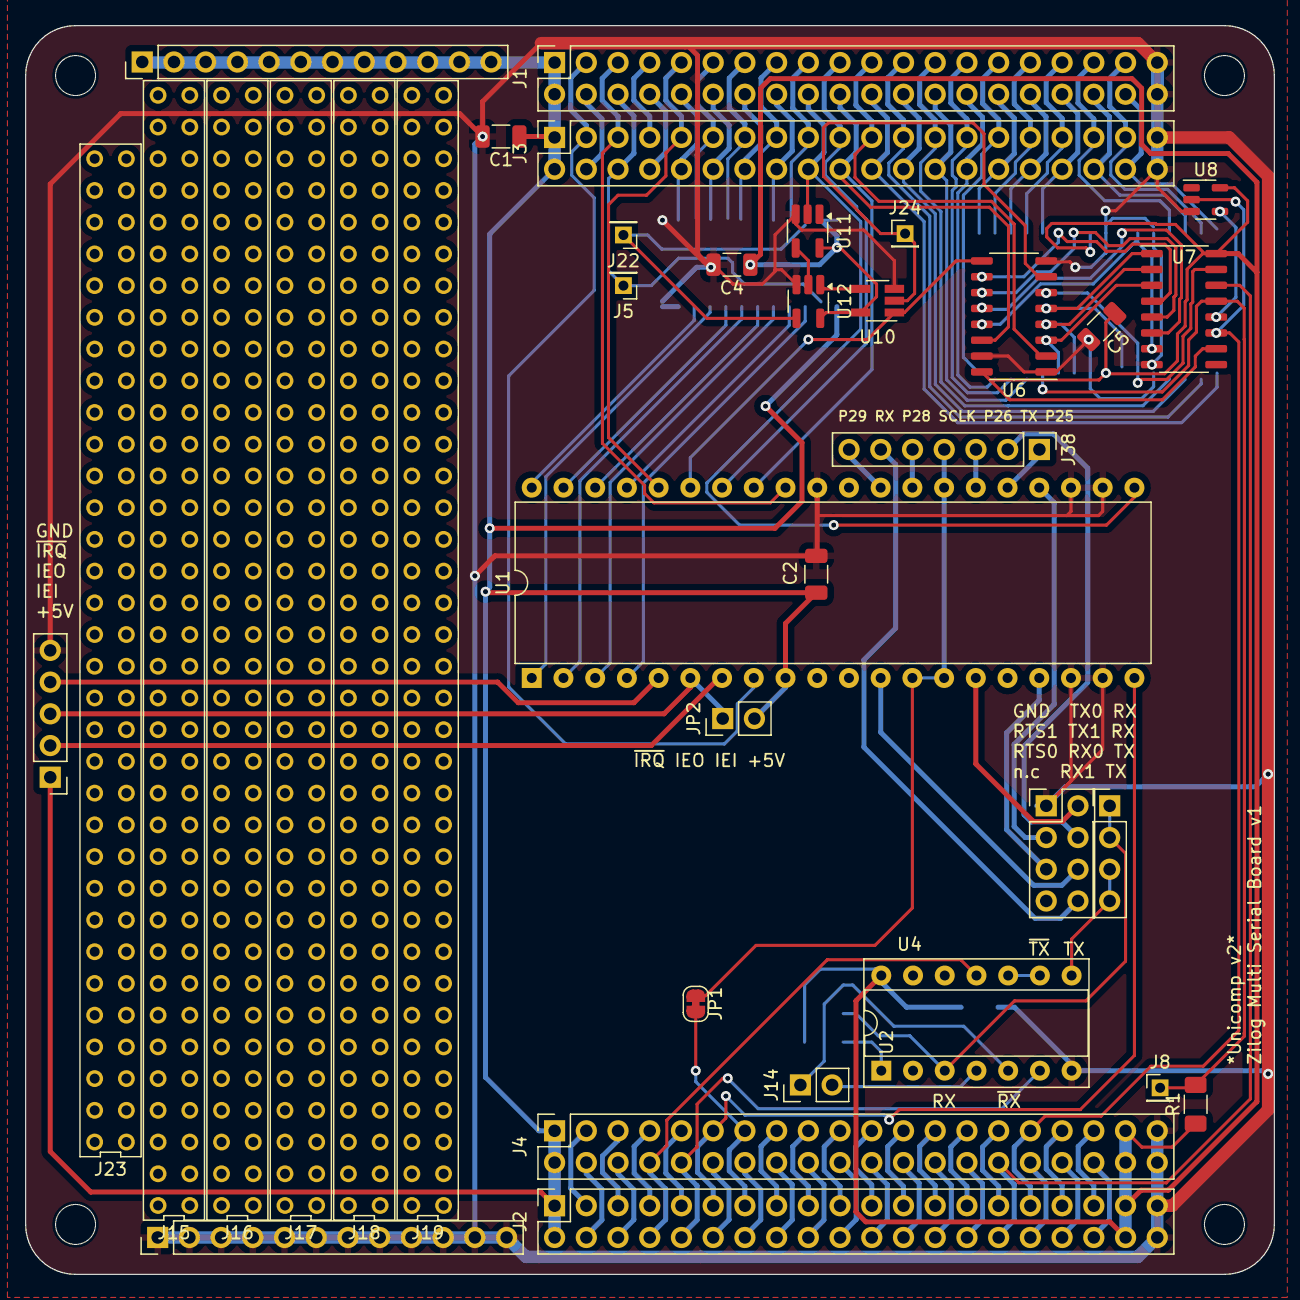
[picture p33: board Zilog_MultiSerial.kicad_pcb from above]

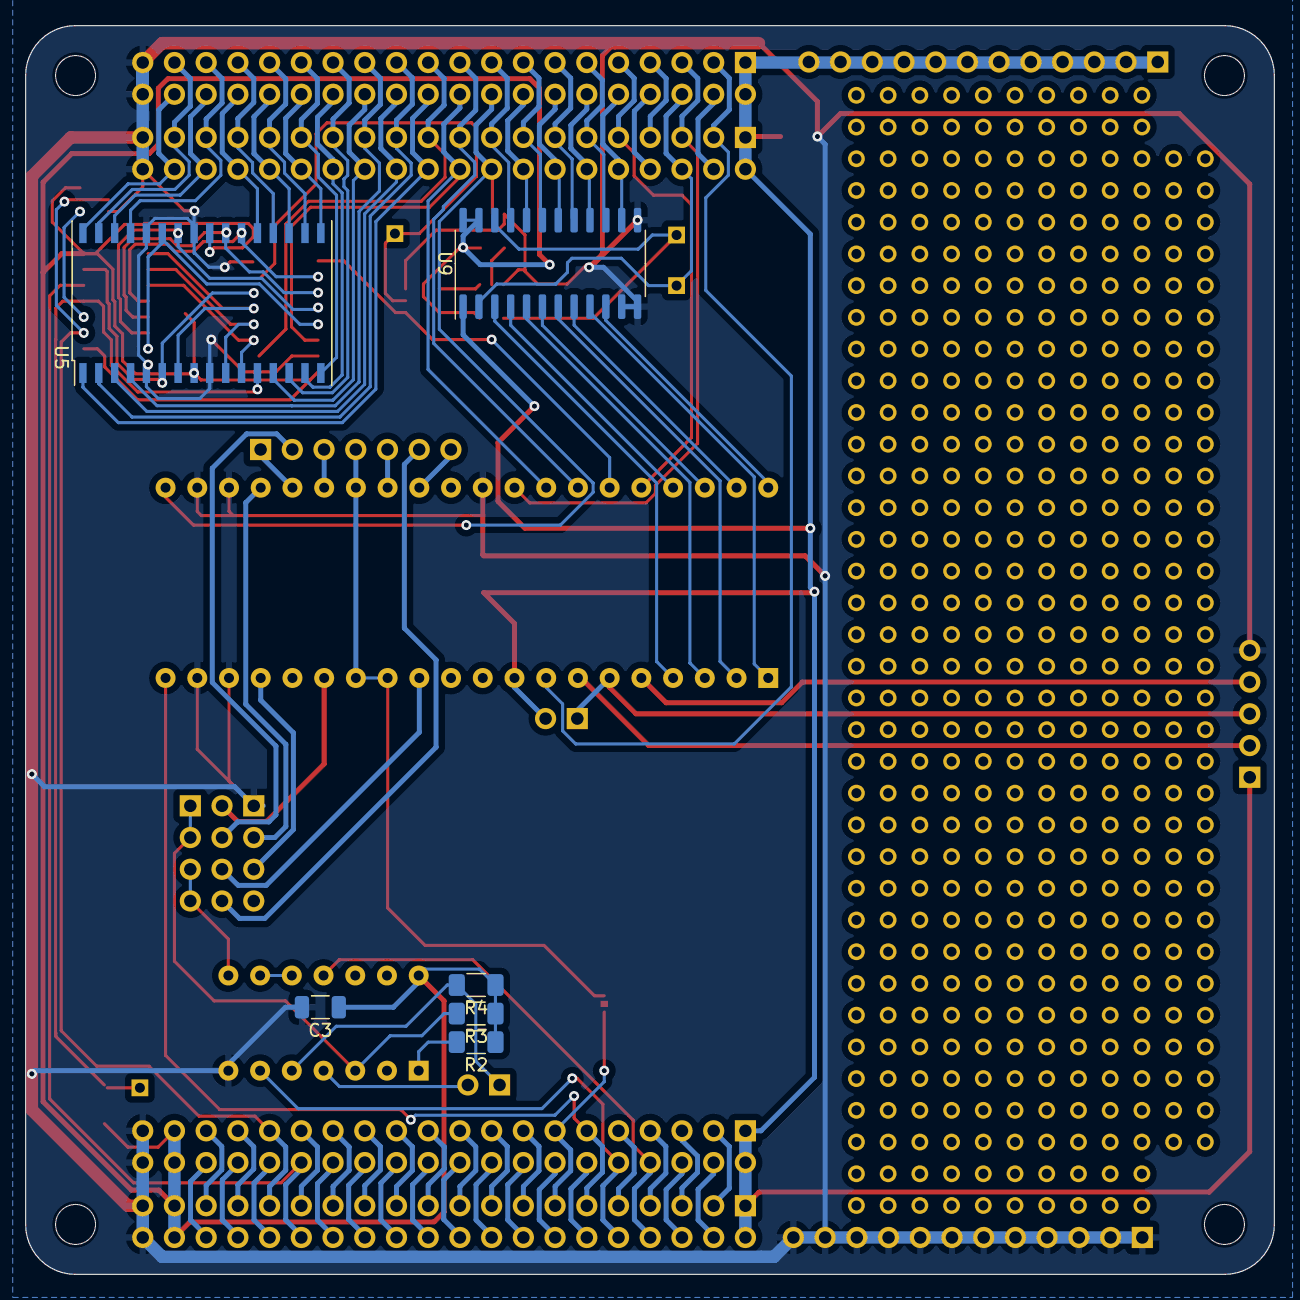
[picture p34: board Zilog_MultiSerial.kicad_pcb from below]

Board: 2 copper layers, 100.0 x 100.0 mm, 46 parts (6 on the bottom side), 116 nets.

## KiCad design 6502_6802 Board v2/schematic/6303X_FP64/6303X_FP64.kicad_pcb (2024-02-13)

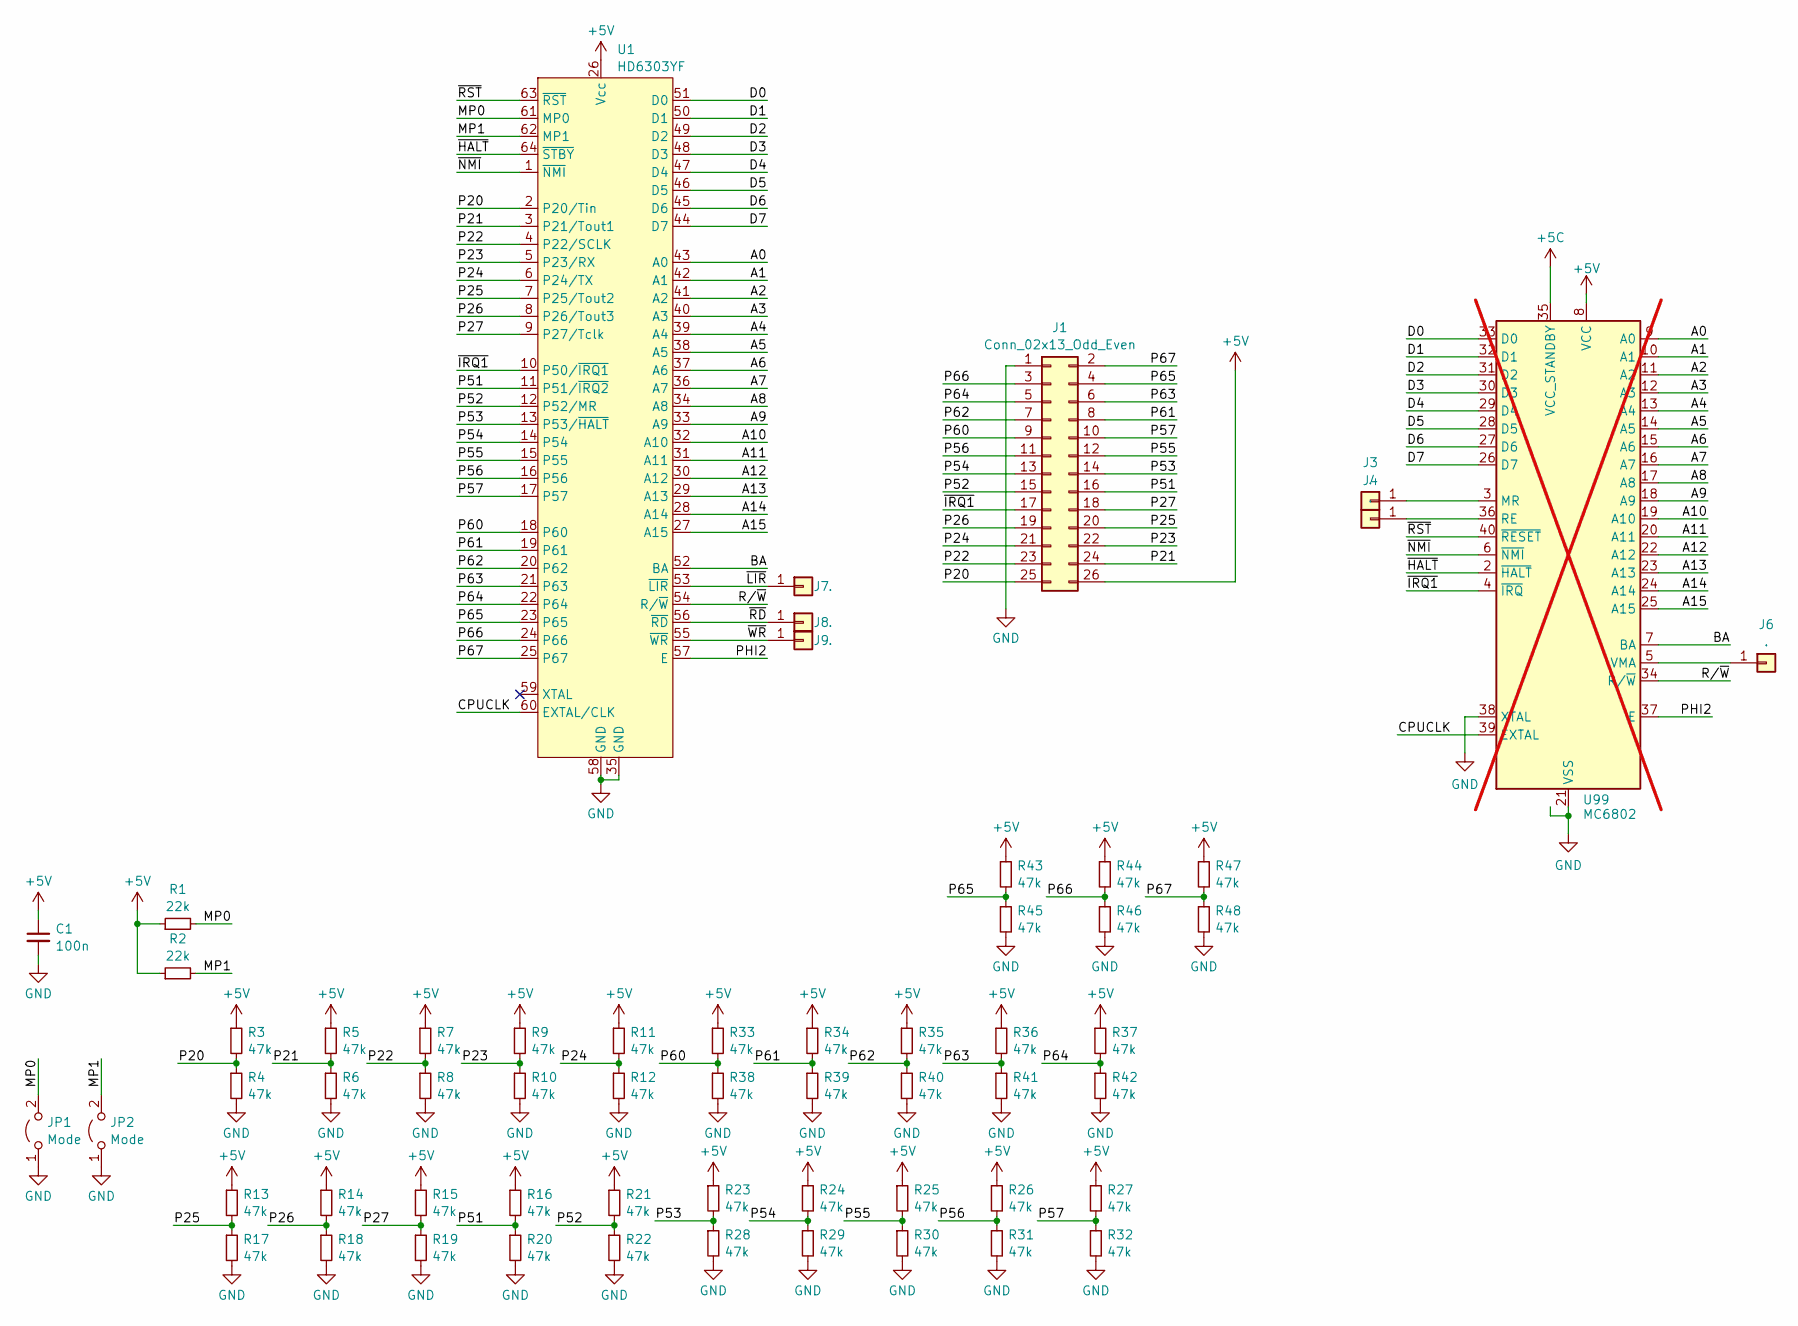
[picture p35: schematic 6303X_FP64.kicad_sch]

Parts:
C1: 100n; C_1206_3216Metric_Pad1.33x1.80mm_HandSolder
J1: Conn_02x13_Odd_Even; PinHeader_2x13_P2.54mm_Horizontal
J3, J4, J6, J7, J8, J9: .; PinHeader_1x01_P2.00mm_Vertical
JP1, JP2: Mode; PinHeader_1x02_P2.54mm_Vertical
R1, R2: 22k; R_1206_3216Metric_Pad1.30x1.75mm_HandSolder
R3, R4, R5, R6, R7, R8, R9, R10, R11, R12, R13, R14, R15, R16, R17, R18, R19, R20, R21, R22, R23, R24, R25, R26, R27, R28, R29, R30, R31, R32, R33, R34, R35, R36, R37, R38, R39, R40, R41, R42, R43, R44, R45, R46, R47, R48: 47k; R_1206_3216Metric_Pad1.30x1.75mm_HandSolder
U1: HD6303YF; QFP-64_14x20_Pitch1mm
U99: MC6802; DIP-40_W15.24mm; not fitted

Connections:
+5V: C1.1, J1.26, R1.1, R2.1, R3.1, R5.1, R7.1, R9.1, R11.1, R13.1, R14.1, R15.1, R16.1, R21.1, R23.1, R24.1, R25.1, R26.1, R27.1, R33.1, R34.1, R35.1, R36.1, R37.1, R43.1, R44.1, R47.1, U1.26 (Vcc); also elsewhere on the board
/A0: U1.43 (A0); also elsewhere on the board
/A1: U1.42 (A1); also elsewhere on the board
/A2: U1.41 (A2); also elsewhere on the board
/A3: U1.40 (A3); also elsewhere on the board
/A4: U1.39 (A4); also elsewhere on the board
/A5: U1.38 (A5); also elsewhere on the board
/A6: U1.37 (A6); also elsewhere on the board
/A7: U1.36 (A7); also elsewhere on the board
/A8: U1.34 (A8); also elsewhere on the board
/A9: U1.33 (A9); also elsewhere on the board
/A10: U1.32 (A10); also elsewhere on the board
/A11: U1.31 (A11); also elsewhere on the board
/A12: U1.30 (A12); also elsewhere on the board
/A13: U1.29 (A13); also elsewhere on the board
/A14: U1.28 (A14); also elsewhere on the board
/A15: U1.27 (A15); also elsewhere on the board
/BA: U1.52 (BA); also elsewhere on the board
/CPUCLK: U1.60 (EXTAL/CLK); also elsewhere on the board
/D0: U1.51 (D0); also elsewhere on the board
/D1: U1.50 (D1); also elsewhere on the board
/D2: U1.49 (D2); also elsewhere on the board
/D3: U1.48 (D3); also elsewhere on the board
/D4: U1.47 (D4); also elsewhere on the board
/D5: U1.46 (D5); also elsewhere on the board
/D6: U1.45 (D6); also elsewhere on the board
/D7: U1.44 (D7); also elsewhere on the board
/MP0: JP1.2 (B), R1.2, U1.61 (MP0)
/MP1: JP2.2 (B), R2.2, U1.62 (MP1)
/P20: J1.25, R3.2, R4.1, U1.2 (P20/Tin)
/P21: J1.24, R5.2, R6.1, U1.3 (P21/Tout1)
/P22: J1.23, R7.2, R8.1, U1.4 (P22/SCLK)
/P23: J1.22, R9.2, R10.1, U1.5 (P23/RX)
/P24: J1.21, R11.2, R12.1, U1.6 (P24/TX)
/P25: J1.20, R13.2, R17.1, U1.7 (P25/Tout2)
/P26: J1.19, R14.2, R18.1, U1.8 (P26/Tout3)
/P27: J1.18, R15.2, R19.1, U1.9 (P27/Tclk)
/P51: J1.16, R16.2, R20.1, U1.11 (P51/~IRQ2)
/P52: J1.15, R21.2, R22.1, U1.12 (P52/MR)
/P53: J1.14, R23.2, R28.1, U1.13 (P53/~HALT)
/P54: J1.13, R24.2, R29.1, U1.14 (P54)
/P55: J1.12, R25.2, R30.1, U1.15 (P55)
/P56: J1.11, R26.2, R31.1, U1.16 (P56)
/P57: J1.10, R27.2, R32.1, U1.17 (P57)
/P60: J1.9, R33.2, R38.1, U1.18 (P60)
/P61: J1.8, R34.2, R39.1, U1.19 (P61)
/P62: J1.7, R35.2, R40.1, U1.20 (P62)
/P63: J1.6, R36.2, R41.1, U1.21 (P63)
/P64: J1.5, R37.2, R42.1, U1.22 (P64)
/P65: J1.4, R43.2, R45.1, U1.23 (P65)
/P66: J1.3, R44.2, R46.1, U1.24 (P66)
/P67: J1.2, R47.2, R48.1, U1.25 (P67)
/PHI2: U1.57 (E); also elsewhere on the board
/R/~W: U1.54 (R/~W); also elsewhere on the board
/~HALT: U1.64 (~STBY); also elsewhere on the board
/~IRQ1: J1.17, U1.10 (P50/~IRQ1); also elsewhere on the board
/~LIR: J7.1, U1.53 (~LIR)
/~NMI: U1.1 (~NMI); also elsewhere on the board
/~RD: J8.1, U1.56 (~RD)
/~RST: U1.63 (~RST); also elsewhere on the board
/~WR: J9.1, U1.55 (~WR)
GND: C1.2, J1.1, JP1.1 (A), JP2.1 (A), R4.2, R6.2, R8.2, R10.2, R12.2, R17.2, R18.2, R19.2, R20.2, R22.2, R28.2, R29.2, R30.2, R31.2, R32.2, R38.2, R39.2, R40.2, R41.2, R42.2, R45.2, R46.2, R48.2, U1.35 (GND), U1.58 (GND); also elsewhere on the board
unnamed 63: J3.1; also elsewhere on the board
unnamed 64: J4.1; also elsewhere on the board
unnamed 65: J6.1; also elsewhere on the board

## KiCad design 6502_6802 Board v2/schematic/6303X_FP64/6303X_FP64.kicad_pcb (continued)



Board: 2 copper layers, 66.5 x 50.5 mm, 60 parts (49 on the bottom side), 65 nets.

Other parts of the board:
U3: MC6802; DIP-40_W15.24mm

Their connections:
+5V: U3.8 (VCC); also elsewhere on the board
/A0: U3.9 (A0); also elsewhere on the board
/A1: U3.10 (A1); also elsewhere on the board
/A2: U3.11 (A2); also elsewhere on the board
/A3: U3.12 (A3); also elsewhere on the board
/A4: U3.13 (A4); also elsewhere on the board
/A5: U3.14 (A5); also elsewhere on the board
/A6: U3.15 (A6); also elsewhere on the board
/A7: U3.16 (A7); also elsewhere on the board
/A8: U3.17 (A8); also elsewhere on the board
/A9: U3.18 (A9); also elsewhere on the board
/A10: U3.19 (A10); also elsewhere on the board
/A11: U3.20 (A11); also elsewhere on the board
/A12: U3.22 (A12); also elsewhere on the board
/A13: U3.23 (A13); also elsewhere on the board
/A14: U3.24 (A14); also elsewhere on the board
/A15: U3.25 (A15); also elsewhere on the board
/BA: U3.7 (BA); also elsewhere on the board
/CPUCLK: U3.39 (EXTAL); also elsewhere on the board
/D0: U3.33 (D0); also elsewhere on the board
/D1: U3.32 (D1); also elsewhere on the board
/D2: U3.31 (D2); also elsewhere on the board
/D3: U3.30 (D3); also elsewhere on the board
/D4: U3.29 (D4); also elsewhere on the board
/D5: U3.28 (D5); also elsewhere on the board
/D6: U3.27 (D6); also elsewhere on the board
/D7: U3.26 (D7); also elsewhere on the board
/PHI2: U3.37 (E); also elsewhere on the board
/R/~W: U3.34 (R/~W); also elsewhere on the board
/~HALT: U3.2 (~HALT); also elsewhere on the board
/~IRQ1: U3.4 (~IRQ); also elsewhere on the board
/~NMI: U3.6 (~NMI); also elsewhere on the board
/~RST: U3.40 (~RESET); also elsewhere on the board
GND: U3.1 (VSS), U3.21 (VSS), U3.38 (XTAL); also elsewhere on the board
unnamed 63: U3.3 (MR); also elsewhere on the board
unnamed 64: U3.36 (RE); also elsewhere on the board
unnamed 65: U3.5 (VMA); also elsewhere on the board

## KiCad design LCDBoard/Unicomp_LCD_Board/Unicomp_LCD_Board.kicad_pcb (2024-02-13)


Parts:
C1, C2, C3: 100n; C_1206_3216Metric_Pad1.33x1.80mm_HandSolder
D1: 1N4148; D_A-405_P10.16mm_Horizontal
D2: ALARM; LED_D3.0mm
D3: ~{ON}; LED_D3.0mm
D4, D5: 1N4148; D_1206_3216Metric_Pad1.42x1.75mm_HandSolder
J1: BUS; PinHeader_2x20_P2.54mm_Horizontal
J2: ~{RAMCE}; PinHeader_1x01_P2.00mm_Vertical
J3, J4, J5, J6, J8, J9, J10, J11, J12, J13, J14, J16, J17, J18, J19, J20, J21, J23, J24, J27: .; PinHeader_1x01_P2.00mm_Vertical
J7, J30: P57; PinHeader_1x01_P2.00mm_Vertical
J15: NMI; PinHeader_1x01_P2.00mm_Vertical
J22: LCD_E; PinHeader_1x01_P2.00mm_Vertical
J25, J26: KBD_CLK; PinHeader_1x01_P2.00mm_Vertical
J28, J29: ~{RST}; PinHeader_1x01_P2.00mm_Vertical
J31: READY; PinHeader_1x01_P2.00mm_Vertical
J32: Keyb; PinHeader_1x07_P2.54mm_Vertical
J33: ~{STBY}; PinHeader_1x01_P2.00mm_Vertical
Q1: BC327; TO-92_Inline
R1: 1k5; R_Axial_DIN0207_L6.3mm_D2.5mm_P10.16mm_Horizontal
R2, R3, R4, R5: 1k5; R_1206_3216Metric_Pad1.30x1.75mm_HandSolder
R6, R8, R9, R10, R11, R12, R13, R14: 1k; R_1206_3216Metric_Pad1.30x1.75mm_HandSolder
R7, R15, R16, R17, R18: 47k; R_1206_3216Metric_Pad1.30x1.75mm_HandSolder
RV2: 10k; ALPS_RK09
SW1: ON; SW_PUSH_6mm
U1, U7: NHD-0420H1Z; PinSocket_1x16_P2.54mm_Vertical
U2: 4011; DIP-14_W7.62mm_Socket_LongPads
U3: 4081; DIP-14_W7.62mm_Socket_LongPads
U4: Recom RMSR-0505; Converter_DCDC_TRACO_TMR-1-xxxx_Dual_THT
U5: 4013; DIP-14_W7.62mm_Socket_LongPads
U6: 4040; DIP-16_W7.62mm_Socket_LongPads
U8, U9: 74LS00

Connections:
+5V: C1.1, J1.39, J1.40, Q1.3 (E), R2.2, R5.2, RV2.1, SW1.2, U2.14 (VDD), U3.14 (VDD), U4.1 (+Vin), U5.14 (VDD), U6.16 (VDD)
/A0: J1.22, U1.4 (RS), U7.4 (RS)
/A1: J1.21
/A2: J1.20
/A3: J1.19
/A4: J1.18
/A5: J1.17
/A6: J1.16
/A7: J1.15
/A8: J1.14
/A9: J1.13, J16.1
/A10: J1.12, J17.1
/A11: J1.11, J14.1
/A12: J1.10, J11.1
/A13: J1.9, U3.5
/A14: J1.8, U2.1, U8.1
/A15: J1.7, U2.5, U2.6
/A16: J1.6
/A17: J1.5
/A18: J1.4
/A19: J1.3
/D0: J1.31, U1.7 (DB0), U7.7 (DB0)
/D1: J1.30, U1.8 (DB1), U7.8 (DB1)
/D2: J1.29, U1.9 (DB2), U7.9 (DB2)
/D3: J1.28, U1.10 (DB3), U7.10 (DB3)
/D4: J1.27, U1.11 (DB4), U7.11 (DB4)
/D5: J1.26, U1.12 (DB5), U7.12 (DB5)
/D6: J1.25, U1.13 (DB6), U7.13 (DB6)
/D7: J1.24, U1.14 (DB7), U7.14 (DB7)
/LCD_Vo: R3.2, U1.3 (VO), U7.3 (VO)
/PHI1_e: J1.38
/PHI2_e: J1.37, J6.1
/R/~W_e: J1.35, U1.5 (R/W), U7.5 (R/W)
/VLDC: Q1.1 (C), R7.2, R18.2, U1.2 (VDD), U7.2 (VDD)
/~IORD: J1.36
/~IOWR: J1.32
/~LCDE: J10.1, U1.6 (E), U3.3, U7.6 (E)
/~MRD: J1.34
/~MWR: J1.33
/~RST: D1.1 (K), J1.23, J29.1
GND: C1.2, C2.1, C3.2, D2.1 (K), J1.1, J1.2, U1.1 (VSS), U1.15 (A), U2.7 (VSS), U3.7 (VSS), U4.2 (-Vin), U4.6 (+Vout), U5.4 (R), U5.6 (S), U5.7 (VSS), U5.8 (S), U6.8 (VSS), U7.1 (VSS), U7.15 (A)
unnamed: C3.1, R3.1, RV2.2
unnamed: D1.2 (A), R1.2, U2.2, U3.6, U8.2
unnamed: D2.2 (A), R4.2
unnamed: D3.2 (A), R5.1
unnamed: D3.1 (K), R17.2, U5.13 (Q)
unnamed: D4.2 (A), J33.1, R18.1
unnamed: D4.1 (K), D5.1 (K), U5.12 (~Q)
unnamed: D5.2 (A), R6.1
unnamed: J2.1, U2.3, U8.3
unnamed: J3.1, J4.1, U3.2, U3.4
unnamed: J5.1, U3.1
unnamed: J7.1, U5.10 (R)
unnamed: J8.1, U5.9 (D)
unnamed: J9.1, U3.8
unnamed: J12.1, U2.9
unnamed: J13.1, U3.9
unnamed: J15.1, U2.12, U8.12
unnamed: J18.1, U5.5 (D)
unnamed: J19.1, U3.10
unnamed: J20.1, U5.3 (C)
unnamed: J21.1, U5.11 (C)
unnamed: J22.1, U2.8
unnamed: J23.1, U2.13, U8.13
unnamed: J24.1, U5.1 (Q)
unnamed: J25.1, U3.11
unnamed: J26.1, U6.10 (CLK)
unnamed: J27.1, U6.11 (Reset)
unnamed: J28.1, R6.2, R7.1
unnamed: J30.1, R16.1, SW1.1
unnamed: J31.1, R15.1
unnamed: J32.1, R8.1
unnamed: J32.2, R9.1
unnamed: J32.3, R10.1
unnamed: J32.4, R11.1
unnamed: J32.5, R14.1
unnamed: J32.6, R12.1
unnamed: J32.7, R13.1
unnamed: Q1.2 (B), R17.1
unnamed: R1.1, U2.4
unnamed: R2.1, U1.16 (K), U7.16 (K)
unnamed: U2.10, U3.12
unnamed: U2.11, U3.13, U8.11
unnamed: C2.2, RV2.3, U4.4 (-Vout)
unnamed: R4.1, U5.2 (~Q)
unnamed: R8.2, U6.9 (Q0)
unnamed: R9.2, U6.7 (Q1)
unnamed: R10.2, U6.6 (Q2)
unnamed: R11.2, U6.5 (Q3)
unnamed: R12.2, U6.3 (Q4)
unnamed: R13.2, U6.2 (Q5)
unnamed: R14.2, U6.4 (Q6)
unnamed: R15.2, R16.2, U6.1 (Q11)

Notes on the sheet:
<-Done
Done->
use Sockets with Caps integrated!
<-changed



Board: 2 copper layers, 88.0 x 85.0 mm, 69 parts (22 on the bottom side), 76 nets.

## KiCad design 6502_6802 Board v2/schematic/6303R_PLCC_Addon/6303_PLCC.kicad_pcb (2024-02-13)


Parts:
C1: 100n; C_1206_3216Metric_Pad1.33x1.80mm_HandSolder
D1, D2, D3: 1N4148; D_1206_3216Metric_Pad1.42x1.75mm_HandSolder
J1: Conn_02x08_Odd_Even; PinHeader_2x08_P2.54mm_Horizontal
J2, J3, J4, J5, J6: .; PinHeader_1x01_P2.00mm_Vertical
JP1, JP2, JP3: Mode; PinHeader_1x02_P2.54mm_Vertical
JP5: HALT/XTAL; PinHeader_1x03_P2.54mm_Vertical
JP6: BA/EXTAL; PinHeader_1x03_P2.54mm_Vertical
R1, R2, R3: 22k; R_1206_3216Metric_Pad1.30x1.75mm_HandSolder
U1: HD6303RCP; PLCC-52_SMD-Socket
U2: 74LS573; DIP-20_W7.62mm_Socket_LongPads
U99: MC6802; DIP-40_W15.24mm; not fitted

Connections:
+5V: C1.1, J1.16, R1.1, R2.1, R3.1, U1.27 (Vcc), U2.20 (VCC); also elsewhere on the board
/A0: U2.19 (Q0); also elsewhere on the board
/A1: U2.18 (Q1); also elsewhere on the board
/A2: U2.17 (Q2); also elsewhere on the board
/A3: U2.16 (Q3); also elsewhere on the board
/A4: U2.15 (Q4); also elsewhere on the board
/A5: U2.14 (Q5); also elsewhere on the board
/A6: U2.13 (Q6); also elsewhere on the board
/A7: U2.12 (Q7); also elsewhere on the board
/A8: U1.37 (A8); also elsewhere on the board
/A9: U1.36 (A9); also elsewhere on the board
/A10: U1.35 (A10); also elsewhere on the board
/A11: U1.32 (A11); also elsewhere on the board
/A12: U1.31 (A12); also elsewhere on the board
/A13: U1.30 (A13); also elsewhere on the board
/A14: U1.29 (A14); also elsewhere on the board
/A15: U1.28 (A15); also elsewhere on the board
/AS: J6.1, U1.51 (AS), U2.11 (Load); also elsewhere on the board
/BA: JP6.3 (B); also elsewhere on the board
/CPUCLK: JP6.1 (A); also elsewhere on the board
/D0: U1.49 (AD0), U2.2 (D0); also elsewhere on the board
/D1: U1.48 (AD1), U2.3 (D1); also elsewhere on the board
/D2: U1.45 (AD2), U2.4 (D2); also elsewhere on the board
/D3: U1.44 (AD3), U2.5 (D3); also elsewhere on the board
/D4: U1.43 (AD4), U2.6 (D4); also elsewhere on the board
/D5: U1.41 (AD5), U2.7 (D5); also elsewhere on the board
/D6: U1.40 (AD6), U2.8 (D6); also elsewhere on the board
/D7: U1.39 (AD7), U2.9 (D7); also elsewhere on the board
/P10: J1.7, U1.17 (P10)
/P11: J1.8, U1.18 (P11)
/P12: J1.9, U1.19 (P12)
/P13: J1.10, U1.22 (P13)
/P14: J1.11, U1.23 (P14)
/P15: J1.12, U1.24 (P15)
/P16: J1.13, U1.25 (P16)
/P17: J1.14, U1.26 (P17)
/P20: J1.2, JP1.2 (B), R1.2, U1.11 (P20/Tin)
/P21: J1.3, JP2.2 (B), R2.2, U1.12 (P21/Tout1)
/P22: J1.4, JP3.2 (B), R3.2, U1.13 (P22/SCLK)
/P23: J1.5, U1.14 (P23/RX)
/P24: J1.6, U1.15 (P24/TX)
/PHI2: U1.52 (E); also elsewhere on the board
/R/~W: U1.50 (R/~W); also elsewhere on the board
/~HALT: J5.1, JP5.3 (B); also elsewhere on the board
/~IRQ1: U1.6 (~IRQ1); also elsewhere on the board
/~NMI: U1.5 (~NMI); also elsewhere on the board
/~RST: D1.1 (K), D2.1 (K), D3.1 (K), U1.9 (~RST); also elsewhere on the board
GND: C1.2, J1.1, JP5.1 (A), U1.1 (GND), U2.1 (OE), U2.10 (GND); also elsewhere on the board
unnamed: D1.2 (A), JP1.1 (A)
unnamed: D2.2 (A), JP2.1 (A)
unnamed: D3.2 (A), JP3.1 (A)
unnamed: J1.15, J2.1
unnamed 53: J3.1; also elsewhere on the board
unnamed 54: J4.1; also elsewhere on the board
unnamed: JP5.2 (C), U1.2 (XTAL)
unnamed: JP6.2 (C), U1.4 (EXTAL/CLK)

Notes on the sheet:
forgot ~{STBY} Pullup!
This does NOT work for HD6303!
E is Clock in on 6803E!
HD6303 needes Pin2 open!



Board: 2 copper layers, 68.0 x 49.8 mm, 21 parts (4 on the bottom side), 56 nets.

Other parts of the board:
U3: MC6802; DIP-40_W15.24mm

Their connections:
+5V: U3.8 (VCC); also elsewhere on the board
/A0: U3.9 (A0); also elsewhere on the board
/A1: U3.10 (A1); also elsewhere on the board
/A2: U3.11 (A2); also elsewhere on the board
/A3: U3.12 (A3); also elsewhere on the board
/A4: U3.13 (A4); also elsewhere on the board
/A5: U3.14 (A5); also elsewhere on the board
/A6: U3.15 (A6); also elsewhere on the board
/A7: U3.16 (A7); also elsewhere on the board
/A8: U3.17 (A8); also elsewhere on the board
/A9: U3.18 (A9); also elsewhere on the board
/A10: U3.19 (A10); also elsewhere on the board
/A11: U3.20 (A11); also elsewhere on the board
/A12: U3.22 (A12); also elsewhere on the board
/A13: U3.23 (A13); also elsewhere on the board
/A14: U3.24 (A14); also elsewhere on the board
/A15: U3.25 (A15); also elsewhere on the board
/AS: U3.5 (VMA); also elsewhere on the board
/BA: U3.7 (BA); also elsewhere on the board
/CPUCLK: U3.39 (EXTAL); also elsewhere on the board
/D0: U3.33 (D0); also elsewhere on the board
/D1: U3.32 (D1); also elsewhere on the board
/D2: U3.31 (D2); also elsewhere on the board
/D3: U3.30 (D3); also elsewhere on the board
/D4: U3.29 (D4); also elsewhere on the board
/D5: U3.28 (D5); also elsewhere on the board
/D6: U3.27 (D6); also elsewhere on the board
/D7: U3.26 (D7); also elsewhere on the board
/PHI2: U3.37 (E); also elsewhere on the board
/R/~W: U3.34 (R/~W); also elsewhere on the board
/~HALT: U3.2 (~HALT); also elsewhere on the board
/~IRQ1: U3.4 (~IRQ); also elsewhere on the board
/~NMI: U3.6 (~NMI); also elsewhere on the board
/~RST: U3.40 (~RESET); also elsewhere on the board
GND: U3.1 (VSS), U3.21 (VSS), U3.38 (XTAL); also elsewhere on the board
unnamed 53: U3.3 (MR); also elsewhere on the board
unnamed 54: U3.36 (RE); also elsewhere on the board

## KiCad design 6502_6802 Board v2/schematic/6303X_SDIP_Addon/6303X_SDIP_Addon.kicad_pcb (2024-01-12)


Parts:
C1: 100n; C_1206_3216Metric_Pad1.33x1.80mm_HandSolder
J1: Conn_02x13_Odd_Even; PinHeader_2x13_P2.54mm_Horizontal
J3, J4, J6, J7, J8, J9: .; PinHeader_1x01_P2.00mm_Vertical
JP1, JP2: Mode; PinHeader_1x02_P2.54mm_Vertical
R1, R2: 22k; R_1206_3216Metric_Pad1.30x1.75mm_HandSolder
U2: HD6303XP; DIP-64_W19.05mm_P1.77
U99: MC6802; DIP-40_W15.24mm; not fitted

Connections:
+5V: C1.1, J1.26, R1.1, R2.1, U2.33 (Vcc); also elsewhere on the board
/A0: U2.50 (A0); also elsewhere on the board
/A1: U2.49 (A1); also elsewhere on the board
/A2: U2.48 (A2); also elsewhere on the board
/A3: U2.47 (A3); also elsewhere on the board
/A4: U2.46 (A4); also elsewhere on the board
/A5: U2.45 (A5); also elsewhere on the board
/A6: U2.44 (A6); also elsewhere on the board
/A7: U2.43 (A7); also elsewhere on the board
/A8: U2.41 (A8); also elsewhere on the board
/A9: U2.40 (A9); also elsewhere on the board
/A10: U2.39 (A10); also elsewhere on the board
/A11: U2.38 (A11); also elsewhere on the board
/A12: U2.37 (A12); also elsewhere on the board
/A13: U2.36 (A13); also elsewhere on the board
/A14: U2.35 (A14); also elsewhere on the board
/A15: U2.34 (A15); also elsewhere on the board
/BA: U2.59 (BA); also elsewhere on the board
/CPUCLK: U2.3 (EXTAL/CLK); also elsewhere on the board
/D0: U2.58 (D0); also elsewhere on the board
/D1: U2.57 (D1); also elsewhere on the board
/D2: U2.56 (D2); also elsewhere on the board
/D3: U2.55 (D3); also elsewhere on the board
/D4: U2.54 (D4); also elsewhere on the board
/D5: U2.53 (D5); also elsewhere on the board
/D6: U2.52 (D6); also elsewhere on the board
/D7: U2.51 (D7); also elsewhere on the board
/MP0: JP1.2 (B), R1.2, U2.4 (MP0)
/MP1: JP2.2 (B), R2.2, U2.5 (MP1)
/P20: J1.25, U2.9 (P20/Tin)
/P21: J1.24, U2.10 (P21/Tout1)
/P22: J1.23, U2.11 (P22/SCLK)
/P23: J1.22, U2.12 (P23/RX)
/P24: J1.21, U2.13 (P24/TX)
/P25: J1.20, U2.14 (P25/Tout2)
/P26: J1.19, U2.15 (P26/Tout3)
/P27: J1.18, U2.16 (P27/Tclk)
/P51: J1.16, U2.18 (P51/~IRQ2)
/P52: J1.15, U2.19 (P52/MR)
/P53: J1.14, U2.20 (P53/~HALT)
/P54: J1.13, U2.21 (P54)
/P55: J1.12, U2.22 (P55)
/P56: J1.11, U2.23 (P56)
/P57: J1.10, U2.24 (P57)
/P60: J1.9, U2.25 (P60)
/P61: J1.8, U2.26 (P61)
/P62: J1.7, U2.27 (P62)
/P63: J1.6, U2.28 (P63)
/P64: J1.5, U2.29 (P64)
/P65: J1.4, U2.30 (P65)
/P66: J1.3, U2.31 (P66)
/P67: J1.2, U2.32 (P67)
/PHI2: U2.64 (E); also elsewhere on the board
/R/~W: U2.61 (R/~W); also elsewhere on the board
/~HALT: U2.7 (~STBY); also elsewhere on the board
/~IRQ1: J1.17, U2.17 (P50/~IRQ1); also elsewhere on the board
/~LIR: J7.1, U2.60 (~LIR)
/~NMI: U2.8 (~NMI); also elsewhere on the board
/~RD: J8.1, U2.63 (~RD)
/~RST: U2.6 (~RST); also elsewhere on the board
/~WR: J9.1, U2.62 (~WR)
GND: C1.2, J1.1, JP1.1 (A), JP2.1 (A), U2.1 (GND), U2.42 (GND); also elsewhere on the board
unnamed 63: J3.1; also elsewhere on the board
unnamed 64: J4.1; also elsewhere on the board
unnamed 65: J6.1; also elsewhere on the board



Board: 2 copper layers, 71.5 x 51.0 mm, 14 parts (3 on the bottom side), 65 nets.

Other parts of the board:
U3: MC6802; DIP-40_W15.24mm

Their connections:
+5V: U3.8 (VCC); also elsewhere on the board
/A0: U3.9 (A0); also elsewhere on the board
/A1: U3.10 (A1); also elsewhere on the board
/A2: U3.11 (A2); also elsewhere on the board
/A3: U3.12 (A3); also elsewhere on the board
/A4: U3.13 (A4); also elsewhere on the board
/A5: U3.14 (A5); also elsewhere on the board
/A6: U3.15 (A6); also elsewhere on the board
/A7: U3.16 (A7); also elsewhere on the board
/A8: U3.17 (A8); also elsewhere on the board
/A9: U3.18 (A9); also elsewhere on the board
/A10: U3.19 (A10); also elsewhere on the board
/A11: U3.20 (A11); also elsewhere on the board
/A12: U3.22 (A12); also elsewhere on the board
/A13: U3.23 (A13); also elsewhere on the board
/A14: U3.24 (A14); also elsewhere on the board
/A15: U3.25 (A15); also elsewhere on the board
/BA: U3.7 (BA); also elsewhere on the board
/CPUCLK: U3.39 (EXTAL); also elsewhere on the board
/D0: U3.33 (D0); also elsewhere on the board
/D1: U3.32 (D1); also elsewhere on the board
/D2: U3.31 (D2); also elsewhere on the board
/D3: U3.30 (D3); also elsewhere on the board
/D4: U3.29 (D4); also elsewhere on the board
/D5: U3.28 (D5); also elsewhere on the board
/D6: U3.27 (D6); also elsewhere on the board
/D7: U3.26 (D7); also elsewhere on the board
/PHI2: U3.37 (E); also elsewhere on the board
/R/~W: U3.34 (R/~W); also elsewhere on the board
/~HALT: U3.2 (~HALT); also elsewhere on the board
/~IRQ1: U3.4 (~IRQ); also elsewhere on the board
/~NMI: U3.6 (~NMI); also elsewhere on the board
/~RST: U3.40 (~RESET); also elsewhere on the board
GND: U3.1 (VSS), U3.21 (VSS), U3.38 (XTAL); also elsewhere on the board
unnamed 63: U3.3 (MR); also elsewhere on the board
unnamed 64: U3.36 (RE); also elsewhere on the board
unnamed 65: U3.5 (VMA); also elsewhere on the board

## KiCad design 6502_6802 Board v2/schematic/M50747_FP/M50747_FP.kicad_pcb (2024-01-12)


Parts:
C1: 100n; C_1206_3216Metric_Pad1.33x1.80mm_HandSolder
J1: Conn_02x16_Odd_Even; PinHeader_2x16_P2.54mm_Horizontal
J2, J3, J4, J6, J7, J8: .; PinHeader_1x01_P2.00mm_Vertical
JP1: Mode; SolderJumper-3_P1.3mm_Open_Pad1.0x1.5mm
R1: 1k; R_1206_3216Metric
U1: M50747QFP; QFP-72_13.2x18_Pitch0.8mm
U99: MC6802; DIP-40_W15.24mm; not fitted

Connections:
+5V: C1.1, J1.32, JP1.3 (B), U1.67 (Vcc); also elsewhere on the board
/A0: U1.54 (A0); also elsewhere on the board
/A1: U1.53 (A1); also elsewhere on the board
/A2: U1.52 (A2); also elsewhere on the board
/A3: U1.51 (A3); also elsewhere on the board
/A4: U1.50 (A4); also elsewhere on the board
/A5: U1.49 (A5); also elsewhere on the board
/A6: U1.48 (A6); also elsewhere on the board
/A7: U1.47 (A7); also elsewhere on the board
/A8: U1.46 (A8); also elsewhere on the board
/A9: U1.45 (A9); also elsewhere on the board
/A10: U1.44 (A10); also elsewhere on the board
/A11: U1.43 (A11); also elsewhere on the board
/A12: U1.42 (A12); also elsewhere on the board
/A13: U1.41 (A13); also elsewhere on the board
/A14: U1.40 (A14); also elsewhere on the board
/A15: U1.39 (A15); also elsewhere on the board
/BA: J7.1; also elsewhere on the board
/CPUCLK: U1.26 (EXTAL/CLK); also elsewhere on the board
/D0: U1.63 (D0); also elsewhere on the board
/D1: U1.62 (D1); also elsewhere on the board
/D2: U1.61 (D2); also elsewhere on the board
/D3: U1.60 (D3); also elsewhere on the board
/D4: U1.59 (D4); also elsewhere on the board
/D5: U1.58 (D5); also elsewhere on the board
/D6: U1.57 (D6); also elsewhere on the board
/D7: U1.56 (D7); also elsewhere on the board
/P33: J1.11, U1.16 (P33/CNTR)
/P34: J1.12, U1.15 (P34/RxD)
/P35: J1.13, U1.14 (P35/TxD)
/P36: J1.14, U1.13 (P36/CLK)
/P37: J1.15, U1.12 (P37/SRDY)
/P40: J1.16, U1.11 (P40)
/P41: J1.17, U1.10 (P41)
/P42: J1.18, U1.9 (P42)
/P43: J1.19, U1.8 (P43)
/P44: J1.20, U1.7 (P44)
/P45: J1.21, U1.6 (P45)
/P46: J1.22, U1.5 (P46)
/P47: J1.23, U1.4 (P47)
/P50: J1.2, U1.37 (P50)
/P51: J1.3, U1.36 (P51)
/P52: J1.4, U1.35 (P52)
/P53: J1.5, U1.34 (P53)
/P54: J1.6, U1.33 (P54)
/P55: J1.7, U1.32 (P55)
/P56: J1.8, U1.31 (P56)
/P57: J1.9, U1.30 (P57)
/P60: J1.24, U1.3 (P60)
/P61: J1.25, U1.2 (P61)
/P62: J1.26, U1.1 (P62)
/P63: J1.27, U1.72 (P63)
/P64: J1.28, U1.71 (P64)
/P65: J1.29, U1.70 (P65)
/P66: J1.30, U1.69 (P66)
/P67: J1.31, U1.68 (P67)
/PHI2: U1.28 (PHI); also elsewhere on the board
/R/~W: U1.19 (P30/R/~W); also elsewhere on the board
/SYNC: J1.10, U1.18 (P31/SYNC)
/~HALT: J8.1; also elsewhere on the board
/~IRQ1: U1.20 (~INT1); also elsewhere on the board
/~NMI: U1.17 (P32/~INT2); also elsewhere on the board
/~RST: U1.25 (~RST); also elsewhere on the board
GND: C1.2, J1.1, JP1.1 (A), U1.29 (GND), U1.65 (GND); also elsewhere on the board
unnamed: J2.1, R1.2
unnamed 66: J3.1; also elsewhere on the board
unnamed 67: J4.1; also elsewhere on the board
unnamed 68: J6.1; also elsewhere on the board
unnamed: JP1.2 (C), R1.1, U1.24 (CNVSS)

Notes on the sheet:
CNVSS to GND: Software Select Mode, CNVSS to Vcc: Microprocessor Mode, CNVSS 10V: EVA Mode.



Board: 2 copper layers, 72.5 x 50.5 mm, 12 parts (3 on the bottom side), 69 nets.

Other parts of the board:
U3: MC6802; DIP-40_W15.24mm

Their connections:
+5V: U3.8 (VCC); also elsewhere on the board
/A0: U3.9 (A0); also elsewhere on the board
/A1: U3.10 (A1); also elsewhere on the board
/A2: U3.11 (A2); also elsewhere on the board
/A3: U3.12 (A3); also elsewhere on the board
/A4: U3.13 (A4); also elsewhere on the board
/A5: U3.14 (A5); also elsewhere on the board
/A6: U3.15 (A6); also elsewhere on the board
/A7: U3.16 (A7); also elsewhere on the board
/A8: U3.17 (A8); also elsewhere on the board
/A9: U3.18 (A9); also elsewhere on the board
/A10: U3.19 (A10); also elsewhere on the board
/A11: U3.20 (A11); also elsewhere on the board
/A12: U3.22 (A12); also elsewhere on the board
/A13: U3.23 (A13); also elsewhere on the board
/A14: U3.24 (A14); also elsewhere on the board
/A15: U3.25 (A15); also elsewhere on the board
/BA: U3.7 (BA); also elsewhere on the board
/CPUCLK: U3.39 (EXTAL); also elsewhere on the board
/D0: U3.33 (D0); also elsewhere on the board
/D1: U3.32 (D1); also elsewhere on the board
/D2: U3.31 (D2); also elsewhere on the board
/D3: U3.30 (D3); also elsewhere on the board
/D4: U3.29 (D4); also elsewhere on the board
/D5: U3.28 (D5); also elsewhere on the board
/D6: U3.27 (D6); also elsewhere on the board
/D7: U3.26 (D7); also elsewhere on the board
/PHI2: U3.37 (E); also elsewhere on the board
/R/~W: U3.34 (R/~W); also elsewhere on the board
/~HALT: U3.2 (~HALT); also elsewhere on the board
/~IRQ1: U3.4 (~IRQ); also elsewhere on the board
/~NMI: U3.6 (~NMI); also elsewhere on the board
/~RST: U3.40 (~RESET); also elsewhere on the board
GND: U3.1 (VSS), U3.21 (VSS), U3.38 (XTAL); also elsewhere on the board
unnamed 66: U3.3 (MR); also elsewhere on the board
unnamed 67: U3.36 (RE); also elsewhere on the board
unnamed 68: U3.5 (VMA); also elsewhere on the board

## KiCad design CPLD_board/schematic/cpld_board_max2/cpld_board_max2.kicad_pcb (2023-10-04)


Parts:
C1, C2, C3, C4: 100n; C_1206_3216Metric
D1, D2: RED; LED_D3.0mm
H1, H2, H3, H4, H5, H6, H7, H8: MountinSREDole; MountingHole_3.2mm_M3
J1, J2: BUS-Master; PinSocket_2x20_P2.54mm_Vertical
J3, J4: BUS-Master-BO; PinSocket_2x20_P2.54mm_Vertical
J5: BUS-AnHSYNCed; PinHeader_2x20_P2.54mm_Horizontal
J6: STM32F401; DIP-40_W15.24mm_Socket_LongPads
J7: Micro_SD_Card_Det2; microSD_HC_Hirose_DM3D-SF
J8: USB_A_Molex_67643; USB_A_Molex_67643_Horizontal
J9: Raspberry_Pi_2_3; Raspberry_Pi_Zero_Socketed_THT_FaceDown_MountingHoles
J10: GND; PinHeader_2x03_P2.54mm_Vertical
J11, J15: Conn_01x02; PinHeader_1x02_P2.54mm_Vertical
J12: RX_TX; PinHeader_1x02_P2.54mm_Vertical
J13: Conn_02x05_Odd_Even; PinHeader_2x05_P2.54mm_Vertical
J14, J16, J17, J18, J19, J20, J21, J22, J23, J24, J25, J26, J27, J28, J29: .; PinHeader_1x01_P2.00mm_Vertical
JP1: Jumper_3_Bridged12; SolderJumper-3_P1.3mm_Bridged12_RoundedPad1.0x1.5mm
R1, R2, R3: 10k; R_1206_3216Metric_Pad1.30x1.75mm_HandSolder
R4, R5: 220E; R_1206_3216Metric_Pad1.30x1.75mm_HandSolder
SW1, SW2, SW3, SW4: SW_Push; SW_PUSH_6mm_H4.3mm
U1: ebay MAX II board; ebay-MAX_II_board
U2: 74HC245; SO-20_5.3x12.6mm_P1.27mm
U3: IS61LV256AL-10JL; SOIC-28W_7.5x17.9mm_P1.27mm

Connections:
+3V3: C1.1, C2.1, C3.1, J2.37, J2.38, J4.37, J4.38, J7.4 (VDD), J13.10, R1.1, R2.1, R3.1, U2.20 (VCC), U3.28 (Vcc)
+5V: C4.1, J1.1, J1.2, J2.1, J2.2, J3.1, J3.2, J4.1, J4.2, J6.40, J8.1 (VBUS), J9.2 (5V), J9.4 (5V), U1.101 (5V)
/3V3: J6.20
/3V3_2: J6.38
/5V: J6.18
/73: J6.27, J9.21 (MISO0/GPIO9), U1.73 (IO2_73)
/74: U1.74 (IO2_74), U3.17 (D5)
/75: J6.26, J9.19 (MOSI0/GPIO10), U1.75 (IO2_75)
/A0: J1.19, J3.19, U1.98 (IO2_98)
/A0s: J5.19, U1.29 (IO1_29), U3.16 (D4)
/A1: J1.20, J3.20, U1.97 (IO2_97)
/A1s: J5.20, U1.35 (IO1_35), U3.15 (D3)
/A2: J1.21, J3.21, U1.100 (IO2_100)
/A2s: J5.21, U1.27 (IO1_27), U3.12 (D1)
/A3: J1.22, J3.22, U1.99 (IO2_99)
/A3s: J5.22, U1.28 (IO1_28), U3.13 (D2)
/A4: J1.23, J3.23, U1.43 (IO1_43/DEV_OE)
/A4s: J5.23, U1.21 (IO1_21), U3.10 (A0)
/A5: J1.24, J3.24, U1.42 (IO1_42)
/A5s: J5.24, U1.26 (IO1_26), U3.11 (D0)
/A6: J1.25, J3.25, U1.47 (IO1_47)
/A6s: J5.25, U1.19 (IO1_19), U3.9 (A1)
/A7: J1.26, J3.26, U1.44 (IO1_44/DEV_CLRn)
/A7s: J5.26, U1.20 (IO1_20), U3.8 (A2)
/A8: J1.27, J3.27, U1.49 (IO1_49)
/A8s: J5.27, U1.17 (IO1_17), U3.7 (A3)
/A9: J1.28, J3.28, U1.48 (IO1_48)
/A9s: J5.28, U1.18 (IO1_18), U3.6 (A4)
/A10: J1.29, J3.29, U1.51 (IO1_51)
/A10s: J5.29, U1.15 (IO1_15), U3.5 (A5)
/A11: J1.30, J3.30, U1.50 (IO1_50)
/A11s: J5.30, U1.16 (IO1_16), U3.4 (A6)
/A12: J1.31, J3.31, U1.53 (IO2_53)
/A12s: J5.31, U1.7 (IO1_7), U3.3 (A7)
/A13: J1.32, J3.32, U1.52 (IO2_52)
/A13s: J5.32, U1.8 (IO1_8), U3.25 (A8)
/A14: J1.33, J3.33, U1.40 (IO1_40)
/A14s: J5.33, U1.5 (IO1_5), U3.24 (A9)
/A15: J1.34, J3.34, U1.41 (IO1_41)
/A15s: J5.34, U1.6 (IO1_6), U3.21 (A10)
/A16: J1.35, J3.35, U1.38 (IO1_38)
/A16s: J5.35, U1.3 (IO1_3), U3.23 (A11)
/A17: J1.36, J3.36, U1.39 (IO1_39)
/A17s: J5.36, U1.4 (IO1_4), U3.2 (A12)
/A18: J1.37, J3.37, U1.36 (IO1_36)
/A18s: J5.37, U1.1 (IO2_1), U3.26 (A13)
/A19: J1.38, J3.38, U1.37 (IO1_37)
/A19s: J5.38, U1.2 (IO1_2), U3.1 (A14)
/B0: J6.34, J9.31 (GCLK2/GPIO6), U1.58 (IO2_58)
/B1: J6.35, J9.33 (PWM1/GPIO13), U1.57 (IO2_57)
/B2: J6.36, J9.38 (GPIO20/MOSI1), U1.56 (IO2_56)
/B3: J6.11, J22.1
/B4: J6.12, J23.1
/B5: J6.13, J24.1
/B8: J6.16, J27.1
/B9: J6.17, J28.1
/B10: J6.37, J9.40 (GPIO21/SCLK1), U1.55 (IO2_55)
/BLU: J6.24, J9.18 (GPIO24), U1.76 (IO2_76), U2.18 (B0)
/BLU#: J13.9, U2.2 (A0)
/C13: J6.22, J9.16 (GPIO23), J14.1
/C14: J6.23, J9.15 (GPIO22), J16.1
/CLKF: J2.14, J4.14, U1.62 (IO2_62/GCLK2)
/CLKS: J2.13, J4.13, JP1.3 (B)
/D0: J1.10, J3.10, U1.88 (IO2_88)
/D1: J1.11, J3.11, U1.87 (IO2_87)
/D2: J1.12, J3.12, U1.90 (IO2_90)
/D3: J1.13, J3.13, U1.89 (IO2_89)
/D4: J1.14, J3.14, U1.92 (IO2_92)
/D5: J1.15, J3.15, U1.91 (IO2_91)
/D6: J1.16, J3.16, U1.96 (IO2_96)
/D7: J1.17, J3.17, U1.95 (IO2_95)
/DET_SD: J6.5, J7.9 (DET_B)
/GP16: J9.36 (GPIO16), R1.2, SW1.2
/GP19: J9.35 (GPIO19/MISO1), R3.2, SW3.2
/GP25: D1.2 (A), J9.22 (GPIO25)
/GP26: J9.37 (GPIO26), R2.2, SW2.2
/GP27: D2.2 (A), J9.13 (GPIO27)
/GRN: J9.11 (GPIO17), U1.77 (IO2_77), U2.16 (B2)
/GRN#: J13.7, U2.4 (A2)
/HSYNC: J9.10 (GPIO15/RXD), J12.1, U1.82 (IO2_82), U2.15 (B3)
/HSYNC#: J13.6, U2.5 (A3)
/MISO_SD: J6.3, J7.7 (DAT0)
/MOSI: J2.30, J4.30
/MOSI_SD: J6.4, J7.3 (CMD)
/OUT/~IN: J15.1, U1.30 (IO1_30), U3.27 (~WE)
/PH0: J2.11, J4.11, U1.64 (IO2_64/GCLK3)
/PHI1_e: J1.3, J3.3
/PHI2_e: J1.4, J3.4, U1.70 (IO2_70)
/Q0: J9.3 (SDA/GPIO2), U1.86 (IO2_86), U2.11 (B7)
/Q1: J9.5 (SCL/GPIO3), U1.83 (IO2_83), U2.12 (B6)
/Q2: J9.7 (GCLK0/GPIO4), U1.84 (IO2_84), U2.13 (B5)
/Q3: J6.32, J9.29 (GCLK1/GPIO5), U1.66 (IO2_66)
/Q5: J9.26 (~CE1/GPIO7), U1.69 (IO2_69)
/Q6: J9.24 (~CE0/GPIO8), U1.72 (IO2_72)
/Q9: J9.23 (SCLK0/GPIO11), U1.71 (IO2_71)
/Q10: J6.33, J9.32 (PWM0/GPIO12), U1.61 (IO2_61)
/RD6: JP1.1 (A), U3.18 (D6)
/RED: J9.8 (GPIO14/TXD), J12.2, U1.81 (IO2_81), U2.14 (B4)
/RED#: J13.5, U2.6 (A4)
/RES0: J2.7, J4.7
/RES1: J2.9, J4.9
/RX: J6.29, J21.1; also elsewhere on the board
/RX2: J2.4, J4.4
/RX3: J2.6, J4.6
/RX_3V: J2.10, J4.10
/R/~W_e: J1.6, J3.6, U1.85 (IO2_85)
/R/~W_s: J5.6, U1.33 (IO1_33), U3.19 (D7)
/SBLU#: J13.4, U2.7 (A5)
/SCK: J2.31, J4.31
/SCK_SD: J6.2, J7.5 (CLK)
/SCL: J6.14, J25.1
/SDA: J6.15, J26.1
/SGRN#: J13.2, U2.9 (A7)
/SPDAT: J6.31, J9.27 (ID_SD/GPIO0), U1.67 (IO2_67)
/SPEN: J6.30, J9.28 (ID_SC/GPIO1), U1.68 (IO2_68)
/SRED#: J13.3, U2.8 (A6)
/TCK: J2.35, J4.35
/TDI: J2.36, J4.36
/TDO: J2.34, J4.34
/TDRTN: J2.32, J4.32
/TMS: J2.33, J4.33
/TX: J6.28, J18.1
/TX2: J2.3, J4.3
/TX3: J2.5, J4.5
/TX_3V: J2.8, J4.8
/VB: J6.21
/VSYNC: J9.12 (GPIO18/PWM0), U1.78 (IO2_78), U2.17 (B1)
/VSYNC#: J13.8, U2.3 (A1)
/uA9: J6.6, J17.1
/uA10: J6.7, J19.1
/uA11: J6.8, J8.2 (D-)
/uA12: J6.9, J8.3 (D+)
/uA15: J6.10, J20.1
/~BUSFREE: J2.15, J4.15
/~CS_SD: J6.1, J7.2 (DAT3/CD)
/~CS_ext: J15.2, U1.34 (IO1_34), U3.22 (~OE)
/~IORD: J1.5, J3.5
/~IOWR: J1.9, J3.9
/~MRD: J1.7, J3.7
/~MWR: J1.8, J3.8
/~PH0: J2.12, J4.12
/~RAMWE0: J2.29, J4.29
/~RAMWE1: J2.28, J4.28
/~RAMWE2: J2.27, J4.27
/~RAMWE3: J2.26, J4.26
/~RAMWE4: J2.25, J4.25
/~RAMWE5: J2.24, J4.24
/~RAMWE6: J2.23, J4.23
/~RAMWE7: J2.22, J4.22
/~RAMWE8: J2.21, J4.21
/~RAMWE9: J2.20, J4.20
/~RAMWE10: J2.19, J4.19
/~RAMWE11: J2.18, J4.18
/~RAMWE12: J2.17, J4.17
/~RAMWE13: J2.16, J4.16
/~RST: J1.18, J3.18, U1.54 (IO2_54)
/~STMRST: J6.25
GND: C1.2, C2.2, C3.2, C4.2, J1.39, J1.40, J2.39, J2.40, J3.39, J3.40, J4.39, J4.40, J5.39, J5.40, J6.19, J6.39, J7.6 (VSS), J7.10 (DET_A), J7.11 (SHIELD), J8.4 (GND), J8.5 (Shield), J9.6 (GND), J9.9 (GND), J9.14 (GND), J9.20 (GND), J9.25 (GND), J9.30 (GND), J9.34 (GND), J9.39 (GND), J10.1, J10.2, J10.3, J10.4, J10.5, J10.6, J13.1, J29.1, R4.2, R5.2, SW1.1, SW2.1, SW3.1, U1.10 (GND), U1.11 (GND), U1.65 (GND), U2.1 (A->B), U2.10 (GND), U2.19 (CE), U3.14 (GND), U3.20 (~CE)
unnamed: D1.1 (K), R4.1
unnamed: D2.1 (K), R5.1
unnamed: J11.1, SW4.1
unnamed: J11.2, SW4.2
unnamed: JP1.2 (C), U1.14 (IO1_14/GCLK1)

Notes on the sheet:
OUT
USB+
STM32F401 microcontroller
B1 B0
CGA/EGA Pin: 5 4 3 2 1
A7 A6 A5 A4 A3 A2 A1 A0
B6 (SCL) B7 (SDA) B8
CGA/EGA Pin: - 9 8 7 6
B12 B13 B14 B15
A8 A9
C15 C14 C13
USB-
B10 (B11 on F103) B2 (B10 on F103)
A10 A11 A12 A15

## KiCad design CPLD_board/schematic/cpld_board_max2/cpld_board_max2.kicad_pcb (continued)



Board: 2 copper layers, 100.0 x 100.0 mm, 56 parts (15 on the bottom side), 158 nets.

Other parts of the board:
locked: .; PinHeader_1x01_P2.00mm_Vertical

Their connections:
/RX: locked.1; also elsewhere on the board

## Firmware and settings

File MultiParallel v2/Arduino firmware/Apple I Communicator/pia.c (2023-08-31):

/*
    PIA Communicator from RC6502
    https://github.com/tebl/RC6502-Apple-1-Replica
    
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
    You should have received a copy of the GNU General Public License
    along with this program.  If not, see <https://www.gnu.org/licenses/>.
*/
#include <avr/interrupt.h>
#include <stdio.h>
#include <stdlib.h>
#include <avr/io.h>
#include <util/delay.h>
#include <avr/sfr_defs.h>
#include "uart.h"

#define BAUD 115200

// VT100 codes (used for cursor and text color implementation)
#define VT100_OFF           "\033[0m"     // Disable formatting
#define VT100_DEFAULT       "\033[32m"    // Color green
#define VT100_BLINK         "\033[5;32m"  // Blink color green
#define VT100_BOLD          "\033[1;32m"  // Bold color green
#define VT100_CLS           "\033[2J"     // Clear screen
#define VT100_RESET_CURSOR  "\033[H"      // Position cursor in top left corner
#define VT100_CURSOR_LEFT   "\033[1D"     // Move cursor one column to the left
#define VT100_ERASE_EOL     "\033[K"      // Erase from cursor until end of line
#define CURSOR_CHAR   "@"

// Port definitions (Arduino pins connected to the PIA)
// PIN_PA3 8     // PB0 - out
// PIN_PA4 9     // PB1 - out
// PIN_PA5 10    // PB2 - out
// PIN_PA6 11    // PB3 - out
// PIN_STROBE 12 // PB4 - out
// PIN_RST 13    // PB5 - out
// or KBD_RDY    // PB5
// PIN_DA  A0    // PC0
// PIN_RDA A1    // PC1 - out
// PIN_PB6 A2    // PC2
// PIN_PB5 A3    // PC3
// PIN_PB4 A4    // PC4
// PIN_PB3 A5    // PC5
// TX            // PD0 - out
// RX            // PD1
// PIN_PB0 2     // PD2
// PIN_PB1 3     // PD3
// PIN_PB2 4     // PD4
// PIN_PA0 5     // PD5 - out
// PIN_PA1 6     // PD6 - out
// PIN_PA2 7     // PD7 - out

#define SET_PA0  (PORTD |= (1 << 5))
#define CLR_PA0 (PORTD &= ~(1 << 5))
#define SET_PA1  (PORTD |= (1 << 6))
#define CLR_PA1 (PORTD &= ~(1 << 6))
#define SET_PA2  (PORTD |= (1 << 7))
#define CLR_PA2 (PORTD &= ~(1 << 7))
#define SET_PA3  (PORTB |= (1 << 0))
#define CLR_PA3 (PORTB &= ~(1 << 0))
#define SET_PA4  (PORTB |= (1 << 1))
#define CLR_PA4 (PORTB &= ~(1 << 1))
#define SET_PA5  (PORTB |= (1 << 2))
#define CLR_PA5 (PORTB &= ~(1 << 2))
#define SET_PA6  (PORTB |= (1 << 3))
#define CLR_PA6 (PORTB &= ~(1 << 3))

#define GET_PB0 (PIND & ( 1 << 2))
#define GET_PB1 (PIND & ( 1 << 3))
#define GET_PB2 (PIND & ( 1 << 4))
#define GET_PB3 (PINC & ( 1 << 5))
#define GET_PB4 (PINC & ( 1 << 4))
#define GET_PB5 (PINC & ( 1 << 3))
#define GET_PB6 (PINC & ( 1 << 2))

#define RST_HI PORTB |= (1 << 5)
#define RST_LO PORTB &= ~(1 << 5)
#define KBD_STROBE_LO PORTB &= ~(1 << 4)
#define KBD_STROBE_HI PORTB |= (1 << 4)
#define VIDEO_RDA_LO PORTC &= ~(1 << 1)
#define VIDEO_RDA_HI PORTC |= (1 << 1)
#define GET_KBD_READY (PINB & (1 << 5))
#define GET_VIDEO_DA (PINC & (1 << 0))

#define KBD_INTERRUPT_ENABLE 0
#define KBD_SEND_TIMEOUT 23

uint8_t cursor_visible = 0;

void show_cursor();
void hide_cursor();
void process_video_data();

void pia_init(void){
#if KBD_INTERRUPT_ENABLE == 1 
  DDRB = 0x1F;   // PB0..5 Output for KBD_RDY on PB5
#else
  DDRB = 0x3F;   // PB0..5 Output for Reset on PB5
#endif
  DDRC = 2;      // PC1 Output
  DDRD = 0xE1;   // PD0,5..7 Output
  uart_init(BAUD);
  //uart_putc('!');
  //uart_puts("\r\nThis is the Second uart\r\n");
  uart_puts_p(PSTR(VT100_CLS));
  uart_puts_p(PSTR(VT100_RESET_CURSOR));
  uart_puts_p(PSTR(VT100_OFF));
  uart_puts_p(PSTR(VT100_DEFAULT));
  uart_puts_p(PSTR("+------------------------+\r\n"));
  uart_puts_p(PSTR("|      "));
  uart_puts_p(PSTR(VT100_OFF));
  uart_puts_p(PSTR(VT100_BOLD));
  uart_puts_p(PSTR("APPLE 1 MINI"));
  uart_puts_p(PSTR(VT100_OFF));
  uart_puts_p(PSTR(VT100_DEFAULT));
  uart_puts_p(PSTR("      |\r\n"));
  uart_puts_p(PSTR(VT100_OFF));
  uart_puts_p(PSTR(VT100_DEFAULT));
  uart_puts_p(PSTR("|------------------------|\r\n"));
  uart_puts_p(PSTR("| FIRMWARE VERSION 2.0   |\r\n"));
  uart_puts_p(PSTR("| RUUD VAN FALIER, 2017  |\r\n"));
  uart_puts_p(PSTR("| ROBERT OFFNER, 2022    |\r\n"));
  uart_puts_p(PSTR("+------------------------+\r\n"));
  uart_puts_p(PSTR("\r\n"));
  uart_puts_p(PSTR("READY...\r\n"));
  uart_puts_p(PSTR("\r\n"));
  uart_puts_p(PSTR(VT100_OFF));  
  show_cursor();  
#if KBD_INTERRUPT_ENABLE == 0
  RST_LO;
#endif
}

char map_to_ascii(int c){
  /* Convert ESC key */
  if (c == 203) c = 27;
  /* Ctrl A-Z */
  if (c > 576 && c < 603) c -= 576;
  /* Convert lowercase keys to UPPERCASE */
  if (c > 96 && c < 123) c -= 32;
  return c;
}

void pia_send(uint8_t c){
  /* Make sure STROBE signal is off */
  KBD_STROBE_LO;
  c = map_to_ascii(c);
  /* Output the actual keys as long as it's supported */
  if (c < 96){
    (c & 1)?SET_PA0:CLR_PA0;
    (c & 2)?SET_PA1:CLR_PA1;
    (c & 4)?SET_PA2:CLR_PA2;
    (c & 8)?SET_PA3:CLR_PA3;
    (c & 0x10)?SET_PA4:CLR_PA4;
    (c & 0x20)?SET_PA5:CLR_PA5;
    (c & 0x40)?SET_PA6:CLR_PA6;

    KBD_STROBE_HI;
    _delay_us(1);
    if (KBD_INTERRUPT_ENABLE){
      uint8_t timeout;

      /* Wait for KBD_READY (CA2) to go HIGH */
      timeout = KBD_SEND_TIMEOUT;
      while(GET_KBD_READY == 0){
        if (timeout == 0) break;
        else timeout--;
      }
      KBD_STROBE_LO;

      /* Wait for KBD_READY (CA2) to go LOW */
      timeout = KBD_SEND_TIMEOUT;
      while(GET_KBD_READY != 0){
        if (timeout == 0) break;
        else timeout--;
      }
    } else {
      KBD_STROBE_LO;
    }
  }
  process_video_data();
}

void process_serial_data(){
  if (uart_test() > 0) {
    uint8_t c = uart_getc();
    pia_send(c);
  }
  //process_video_data();
}

char send_ascii(char c){
  switch (c) {
    case '\r': uart_putc('\n'); /* Replace CR with LF */
    default:
      uart_putc(c);
  }
}
uint8_t read_video_data(void){
  uint8_t ret;
  ret = ((PIND & 0x1C) >> 2);
//  ret |= GET_PB0?1:0;
//  ret |= GET_PB1?2:0;
//  ret |= GET_PB2?4:0;
  ret |= GET_PB3?8:0;
  ret |= GET_PB4?0x10:0;
  ret |= GET_PB5?0x20:0;
  ret |= GET_PB6?0x40:0;
  //(PINC & 0x3C)
  return ret;
}

void process_video_data(){
  if (GET_VIDEO_DA){
    char c = read_video_data();
    VIDEO_RDA_LO;
    _delay_us(1);
    VIDEO_RDA_HI;
    
    if (c == 13){
      hide_cursor();
      uart_puts_p(PSTR("\r\n"));
    } 
    else if (c > 31){
      hide_cursor();
      uart_puts_p(PSTR(VT100_DEFAULT));
      //send_ascii(c);
      uart_putc(c);
      uart_puts_p(PSTR(VT100_OFF));
    }
    show_cursor();
  }
}

/*
 * Remove the cursor character from the screen by sending a backspace.
 */
void hide_cursor(){
  if (cursor_visible)  {
    uart_puts_p(PSTR(VT100_CURSOR_LEFT));
    uart_puts_p(PSTR(VT100_ERASE_EOL));
    cursor_visible = 0;
  }
}

/*
 * Display blinking cursor character.
 */
void show_cursor(){
  if (!cursor_visible)  {
    uart_puts_p(PSTR(VT100_BLINK));
    uart_puts_p(PSTR(CURSOR_CHAR));
    uart_puts_p(PSTR(VT100_OFF));
    cursor_visible = 1;
  }
}

int main(void){
    pia_init();
   // _delay_ms(20);
#if KBD_INTERRUPT_ENABLE == 0
  RST_HI;
#endif    
    while(1){
        process_video_data();
        process_serial_data();
    }
}

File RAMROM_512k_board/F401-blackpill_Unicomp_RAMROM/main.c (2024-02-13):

/*
    ChibiOS - Copyright (C) 2006..2018 Giovanni Di Sirio

    Licensed under the Apache License, Version 2.0 (the "License");
    you may not use this file except in compliance with the License.
    You may obtain a copy of the License at

        http://www.apache.org/licenses/LICENSE-2.0

    Unless required by applicable law or agreed to in writing, software
    distributed under the License is distributed on an "AS IS" BASIS,
    WITHOUT WARRANTIES OR CONDITIONS OF ANY KIND, either express or implied.
    See the License for the specific language governing permissions and
    limitations under the License.
*/
#include "main.h"
#include "ch.h"
#include "hal.h"
#include <string.h>
#include <stdlib.h>
#include "portab.h"
#include "shell.h"
#include "chprintf.h"

#include "SPI.h"
#include "i2c.h"
#include "usbcfg.h"
#include "ostrich.h"
#include "comm.h"
#include "mypwm.h"

//#define usb_lld_connect_bus(usbp)
//#define usb_lld_disconnect_bus(usbp)

extern THD_WORKING_AREA(waCharacterInputThread, 128);
extern THD_FUNCTION(CharacterInputThread, arg);
//uint8_t buffer[256];

/*===========================================================================*/
/* Command line related.                                                     */
/*===========================================================================*/
BaseSequentialStream *const shell = (BaseSequentialStream *)&SHELLPORT;
BaseSequentialStream *const ost = (BaseSequentialStream *)&OSTRICHPORT;
BaseSequentialStream *const dbg = (BaseSequentialStream *)&DEBUGPORT;

#define SHELL_WA_SIZE   THD_WORKING_AREA_SIZE(2048)

char history_buffer[8*64];
char *completion_buffer[SHELL_MAX_COMPLETIONS];

static const ShellCommand commands[] = {
  {"wb", cmd_wb},
  {"fill", cmd_fill},
  {"rb", cmd_rb},
  {"br", cmd_br},
  {"spi",cmd_spi},
  {"wc", cmd_wc},
  {"test",cmd_test},
  {"freq", cmd_change_freq},
  {"dc", cmd_change_pw4},
  {NULL, NULL}
};
static const ShellConfig shell_cfg1 = {
  (BaseSequentialStream *)&SHELLPORT,
  commands,
  history_buffer,
  sizeof(history_buffer),
  completion_buffer
};

//static const ShellCommand commands[] = {
//  {"test", cmd_test},
//  {NULL, NULL}
//};
//
//static const ShellConfig shell_cfg1 = {
//  (BaseSequentialStream *)&SHELLPORT,
//  commands
//};

/*
 * Green LED blinker thread, times are in milliseconds.
 */
//static THD_WORKING_AREA(waThread1, 128);
//static THD_FUNCTION(Thread1, arg) {
//
//  (void)arg;
//  chRegSetThreadName("blinker");
//  while (true) {
//    //palClearPad(GPIOA, 6);
//    chThdSleepMilliseconds(500);
//    //palSetPad(GPIOA, 6);
//    chThdSleepMilliseconds(500);
//  }
//}

/*
 * Application entry point.
 */
int main(void) {
  thread_t *shelltp = NULL;
  event_listener_t shell_el;

  /*
   * System initializations.
   * - HAL initialization, this also initializes the configured device drivers
   *   and performs the board-specific initializations.
   * - Kernel initialization, the main() function becomes a thread and the
   *   RTOS is active.
   */
  halInit();
  chSysInit();

  //PA2(TX) and PA3(RX) are routed to USART2
  SerialConfig serial_config6 = {
      //115200,
      115200,
      0,
      0,
      0
  };

  sdStart(&SHELLPORT, &serial_config6);
  palSetPadMode(GPIOA, 2, PAL_MODE_ALTERNATE(7));
  palSetPadMode(GPIOA, 3, PAL_MODE_ALTERNATE(7));

  chprintf(dbg, "\r\nNVRAM Programmer: %i.%i \r\nSystem started. (Shell)\r\n", VMAJOR, VMINOR);
  //chprintf(ost, "\r\nNVRAM Programmer: %i.%i \r\nSystem started. (Ostrich)\r\nTest with 'VV' - should return 'N'", VMAJOR, VMINOR);

//  #ifdef OSTRICHUSB
  sduObjectInit(&OSTRICHPORT);
  sduStart(&OSTRICHPORT, &serusbcfg1);
//  palSetPadMode(GPIOA, 11, PAL_MODE_ALTERNATE(10));
//  palSetPadMode(GPIOA, 12, PAL_MODE_ALTERNATE(10));

  usbDisconnectBus(serusbcfg1.usbp);
  chThdSleepMilliseconds(1500);
  usbStart(serusbcfg1.usbp, &usbcfg);
  usbConnectBus(serusbcfg1.usbp);

//  #else
//  SerialConfig serial_config2 = {
//      115200,
//      0,
//      0,
//      0
//  };
//  sdStart(&SD2, &serial_config2);
//  palSetPadMode(GPIOA, 2, PAL_MODE_ALTERNATE(7));
//  palSetPadMode(GPIOA, 3, PAL_MODE_ALTERNATE(7));
//  #endif
  mypwmInit();
  SPI_init();
  i2c_init();
  start_ostrich_thread();
  /*
   * Shell manager initialization.
   * Event zero is shell exit.
   */
  shellInit();
  chEvtRegister(&shell_terminated, &shell_el, 0);

  /*
   * Normal main() thread activity, in this demo it does nothing except
   * sleeping in a loop and check the button state.
   */
  while (true) {
#if USB_SHELL == 1
    if (SHELLPORT.config->usbp->state == USB_ACTIVE) {
      /* Starting shells.*/
      if (shelltp == NULL) {
        shelltp = chThdCreateFromHeap(NULL, SHELL_WA_SIZE,
                                       "shell1", NORMALPRIO + 1,
                                       shellThread, (void *)&shell_cfg1);
      }
#else
    if (!shelltp)
      shelltp = chThdCreateFromHeap(NULL, SHELL_WA_SIZE,
                                    "shell", NORMALPRIO + 1,
                                    shellThread, (void *)&shell_cfg1);
    else if (chThdTerminatedX(shelltp)) {
      chThdRelease(shelltp);    /* Recovers memory of the previous shell.   */
      shelltp = NULL;           /* Triggers spawning of a new shell.        */
    }
#endif
    /* Waiting for an exit event then freeing terminated shells.*/
    chEvtWaitAny(EVENT_MASK(0));
    if (chThdTerminatedX(shelltp)) {
      chThdRelease(shelltp);
      shelltp = NULL;
    }
  }
  chThdSleepMilliseconds(1000);
//  palTogglePad(GPIOA, 5);
}

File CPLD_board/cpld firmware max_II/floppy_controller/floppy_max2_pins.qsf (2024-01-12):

# Pin definitions for external RAM (with As)
set_location_assignment PIN_1   -to As[18]
set_location_assignment PIN_2   -to As[19]
set_location_assignment PIN_3   -to As[16]
set_location_assignment PIN_4   -to As[17]
set_location_assignment PIN_5   -to As[14]
set_location_assignment PIN_6   -to As[15]
set_location_assignment PIN_7   -to As[12]
set_location_assignment PIN_8   -to As[13]
set_location_assignment PIN_12  -to clk50
set_location_assignment PIN_14  -to clks_rd6
set_location_assignment PIN_15  -to As[10]
set_location_assignment PIN_16  -to As[11]
set_location_assignment PIN_17  -to As[8]
set_location_assignment PIN_18  -to As[9]
set_location_assignment PIN_19  -to As[6]
set_location_assignment PIN_20  -to As[7]
set_location_assignment PIN_21  -to As[4]
set_location_assignment PIN_26  -to As[5]
set_location_assignment PIN_27  -to As[2]
set_location_assignment PIN_28  -to As[3]
set_location_assignment PIN_29  -to As[0]
set_location_assignment PIN_30  -to OUTnIN
set_location_assignment PIN_33  -to RnWout
set_location_assignment PIN_34  -to nCSext
set_location_assignment PIN_35  -to As[1]
set_location_assignment PIN_36  -to A[18]
set_location_assignment PIN_37  -to A[19]
set_location_assignment PIN_38  -to A[16]
set_location_assignment PIN_39  -to A[17]
set_location_assignment PIN_40  -to A[14]
set_location_assignment PIN_41  -to A[15]
set_location_assignment PIN_42  -to A[5]
set_location_assignment PIN_43  -to A[4]
set_location_assignment PIN_44  -to A[7]
set_location_assignment PIN_47  -to A[6]
set_location_assignment PIN_48  -to A[9]
set_location_assignment PIN_49  -to A[8]
set_location_assignment PIN_50  -to A[11]
set_location_assignment PIN_51  -to A[10]
set_location_assignment PIN_52  -to A[13]
set_location_assignment PIN_53  -to A[12]
set_location_assignment PIN_54  -to nRST
set_location_assignment PIN_55  -to B10
set_location_assignment PIN_56  -to B2
set_location_assignment PIN_57  -to stmWD_S
set_location_assignment PIN_58  -to stmDRQ
set_location_assignment PIN_61  -to uMOSI
set_location_assignment PIN_62  -to clkf
set_location_assignment PIN_64  -to ph0
set_location_assignment PIN_66  -to uMISO
set_location_assignment PIN_67  -to uSCK
set_location_assignment PIN_68  -to nCSCPLD
set_location_assignment PIN_69  -to Q5
set_location_assignment PIN_70  -to ph2
set_location_assignment PIN_71  -to Q9
set_location_assignment PIN_72  -to Q6
set_location_assignment PIN_73  -to uRnW
set_location_assignment PIN_74  -to pin74
set_location_assignment PIN_75  -to ucBSY
set_location_assignment PIN_76  -to BLU
set_location_assignment PIN_77  -to GRN
set_location_assignment PIN_78  -to VSYNC
set_location_assignment PIN_81  -to RED
set_location_assignment PIN_82  -to HSYNC
set_location_assignment PIN_83  -to SRED
set_location_assignment PIN_84  -to SBLU
set_location_assignment PIN_85  -to RnWin
set_location_assignment PIN_86  -to SGRN
set_location_assignment PIN_87  -to Dio[1]
set_location_assignment PIN_88  -to Dio[0]
set_location_assignment PIN_89  -to Dio[3]
set_location_assignment PIN_90  -to Dio[2]
set_location_assignment PIN_91  -to Dio[5]
set_location_assignment PIN_92  -to Dio[4]
set_location_assignment PIN_95  -to Dio[7]
set_location_assignment PIN_96  -to Dio[6]
set_location_assignment PIN_97  -to A[1]
set_location_assignment PIN_98  -to A[0]
set_location_assignment PIN_99  -to A[3]
set_location_assignment PIN_100 -to A[2]

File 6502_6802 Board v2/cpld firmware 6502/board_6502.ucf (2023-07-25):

NET "MOSI"  LOC = "p5"  ;
NET "SCK"   LOC = "p6"  ;
NET "A[0]"   LOC = "p30"  ;
NET "A[1]"   LOC = "p29"  ;
NET "A[2]"  LOC = "p28"  ;
NET "A[3]"  LOC = "p27"  ;
NET "A[4]"  LOC = "p23"  ;
NET "A[5]"  LOC = "p22"  ;
NET "A[6]"  LOC = "p21"  ;
NET "A[7]"  LOC = "p20"  ;
NET "A[8]"   LOC = "p19"  ;
NET "A[9]"   LOC = "p18"  ;
NET "A[10]"  LOC = "p16"  ;
NET "A[11]"  LOC = "p14"  ;
NET "A[12]"  LOC = "p13"  ;
NET "A[13]"  LOC = "p12"  ;
NET "A[14]"  LOC = "p8"  ;
NET "A[15]"  LOC = "p7"  ;

NET "RES0"  LOC = "p40"  ;
NET "RES1"  LOC = "p41"  ;
NET "RES2"  LOC = "p42"  ;

NET "nML"      LOC = "p39"  ;
NET "nBUSFREE" LOC = "p43"  ;
NET "nRST"     LOC = "p44"  ;
NET "PH0"      LOC = "p1"  ;
NET "nPH0"     LOC = "p2"  ;
NET "CLKF"     LOC = "p3"  ;
NET "nDOE"     LOC = "p31"  ;
NET "nAOE"     LOC = "p32"  ;
NET "nMWR"     LOC = "p33"  ;
NET "nMRD"     LOC = "p34"  ;
NET "RnW"      LOC = "p36"  ;
NET "PHI2CPU"  LOC = "p37"  ;
NET "PHI1CPU"  LOC = "p38"  ;

# ; NET "GND" LOC = "p4"  ;
# ; NET "TDI" LOC = "p9"  ;
# ; NET "TMS" LOC = "p10" ;
# ; NET "TCK" LOC = "p11" ;
# ; NET "VCC" LOC = "p15" ;
# ; NET "GND" LOC = "p17" ;
# ; NET "TDO" LOC = "p24" ;
# ; NET "GND" LOC = "p25" ;
# ; NET "VCC" LOC = "p26" ;
# ; NET "VCC" LOC = "p35" ;

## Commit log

2023-07-25 Readme update
    [board_6502_pad.csv, project.cfg]
2023-08-01 python work
    [MOS MultiSerial_ram.kicad_sch, RAMROM_512k_board.kicad_pcb, RAMROM_512k_board.kicad_sch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]
2023-08-02 apple I test
    [apple1.cfg, bus.kicad_sch, proto.kicad_sch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]
2023-08-03 Apple I works, more Python work, uploadscripts for software done
    [MOS_MultiParallel_2.kicad_pcb, apple1.cfg, kim1.cfg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]
2023-08-04 SYM1 & KIM1 work, RAM Board update
    [EpromEMU_BOT-B_Cu.gbr, EpromEMU_BOT-B_Mask.gbr, EpromEMU_BOT-B_Paste.gbr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]
2023-08-04 MC6802 test
    [CPU6502_6802.kicad_pcb, board_6802_pad.csv, mek_d2.cfg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]
2023-08-05 c code change, MC6800 still not working
    [CPU6502_6802.kicad_sch, board_6802_pad.csv, mek_d2.cfg]
2023-08-06 Documentation update
    [CPU6502_6802.kicad_pcb, MOS MultiSerial_ram.kicad_sch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]
2023-08-08 Documentation update, 6800 working, new computers added
    [CPU6502_6802.kicad_sch, MOS MultiSerial_ram.kicad_sch, board_6802_pad.csv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]
2023-08-24 DREAM6800 video started
    [CPU6502_6802.kicad_pcb, CPU6502_6802.kicad_sch, board_6802_pad.csv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]
2023-08-27 DREAM6800 working with glitches
    [MOS_MultiParallel_2-B_Cu.gbr, MOS_MultiParallel_2-B_Mask.gbr, MOS_MultiParallel_2-B_Paste.gbr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]
2023-08-31 SWTPC6800 working
    [dream6800.cfg, mek_d2.cfg, swtpc6800.cfg]
2023-09-11 6809 Board done, Splitter Board new, RAMROM512k new
    [CPU_6809_board-B_Cu.gbr, CPU_6809_board-B_Mask.gbr, CPU_6809_board-B_Paste.gbr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]
2023-09-17 i2c in stm32 implemented, python script canged
    [6803_board-B_Cu.gbr, 6803_board-B_Mask.gbr, 6803_board-B_Paste.gbr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]
2023-10-04 olimex scripts updated
    [Moates Hardware Protocols v19.xls, swtpc6800.cfg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]
2024-01-12 MC3 Computer update
    [6303X_SDIP_Addon-B_Cu.gbr, 6303X_SDIP_Addon-B_Mask.gbr, 6303X_SDIP_Addon-B_Paste.gbr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]
2024-02-13 some work on the CPU Adapter Boards
    [6303X_FP64-B_Cu.gbr, 6303X_FP64-B_Mask.gbr, 6303X_FP64-B_Paste.gbr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]
2024-05-14 Z80 added
    [CPU6502_6802.kicad_sch, Zilog_MultiSerial.kicad_pcb, Zilog_MultiSerial.kicad_sch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]
2024-05-15 xsvf file creation added in 6502 board
    [board_6502_pad.csv]

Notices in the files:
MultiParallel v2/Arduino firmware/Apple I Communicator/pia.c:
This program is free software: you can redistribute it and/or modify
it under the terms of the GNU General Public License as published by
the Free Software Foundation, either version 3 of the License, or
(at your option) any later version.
